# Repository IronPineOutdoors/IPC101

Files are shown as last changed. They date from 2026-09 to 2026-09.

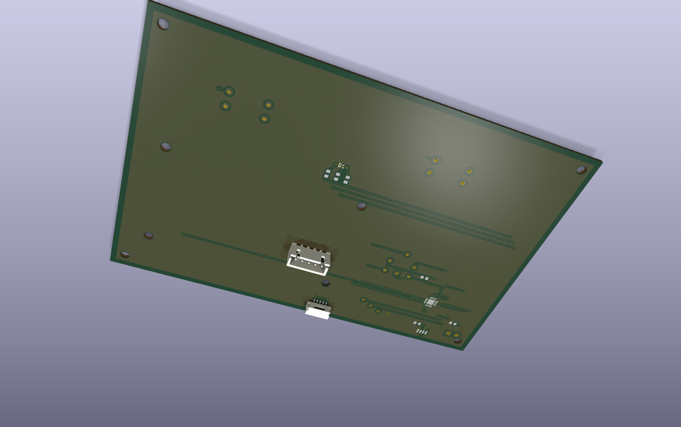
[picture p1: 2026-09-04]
hardware/kicad/IPC101_RevC_3D.png

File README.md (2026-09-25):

# Iron Pine Outdoors IPC-101

IPC-101 is a prototype operator-control-panel PCB for IPC-100. Revision P0 implements seven ordinary controls through a TCA8418 keypad scanner on IPC-100's protected 3.3 V J10 I2C expansion branch, physically carries the Hosyond 2.42-inch SSD1309 prototype display connected by a dedicated five-wire harness to IPC-100 J6, and carries the normally-closed STOP contact only on a separate J8A harness.

## Release state

**Rev C prototype fabrication package corrected for solder mask.** Use [IPC101_RevC_MaskFix_Gerbers.zip](hardware/fabrication/IPC101_RevC/IPC101_RevC_MaskFix_Gerbers.zip) and the existing Rev C BOM/CPL. The superseded package omitted through-hole solder-mask openings; the replacement contains verified top and bottom openings. Full KiCad DRC passes with 0 violations and 0 unconnected pads. See [order notes](hardware/fabrication/IPC101_RevC/ORDER_NOTES.md) and [verification results](hardware/fabrication/IPC101_RevC/MASK_FIX_VALIDATION.md).

The Rev C board is 150 x 100 mm. Physical control/display/faceplate fit remains a prototype acceptance check; the bare PCB has no ingress rating.

## Architecture

- START, PULL: Omron B3F-4055 12 mm through-hole tactile switches.
- Navigation: Adafruit 504 five-way through-hole switch (LEFT/RIGHT/UP/DOWN/SELECT).
- STOP: Omron A22NE-M-PD01-N, normally-closed contact, panel mounted; its two wires remain isolated from PCB logic and pass through dedicated connector J3.
- Key scanner: TI TCA8418RTWR at fixed I2C address `0x34`, polled by IPC-100; 7x1 matrix.
- Display: Hosyond 2.42-inch 128x64 I2C SSD1309 module (Amazon ASIN B0G2RFLG1L), mounted to the faceplate using the corrected Crosswind geometry and connected through IPC-101 J2/J4 to IPC-100 J6.
- IPC-100 ordinary-control link: J10, JST GH 4-pin, 3.3 V / 100 mA / 100 kHz I2C.

## Next-board planning

[IPC-101 Rev 2 planning notes](docs/requirements/IPC101_REV2_PLANNING.md) capture BME280 support, corrected 504 pin alignment, rear input-connector evaluation, direct PCB-mounted OLED, and complete silkscreen/board identification. This is a requirements backlog; current fabrication files are unchanged.

## Repository map

- `docs/` — controlled requirements, decisions, interfaces, mechanics, and test plan.
- `hardware/kicad/` — KiCad project, schematic, routed PCB, and project-local footprints.
- `hardware/bom/` — prototype BOM.
- `hardware/fabrication/` — release notes and generation instructions; verified Gerbers, drills, and assembly outputs are included.
- `mechanical/` — panel coordinate and cutout data.
- `manufacturing/` — assembly and inspection notes.

## Next action

Prepare for the incoming boards with the [Rev C arrival and first-power checklist](docs/testing/IPC101_REVC_ARRIVAL_CHECKLIST.md). It covers the actual order comparison, hand-installed parts, Rev D/Rev H mechanical fit, TPU coupons, harness verification, staged power-up, and result recording. Receipt and acceptance of the replacement manufacturing file must be confirmed against the order; the local package alone does not establish what was fabricated.

Upload the replacement Gerber ZIP to the held JLCPCB order and confirm both solder-mask layers in its viewer. Review assembly orientation before approving production, then fit-test and electrically validate the first prototype before connecting motion hardware.

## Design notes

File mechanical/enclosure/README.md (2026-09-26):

# IPC-101 enclosure - current Rev I.1 fit build

**Start with [PRINT THESE](PRINT_THESE.md).** The current build uses the rear-entry base and R4 roof. The guide records the export cleanup, retained CAD references and next LED tests.

[Current N1.4 faceplate: 8 mm P504 opening, compact tree + IPO and preview](faceplate/REV_N14_FACEPLATE.md).

- [Assembly order, hardware and fit measurements](structure/REV_I1_ASSEMBLY.md)
- [I1 structure/service preview with earlier faceplate](structure/RevI1_preview.png)
- [Measured R1 labeled caps (guide shows earlier N1.2 faceplate)](controls/buttons/R1_BUTTON_CAPS.md)
- [Tree traced from supplied wordmark and N1.2 reprint files](faceplate/history/REV_N12_FACEPLATE.md)
- [Current panel/cap preview](faceplate/N14_faceplate_preview.png)
- [N1 button alignment and tree correction basis](faceplate/history/REV_N1_FACEPLATE.md)
- [Historical M4 audit, superseded by physical misalignment report](faceplate/history/REV_M4_FIT_AUDIT.md)
- [Verification results](structure/RevI1_verification.json)
- [Received IDEC STOP switch and mounting measurements](controls/stop/side-pod/STOP_XA1E_BV302R.md)
- [Printable S1 STOP side pod, hardware and assembly](controls/stop/side-pod/STOP_S1_ASSEMBLY.md)
- [S1 STOP installation preview](controls/stop/side-pod/STOP_S1_preview.png)

Status: **TEST-FIT / PHYSICAL VALIDATION PENDING**. I.1 reuses the original R3 carrier and unchanged Rev H bracket/wiring plate. N1.4 uses measured ARM-left/PULL-right positions, compact traced tree + IPO, and an enlarged 8 mm P504 opening, with labels on R1 caps. Cradle dry fit and STOP coupon operation were reported successful; N1.4 directional travel, R1 cap operation, populated-board/harness, hardware and sealing checks remain.

## Current files versus history

Current I.1 parts, original R3, N1.4/R1 print files (earlier faceplates retained as history), and the authoritative Rev H mounting baseline are grouped by component in the subfolders below. **The Rev H and older I.1 box geometry are references.** Print the rear-entry base from the current guide when replacement is needed.

Superseded Rev G and Rev I exports, exploratory H/H1/H2 SCAD files, and their notes are under [archive](archive/README.md). They are retained for engineering history, not current printing. The earlier long README is preserved as [development history](archive/DEVELOPMENT_HISTORY.md).

Some older Python files remain in `tooling/` because the current build imports their geometry helpers, STL writer, or verification functions. Their presence does not make their old parts current:

- `generate_rev_h.py`: authoritative preserved mount geometry.
- `generate_crosswind_control_box.py`: shared STL writer; its historical Rev G command exports into the archive.
- `generate_rev_i.py`, `verify_rev_i.py`, `preview_rev_i.py`: retained baseline/helpers; historical Rev I exports and preview use the archive.

## Generate and verify the current assembly

```powershell
python -B mechanical/enclosure/tooling/generate_rev_i1.py
python -B mechanical/enclosure/tooling/verify_rev_i1.py
python -B mechanical/enclosure/tooling/preview_rev_i1.py
```

Dependencies: Python, manifold3d, numpy and trimesh. `INSTALLED` files share assembly coordinates; use the guide's `PRINT` files in the slicer. Archive cleanup changes file organization only, not current print geometry.

## Integrated top STOP development

[Current roof R4: rotated release access and simplified coupon](controls/stop/top-mounted/TOP_STOP_R4.md). Insertion fit is confirmed; R3 release was difficult. The user reports the R4 coupon fit is perfect and the roof is printed. The completed coupon exports have been retired; full clamp-up remains to be checked. Use the rear-entry base.

[Removable roof R1 fit prototype, preview and coupon-first instructions](controls/stop/top-mounted/TOP_STOP_R1.md). Requires its matching replacement base; physical fit and sealing remain pending.

## Rear harness entry development

[Rear tunnel R1: bore ring, bracket, plywood collar and matching base](mounting/rear-tunnel-r1/README.md). Preserves the sliding mount, with front-access manual disconnect. The bore ring passed and the bracket/collar/base are printed; actual harness motion and weather sealing remain unverified.

## Folder guide

- `structure/`: I.1 box, cradle and bezel; print and assembly-view exports.
- `faceplate/`: current N1.4 faceplate; earlier revisions in `faceplate/history/`.
- `carrier/`: original R3 carrier.
- `mounting/`: Rev H bracket, wiring plate and reference box.
- `controls/`: buttons, navigation fit coupon, LED tests, and STOP concepts.
- `branding/`: artwork and branding studies.
- `tooling/`: generation, preview and verification scripts; `artifact_paths.json` maps their outputs.
- `archive/`: superseded enclosure designs and development history.

## Preserved mounting and development guidance

The synced Rev H bracket and mating T-slot receivers remain the mounting baseline, not the exploratory H/H1/H2 test models. Preserve this interface unless physical testing identifies a problem; the rear-tunnel variant documents its local pin-bore correction. Keep the PCB/panel cassette removable without disturbing the fixed bracket, verify the provisional 16.5 mm faceplate-back to PCB-top spacing with actual components, and keep bosses clear of the populated stack. Historical Rev H construction instructions remain in [development history](archive/DEVELOPMENT_HISTORY.md); use the current component guides for print orientation and hardware.

Record confirmed measurements, physical feedback, superseded assumptions and design decisions alongside source and revision-marked exports. Distinguish concepts, fit prototypes, physical validation and released designs.

## Physical checkpoint - 2026-09-26

The user reports the R4 STOP coupon fit is perfect and the R4 roof, rear-tunnel bracket, collar and rear-entry base are printed. The base sidewall broke during support removal; the user reports that it remains usable for all fit tests but cannot serve as the completed sealed enclosure. Retain it for dry assembly and harness-motion checks before printing a replacement. Full screw clamp-up, wired removal motion and sealing are not yet confirmed.

Next small print: [clear LED bubble 2 and the panel-hole strip](controls/led/LED_R1_TEST_PRINTS.md). These establish fit and optical appearance, not final LED retention or sealing. The current PCB LED holes do not accept the received leads; see the [Rev 2 requirements and current-board workaround](../../docs/requirements/IPC101_REV2_PLANNING.md). Rev 2 is to carry the LED and other front-panel electronics directly on the PCB; clear-lens tests do not change that direction.

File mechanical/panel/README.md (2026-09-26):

# Rev D OLED fit correction

> Historical design: superseded print exports were removed on 2026-09-26. Use `mechanical/enclosure/PRINT_THESE.md` for the current assembly; recover historical exports from Git or regenerate them.

For the next enclosure fit trial, print **`CrossWind_ControlPanel_RevD_OLED_8mm_Right_IPC101.stl`**. This addresses the reported OLED collision with the enclosure's left sidewall by shifting the display window and all four OLED mounting holes 8 mm right as viewed from the front.

- Faceplate remains 150 x 100 x 2 mm; its four enclosure mounting holes are unchanged.
- OLED centre: (54.5, 63.5) mm. Window remains 57 x 28 mm.
- OLED hole centres: X=20.1/88.9 mm, Y=44.1/82.9 mm; hole diameter 3.2 mm.
- ARM/PULL, navigation, LED and existing engraved branding remain unchanged.
- This is only the OLED fit correction. The illustrated swoosh-logo/STOP concept has not been incorporated into this STL.
- Manufactured PCB geometry is unchanged. OLED mounting holes on that PCB remain at the old location; the shifted OLED mounts to the faceplate and uses its harness, not a forced alignment to the PCB's old OLED holes.

Run `python mechanical/panel/generate_ipc101_rev_d.py` from the project root. Rev D reuses the Rev C faceplate builder with an explicit OLED centre; the Rev C generator retains its original default and historical exports. `IPC101_RevD_FACEPLATE_COORDINATES.csv` is faceplate-only and does not supersede PCB fabrication coordinates.

Geometric checks passed: one valid connected solid; exact panel bounds; four display and four enclosure mounting holes open; window open; zero faceplate overlap with Rev H shell. The nominal 73 x 43 mm OLED PCB envelope ends at X=91 mm, leaving 5 mm to the 18 mm navigation-cap envelope. A 1.6 mm thick OLED board envelope clears the Rev H shell at tested rear offsets of 3, 5, 10 and 15 mm. These are envelope checks, not a verification of the actual OLED glass, connectors, screws, standoffs or full controller-PCB stack. Fit the actual assembly before tightening the faceplate.

---

# IPC-101 Rev C Control Panel

The Rev C mechanical set replaces the Crosswind Rev B encoder layout with the IPC-101 operator layout while retaining the verified 150 x 100 mm panel envelope, corner fasteners, ARM/PULL centres, and OLED hole spacing.

Generated files:

- `CrossWind_ControlPanel_RevC_IPC101.stl`
- `CrossWind_Tactile_Button_Cap_RevC_IPC101.stl`
- `CrossWind_Adafruit504_Nav_Cap_RevC_IPC101.stl`

Run `python generate_ipc101_rev_c.py` to regenerate the models. Dimensions are millimetres. Viewed from the recessed-logo/front surface, the OLED is on the operator's left, the Adafruit 504 navigation control is on the right, ARM and PULL are below, and the RGB indicator aperture is centred between the buttons and display row. The D-pad aperture is 8.0 mm for added cap clearance.

Use `CrossWind_ARM_Button_Cap_RevC_IPC101.stl` and `CrossWind_PULL_Button_Cap_RevC_IPC101.stl` for the installed controls. They retain the verified generic tactile-cap fit and add 0.45 mm raised lettering on the operator-facing surface. `CrossWind_Tactile_Button_Cap_RevC_IPC101.stl` remains available as an unlabeled spare.

The Adafruit 504 navigation cap uses the proven TrailBoss P504 receptacle: a 3.30 x 3.30 mm square socket, 3.50 mm deep, with a 1.80 mm face floor. Its 5.0 mm rear hub clears the faceplate's revised 8.0 mm opening.

The power-switch region is reserved but is intentionally not cut until its exact rated part and mounting geometry are selected. Print a faceplate and both caps for fit verification before production fabrication.

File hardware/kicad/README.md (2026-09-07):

# IPC-101 Rev C KiCad Source

This directory contains the fabrication-oriented Rev C operator-control board for the Crosswind control-panel replacement.

## Rev C layout

- Board outline: 150 x 100 mm, matching the Rev C faceplate.
- OLED: left-side 2.42-inch Hosyond/SSD1309 mechanical pattern. The display mounts to the faceplate and plugs into IPC-101 J2; J4 carries the same isolated five-wire branch to IPC-100 J6 (`OLED_VCC`, `GND`, `SDA`, `SCL`, `RESET`).
- Navigation: Adafruit 504 five-way switch at the right side of the display row.
- Lower controls: ARM at left and PULL at right.
- Indicator: PCB-mounted 5 mm common-anode RGB LED centered between the lower controls and display row.
- Power-switch region: mechanically reserved only; no cutout or footprint is committed until the rated switch is selected.

The IPC-101 board connects to IPC-100 through J1 for keypad `+3V3`, `GND`, `SDA`, and `SCL`, through J4 for the dedicated OLED branch, and through J3 for isolated STOP. J2 is the local OLED harness output. The J2/J4 copper pass-through does not join the J1 keypad branch.

## Electrical implementation

- U1: TCA8418 keypad/GPIO controller in TI RTW-24 QFN.
- SW1: ARM; SW2: PULL; SW3: LEFT/RIGHT/UP/DOWN/SELECT.
- D1: 5 mm common-anode RGB LED.
- R2/R3/R4: 1 kOhm current-limiting resistors.
- RGB GPIO assignment: COL6/pad 15 red, COL7/pad 16 green, COL8/pad 17 blue.
- Two copper layers with 0.20 mm signal tracks, 0.15 mm clearance, and 0.50/0.30 mm vias.
- F.Cu `+3V3` plane and B.Cu ground plane with explicit island stitching.

`generate_rev_c_pcb.py` reproducibly rebuilds the placed and routed geometry from the embedded footprints. Run it with KiCad's bundled Python, then refill zones and rerun DRC if any placement or routing is edited interactively.

## Validation

- `IPC101_DRC.rpt`: full KiCad DRC, 0 violations and 0 unconnected items.
- `IPC101_ERC.rpt`: KiCad error-level ERC, 0 violations.
- `IPC101_RevC_3D.png`: top-side KiCad render for placement review.
- `IPC101_RevC.net.xml`: exported schematic netlist for parity/review tooling.

Before ordering a production quantity, print the Rev C faceplate and both caps, assemble one PCB, verify the Adafruit 504 physical pin orientation, and continuity-check both OLED harnesses against the received module and the documented J2/J4 pinouts.

## Solder-mask correction (2026-09-07)

The 29 PTH component pads now explicitly include both F.Mask and B.Mask. Copper routing and drill geometry are unchanged. `generate_rev_c_pcb.py` restores these layers for cloned as well as newly created PTH pads. Use the replacement `IPC101_RevC_MaskFix_Gerbers.zip`; the earlier package had an empty bottom mask and omitted top openings for the PTH pads. The fabrication export script audits source pad layers and every solderable pad centre in the archived mask files.

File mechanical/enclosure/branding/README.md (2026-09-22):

# Tree traced from supplied Iron Pine artwork

`iron_pine_transparent_wordmark.png` is an unchanged copy of the user-supplied file from `Crosswind/branding/iron-pine/`. The other supplied mockup sheet and small reference image were visual references; the transparent wordmark supplies the geometry.

`trace_tree.py` selects the main tree and its separate center triangle from the alpha channel. It excludes adjoining letters and OUTDOORS. This preserves the original swept branches, open central channel, small center triangle, asymmetric raster outline and aspect ratio. It does not substitute a generic pine or a font glyph.

The trace removes isolated raster pinholes of at most 4 square pixels and simplifies the pixel staircase with 0.7 pixel tolerance. `tree_trace_verification.json` records the source SHA-256, crop, seed pixels, threshold, approximately 98.9% silhouette intersection-over-union and maximum boundary deviation under 0.085 mm at the final print size. These compare the vector with the thresholded source alpha, not with an unavailable original vector master.

Outputs:

- `iron_pine_tree_trace.svg`: editable vector silhouette in source-pixel coordinates.
- `iron_pine_tree_trace.scad`: normalized polygon paths, height 1 and bottom Y=0.
- `iron_pine_tree_unit.stl`: closed two-component extrusion of the same trace, thickness 0.55 mm. N1.2 imports this mesh to avoid OpenSCAD 2021's failed triangulation of the detailed raster contour. It is a source dependency; keep it beside the SCAD/SVG.

The faceplate scales the tree to 13.26 mm high and approximately 14.33 mm wide, retaining its source aspect ratio. The tree remains separated from the existing OUTDOORS text. Very fine tapered tips can be shortened by a 0.4 mm nozzle; inspect the sliced first layers rather than thickening the brand shape without evidence.

Regenerate with `python -B mechanical/enclosure/branding/trace_tree.py`. Requires numpy, scipy, shapely, pymupdf and the project's manifold3d/STL helper. No source image is modified.

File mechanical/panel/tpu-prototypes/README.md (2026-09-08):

# TPU button diaphragm test set

Purpose: compare printed 95A TPU flexibility for ARM/PULL and P504 before committing to final faceplate boots. These are standalone bench coupons, not drop-in sealed caps. No existing faceplate, enclosure, or PCB has been modified.

## First print

Start with `ARM_PULL_TPU_WEB_0.6mm.stl` in TPU and **two copies** of `ARM_PULL_CLAMP_FRAME_RIGID.stl` in rigid filament. Print the TPU flat as exported: smooth continuous skin on the bed, raised central actuator-contact pad upward. Suggested experimental layer height is 0.2 mm, giving 2/3/4 layers for the 0.4/0.6/0.8 mm webs. Inspect the slicer to ensure the skin is fully filled with no gaps; use a conservative profile appropriate to the actual TPU. Ordinary TPU feeds from the A1 external spool, not AMS Lite. Follow filament-maker drying guidance.

Clamp the 1.2 mm thick outer flange between the two matching rigid frames using four M3 bolts, washers and nuts. M3 x 12 mm is a starting candidate; confirm engagement with your washers/nuts. Tighten evenly without distorting the flange. Hole centres are (4,4), (40,4), (4,34), (40,34) mm; holes are 3.4 mm. Overall coupon is 44 x 38 mm. Frames are 3 mm thick, with flat flange contact. This fixture is independent of the actual panel mounting holes; do not drill your faceplate to this pattern.

ARM/PULL uses a 15.2 x 10 mm central reinforcement and 26 x 20 mm frame opening. P504 uses an 18 mm cross reinforcement and 26 mm circular opening. Both have a 1 mm added central thickness on the actuator side; no switch socket is provided. Use the matching frame style. The central pad faces the actuator in eventual use, opposite the user's finger. Flat webs are an initial compliance experiment; final boots may need a formed fold or dome for lower force.

## Compare

- Press centrally, then near each edge; compare 0.4, 0.6 and 0.8 mm samples.
- Check that the membrane returns completely, does not rub the frame, and does not crack or whiten around the reinforcement.
- For P504, compare all four directions and centre pressing; without a supported coupling this does not establish switch actuation.
- Record preferred feel, print defects and any permanent deformation after repeated pressing. Use consistent conditions to compare samples.
- After the PCB spacing is known, test with the real switches for required travel, operating force, return and absence of preload. TPU does not replace guided rigid plungers or the P504 shaft coupling.

Do not place a boot over the IDEC STOP actuator. These samples are not waterproof-qualified seals; layer integrity, flange compression, fatigue and actual assembled leakage remain unverified. The 44 x 38 mm fixture envelope is not the proposed final boot footprint and has not been checked against adjacent faceplate controls or OLED clearance.

Run `python mechanical/panel/tpu-prototypes/generate_tpu_prototypes.py` from the project root (requires manifold3d). All eight generated meshes passed solid-status, connected-body, positive-volume and open-bolt-hole checks. Test thicknesses represent candidates, not measured performance predictions.

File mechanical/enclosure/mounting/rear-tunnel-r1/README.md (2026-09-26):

# Rear harness tunnel R1 ? fit prototype

> Export cleanup, 2026-09-26: superseded print links below are historical. Use `mechanical/enclosure/PRINT_THESE.md` for current parts. Source and Git history retain regeneration/recovery information.

[Three-view preview](REAR_TUNNEL_R1_preview.png) ? [CAD verification](REAR_TUNNEL_R1_verification.json)

The bracket now carries a stationary tunnel through the CrossWind alpha base's nominal 1/2-inch (12.7 mm) plywood wall. A removable rear collar overlaps the sleeve and sandwiches the wall. The enclosure retains its upward sliding mount and lifts away from the tunnel. The matching enclosure base closes the original bottom wiring port and adds a 52 mm rear opening; it retains the top STOP roof R1 attachment geometry.

## Confirmed design inputs

- User's existing 12-way DT-style pair: 41 mm wide, 22.16 mm high, approximately 73 mm long **when connected**. The user reports plenty of clearance through the printed 50 mm bore ring; retain the 50 mm bore. The rectangular cross-section diagonal is 46.605 mm.
- Three board branches total 11 positions: keypad 4, OLED 5, isolated STOP 2. One position remains spare; no pin assignment or wiring release is made here.
- Access inside the base requires removing the thrower deck. Routine disconnect must therefore be reachable from the front after undocking the control box.
- Roof locator coupons slide together well, per user. M3 x 30 clamp-up is untested because the user does not yet have screws that long.

## Bore fit confirmed

50 mm bore test ring (retired export; recover from Git history): 56 mm outside diameter, 50 mm clear bore, 6 mm thick. Print flat. Pass both unplugged connector halves through it with the latch untouched; also try the connected pair. It should pass without forcing or scraping. This tests cross-section only, not harness bend radius or removal motion.

**Physical feedback:** the user reports "plenty of clearance" through the printed ring. The connector passage fit is accepted; this does not verify the wired service loop during removal.

**Do not cut the plywood yet.** The proposed hole is 58 mm for a 56 mm sleeve, subject to actual wall thickness and a physical harness-motion mock-up. Next, trial-fit the bracket and collar and check the actual harness through the full slide-and-pull motion.

## Prototype parts

| Part | Print file | Notes |
|---|---|---|
| Bracket with tunnel | [Bracket](CrossWind_IPC101_Rear_Tunnel_Bracket_R1_PRINT.stl) | Replaces Rev H bracket; existing rail placement retained. Rail faces down in export; slicer supports are required beneath the plate and must not damage sliding faces. |
| Rear retaining collar | [Collar](CrossWind_IPC101_Rear_Tunnel_Collar_R1_PRINT.stl) | Flange down, sleeve upward. 56.6 mm socket overlaps the 56 mm tunnel. |
| Rear-entry enclosure base | [Base](CrossWind_IPC101_Rear_Tunnel_Base_R1_PRINT.stl) | Replaces the top STOP R1 base; old floor port and plate holes closed. Reuse the [R1 roof](../../controls/stop/top-mounted/TOP_STOP_R1.md). |
| Plywood layout stencil | [Template](CrossWind_IPC101_Rear_Tunnel_Wall_Template_R1_PRINT.stl) | 58 mm center opening and 50 x 50 mm screw-center pattern. Prototype dimensions only. |

The tunnel center is X78/Z50 in installed assembly coordinates, i.e. centered across the 140 mm bracket and 45 mm above its lower edge. The sleeve runs from Y-39 to Y-10.5, stopping 10.5 mm behind the enclosure rear plane. It does not enter or interlock with the moving box.

Nominal wall faces are Y-15 and Y-27.7. The rear collar bears at Y-27.7 and its flange is 4 mm thick. Four provisional M3 x 25 socket screws enter from inside the base, through the collar and wall into M3 nuts held in bracket-front hex pockets. Their 50 x 50 mm pattern is centered on the tunnel. Drill the four screw holes to provide clearance (modeled as 4 mm in plywood), not as threaded plywood holes. Load the nuts before installing the bracket. Retain the existing bracket mounting holes for enclosure loads; the collar screws clamp the passage. Recheck lengths if adding washers or a gasket.

The collar can slide along the sleeve before clamping, but the modeled assembly is checked only at nominal 12.7 mm wall thickness. Measure the actual wall and trial assemble before installing. A face gasket and rear opening seal remain to be designed; do not infer an ingress rating from the overlap.

## Service-loop layout and required physical check

1. During initial assembly, route the base-side harness through the tunnel. Put its strain relief deeper inside the base, leaving a free service loop between the anchor and connector. Establish loop length from the actual lift-and-pull motion; no numerical loop length has been validated.
2. Keep the connector behind the plywood while docked. The space between box and bracket is for flexible wires, not the 73 mm connector body.
3. To remove the box, release the pin and lift it approximately 70 mm. The harness must slide and bend freely while the rear opening moves upward past the fixed tunnel.
4. Once the rails disengage, bring the box forward and draw the connector through the tunnel, then unplug it from the front. Keep the base-side end accessible for reassembly.

**The unresolved fit is the wired bundle in the rear gap during the upward slide.** Rigid CAD clearance is not proof that wires will bend without pinching. Mock up the 10.5 mm tunnel-mouth-to-box spacing with the actual wire bundle; if it binds or requires a tight bend, revise the rear entry before a full enclosure print. Check internal board clearance and routing as well; the PCB model does not contain populated components.

## Verification

The generated report records 204 interference checks: nominal plywood and fasteners; centered connector passage; 71 box slide positions; 66 cassette positions; 51 roof positions. All eight STL exports are connected, watertight, consistently wound and fit a 256 mm cube.

The original bracket's retaining-pin bore was exactly tangent to a rail edge, producing a non-manifold STL seam. R1 adds 0.1 mm radial relief there (3.6 mm cutter versus 3.4 mm). All other rail geometry is checked against Rev H. Check the retaining pin on the printed bracket; this is not a load or retention qualification.

Regenerate:

```powershell
python -B mechanical/enclosure/tooling/generate_rear_tunnel_r1.py
python -B mechanical/enclosure/tooling/preview_rear_tunnel_r1.py
```

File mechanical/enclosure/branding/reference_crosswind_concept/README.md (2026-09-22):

# Supplied CrossWind artwork on faceplate

Visual study requested 2026-09-22. Uses the supplied crosswind_transparent_logo.png alpha silhouette, retaining the actual slanted lettering and swept forms. The preferred upper-left stacked tree branding remains. CrossWind is 58 x 13.176 mm, placed 78 mm from the left and 3 mm from the top.

[Faceplate preview](faceplate.png) / [CrossWind detail](crosswind_detail.png). The source PNG is preserved unchanged with SHA-256 in trace_report.json. Trace uses alpha >180, discards components under 100 pixels and pinholes up to 4 square pixels, and simplifies by 0.7 pixel. Silhouette intersection-over-union is 0.991. Metallic shading is flattened into a monochrome inlay concept; fine tapered ends still need printability review before CAD release.

Regenerate with `python -B mechanical/enclosure/tooling/preview_reference_crosswind.py`. Uses the previous stacked_brand_wind_concept/faceplate.svg for the panel and approved tree layout. Production SCAD/STLs remain unchanged. The LED hole remains the N1.4 5.2 mm reference pending bubble tests; cap outlines are schematic, with shaft shortening pending physical measurements.

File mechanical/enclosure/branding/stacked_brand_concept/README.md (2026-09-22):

# Upper-left stacked brand concept

Visual study requested 2026-09-22: actual traced tree with Iron, Pine and Outdoors on separate lines to its right. Text steps outward with the branches. Tree height 18 mm, tip 3 mm from top, center X14 mm; text size 4 mm. Mounting-hole centers, 8 mm P504 aperture and ARM/PULL centers follow N1.4. Caps are schematic front outlines. Arial typography is a visual approximation of the production Liberation Sans font; this is not a manufacturing export or print-quality validation.

[Full faceplate](faceplate.png) / [Logo detail](logo_detail.png). Editable SVGs accompany both images. Regenerate with `python -B mechanical/enclosure/tooling/preview_stacked_brand.py` (PyMuPDF required).

N1.4 production SCAD/STLs and print recommendations remain unchanged pending visual feedback.

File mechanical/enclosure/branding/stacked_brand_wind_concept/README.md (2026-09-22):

# Stacked tree with open CrossWind gusts

Visual revision requested 2026-09-22. Preserves the preferred upper-left tree and stacked Iron/Pine/Outdoors. Replaces the enclosing polygon lines with two short curved gusts to the left of CrossWind, leaving the wordmark open above, below and to the right. Stroke width 0.9 mm in panel coordinates.

[Faceplate](faceplate.png) and [CrossWind close-up](crosswind_detail.png). Editable SVGs included. Regenerate using `python -B mechanical/enclosure/tooling/preview_stacked_brand_wind.py`.

This is a visual concept using N1.4 hole coordinates, schematic cap outlines and Arial approximating production Liberation Sans. Production SCAD/STLs remain unchanged. LED opening still shows 5.2 mm pending bubble fit tests; button shaft shortening remains pending measurements. Actual printed detail quality has not been validated.

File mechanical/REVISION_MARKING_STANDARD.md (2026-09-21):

# IPC-101 Mechanical Revision Marking Standard

Status: **ACTIVE DEVELOPMENT STANDARD**  
Established: 2026-09-20

Physical prototype parts should carry a human-readable part/revision mark whenever there is enough non-cosmetic surface area. This is intended to prevent similar prototype prints from being confused during fit testing.

## Format

Preferred full marking:

`IPC101-[PART]-[REV]`

Examples:

- `IPC101-P504-R4.9`
- `IPC101-CARRIER-R1`
- `IPC101-ENC-RH`
- `IPC101-FP-N1`

For small parts, use the shortest unambiguous marking, for example:

- `P504 R4.9`
- `N1`
- `LED R1`

Use `TEST` where practical for intentionally non-final fit-check parts, e.g. `P504 R4.9 TEST`.

## Placement

Revision marks belong on hidden/non-cosmetic surfaces:

- Faceplate: rear surface
- Enclosure: inside or bottom
- PCB carrier/chassis: unused rail or underside
- P504 pedestal: underside
- LED holder: rear/underside
- ARM/PULL caps: underside if sufficient printable area

Do not place engineering revision text on the visible operator face unless specifically required.

## Print geometry

For FDM prototype parts, start with approximately **0.3–0.5 mm recessed/embossed depth** and use lettering large enough to print reliably with the current 0.4 mm nozzle. Increase text size or simplify the mark rather than creating fragile fine lettering.

Revision marking must not weaken a load-bearing wall, sealing surface, snap feature, heat-set-insert boss, fastener land, or tight-tolerance mating surface.

## Revision handling

- Change the physical revision mark whenever geometry changes in a way that affects fit, function, assembly, or testing.
- Cosmetic-only slicer changes do not require a CAD revision unless they alter the physical part.
- Do not reprint already validated parts solely to add a revision mark.
- CAD/source, exported STL and documentation should use matching revision identifiers.
- Record physical validation results in the repository before calling a geometry **FROZEN**.
- Keep superseded files identifiable; do not silently overwrite a prior tested revision with different geometry.

## Prototype vs production numbering

The current R/N-style identifiers are development revisions, not final Iron Pine Outdoors production part numbers. A formal production part-number system will be established later when assemblies approach production-candidate status.

## Current application

Apply this standard beginning with the next generated revisions of:

- P504 pedestal/retainer
- IPC-101 carrier/chassis
- redesigned enclosure
- N.1 faceplate
- LED lens/holder
- ARM/PULL button caps

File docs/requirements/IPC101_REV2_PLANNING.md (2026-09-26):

# IPC-101 Rev 2 planning notes

Recorded 2026-09-25 from user direction. This is the next-board requirements backlog, not a released PCB revision or authorization to fabricate. Current KiCad/Rev C fabrication files are unchanged. "Rev 2" is the user's next-board designation; assign the formal fabrication revision consistently before release.

## System context

IPC-101 replaces the improvised Alpha panel now, connected to the existing ESP32; IPC-100 is still in development and is a later host. Build a new Alpha harness instead of assuming the old panel harness is directly compatible. The Crosswind repo contains the Alpha firmware and adapter plan: GPIO21 SDA, GPIO22 SCL, GPIO5 OLED reset, OLED and BME280 on the shared bus. IPC-101 keypad/RGB firmware migration and STOP integration remain separate unfinished work. Do not apply IPC-100-only interface assumptions to Alpha without reconciliation.

## Requested board changes

**Mounting direction confirmed 2026-09-26:** Rev 2 should carry the front-panel electronics on the PCB as one aligned assembly: ARM/PULL switches, navigation switch, RGB LED and OLED. Use component selection, accurate footprints and a coordinated PCB-to-faceplate height to avoid separate faceplate-mounted electronic components, flying leads, LED harness connectors, and individual printed retainers/brackets. The faceplate provides openings and access; establish component alignment and support from the PCB. Necessary OLED supports should attach the module to the PCB assembly. The LED pigtail/faceplate-retainer discussion applies only to salvaging the current board, not to the Rev 2 design.

Check the mounting stack with actual components before layout release: LED projection and support, OLED window position/height, navigation travel and ARM/PULL free play must work at the same PCB-to-faceplate spacing. Do not rely on long unsupported LED leads to establish height or carry panel loads. Preserve the existing roof-mounted STOP arrangement pending an explicit redesign; this front-panel integration requirement does not silently relocate the received STOP switch or change its circuit. Prefer PCB-mounted BME280 integration where ambient sensing can be preserved; document any need for remote placement before choosing it.

| Item | Rev 2 direction | Evidence or decisions needed before layout release |
|---|---|---|
| BME280 support | Add an explicit electrical connection and planned physical accommodation for the BME280. Avoid an undocumented external SDA/SCL splice. Label power, ground, SDA and SCL clearly. | Confirm actual breakout dimensions, pin order, mounting holes, voltage interface, address and pull-ups. Decide whether the sensor mounts on IPC-101 or uses a dedicated remote connector; preserve useful ambient airflow and avoid enclosure/board heat bias. Reconcile Alpha shared-bus operation with future IPC-100 connections. |
| Adafruit 504 / SW3 | Correct the reported pin alignment in the PCB footprint. | Measure the received switch's six pins, row spacing, offsets and orientation against the current board. Confirm center/common and all five directional/select mappings by continuity. Do not substitute a generic footprint or assume this is only a faceplate-hole issue. Check PCB footprint, actuator center and panel opening together. |
| RGB indicator / D1 lead fit | Mount the LED directly on the PCB with defined height and mechanical support; align it to the faceplate without a separate wired LED or faceplate retainer. Correct the undersized lead holes and review pad dimensions, pitch, mask clearance and routing together. Retain a common-anode RGB indicator unless the driver circuit is explicitly revised. | User reports empty holes do not admit the received LED leads, measured approximately 0.5 mm. Lead cross-section is unconfirmed. Rev C D1 has four 0.60 mm drill calls and 1.00 mm pads at 1.27 mm pitch; exported PTH file agrees. Select the exact LED, size finished holes from maximum lead cross-section/diagonal plus assembly and fabrication tolerance, and verify annular rings/spacing with the fabricator. Do not release a larger drill alone in the existing pads. |
| Input connector at rear | Evaluate moving/orienting the input connector(s) onto the rear face of the PCB to receive the harness arriving through the rear tunnel. This is a candidate layout change, not a frozen position. | Clarify rear face versus rear board edge in assembly coordinates. Check mating direction, connector height, latch access, cable bend/strain relief, R3 carrier and cradle clearance, populated-board access and full slide/removal travel. Keep the required STOP connection distinct; consolidation is not automatically approved by this mechanical note. |
| Direct-mounted OLED | Orient and position the OLED header so the received Hosyond SSD1309 module can mount directly to IPC-101, like the buttons, 504 and LED, rather than relying on the present faceplate-to-board display harness. | Measure actual module header pitch, pin order, direction, module outline and four mounting holes. Confirm module front/back orientation and required reset connection. Choose mating-header type and standoff height to align the screen with the faceplate. Support the module mechanically with standoffs/fasteners; do not make the electrical header carry panel loads. Check display removal, solder access and clearance against adjacent controls. |
| Complete silkscreen / stencil identification | Every component receives a readable reference designator. Add useful functional labels for controls and connectors; mark pin 1, polarity and orientation where applicable. Add pin/function legends where space allows, including BME, OLED/reset and isolated STOP. | Review top and bottom silkscreen against assembled hardware, solder-mask openings and fabrication minimums. Connector legends must match the released pinout and viewing direction. Include an assembly drawing when parts obscure their own references. |
| Board identity and branding | Add the approved Iron Pine/CrossWind logo and the IPC-101 part number on the PCB, plus the released revision identifier. | Choose approved vector artwork and exact part-number/revision format; verify legibility at actual size. Keep logos/text off pads, holes, component keepouts and mating surfaces. |

## Related physical feedback to carry forward

- LED fit, 2026-09-26: the user confirms the four holes are empty and the leads do not enter at all. Approximately 0.5 mm square leads would have a 0.707 mm diagonal, explaining interference with a 0.60 mm hole, but square leads are only a hypothesis. Actual finished-hole diameter and lead dimensions remain to be measured. Do not force leads or drill out plated holes. A prototype workaround is short individually insulated wire extensions that fit the existing holes, with independent mechanical LED support and verified R/anode/G/B mapping; this workaround has not been built or tested.
- ARM/PULL stems: user removed approximately 1.5 mm from PULL and reports good operation. User requests the same reduction for both caps; ARM is not yet physically verified. This is a cap/mechanical correction, not grounds to relocate switches without a complete stack check. Current nominal R1 dimensions imply 8.07 mm stem beyond the rear flange after that reduction.
- Roof R2 accepts the STOP block; R3 adds access to its push-up release. Keep STOP service access in the populated-board and harness assembly review.
- The rear tunnel's 50 mm bore ring passed the user's connector clearance check. Full harness bending and slide-and-pull service motion are not yet validated.
- Direct OLED mounting and rear connector changes can alter the PCB/faceplate/carrier stack. Preserve proven datums where possible and explicitly revise affected enclosure parts if necessary.

## Release checks for the next board

1. Record the actual BME module, 504 pin measurements, OLED connector/mount geometry, RGB LED maximum lead dimensions/pinout and rear harness mating envelope.
2. Establish a dimensioned component-side and rear-side assembly layout, including the populated R3/cradle/faceplate stack and accessible connector latches. Verify the directly PCB-mounted LED, OLED and switches together at the chosen panel spacing, including mounting support, tolerances and control travel; current-board pigtail/retainer workarounds are not the Rev 2 mounting solution.
3. Reconcile Alpha and future IPC-100 power, I2C topology, pull-ups, reset, connector pinouts and separate STOP handling. Document required firmware changes; do not assume hardware wiring alone enables IPC-101.
4. Print a 1:1 PCB layout or mechanical gauge and trial-fit the received 504, OLED and sensor hardware before ordering. Verify LED lead clearance with a suitable hole gauge or footprint coupon; a paper layout alone cannot establish plated-hole fit.
5. Complete schematic/PCB review, ERC/DRC, silkscreen/polarity inspection, and updated BOM, assembly drawings, harness documentation and fabrication revision marking.
6. Bench-check the assembled board, display, BME and each control before motion integration. Physical fit does not establish electrical or firmware acceptance.

## RGB LED candidate and purchasing limits

Candidate for the revised footprint: **Kingbright WP154A4SEJ3VBDZGW/CA**, a 5 mm diffused common-anode RGB indicator. This is not an approved drop-in replacement for Rev C's 0.60 mm holes. No researched alternative has been verified to fit those holes directly. For the existing board, retaining the received LED with insulated wire extensions avoids buying another mechanically incompatible part.

- [Manufacturer datasheet](https://www.kingbrightusa.com/images/catalog/SPEC/WP154A4SEJ3VBDZGW-CA.pdf), revision 7A, reviewed 2026-09-26. Use the full dimension tolerances, package flange and actual pinout when revising the footprint and panel support; do not assume the current R-A-G-B order matches a replacement.
- [DigiKey product listing](https://www.digikey.com/en/products/detail/kingbright/WP154A4SEJ3VBDZGW-CA/6569334).
- Electrical qualification is required: the datasheet gives typical green/blue forward voltage of 3.3 V at 20 mA, so the current 3.3 V circuit cannot be assumed to supply that test current. Check actual indicator brightness at the intended lower current, resistor values, driver sink limits and voltage headroom before selecting this part for release. Do not raise the common-anode supply without reviewing the driver circuit.
- Freeze a manufacturer part number in the BOM and update the footprint/generator, assembly pinout and fabrication outputs together after qualification. Current PCB and fabrication files are unchanged by this planning update.

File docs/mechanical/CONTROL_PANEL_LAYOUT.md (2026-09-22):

# IPC-101 P0 Control Panel Layout

All coordinates are millimeters from the lower-left PCB corner, component/front view. **The 100 x 140 mm outline is PROVISIONAL.**

| Item | X | Y | Panel requirement / note |
|---|---:|---:|---|
| PCB outline | 0–100 | 0–140 | 1.6 mm FR-4 |
| Mount H1 | 5 | 5 | 3.2 mm hole, 6 mm keepout |
| Mount H2 | 95 | 5 | same |
| Mount H3 | 5 | 135 | same |
| Mount H4 | 95 | 135 | same |
| OLED DS1 center | 50 | 27 | Hosyond B0G2RFLG1L; Crosswind fit-print geometry: 73 x 43 mm PCB, four 3.2 mm holes on 68.8 x 38.8 mm centers |
| Navigation SW3 | 50 | 83 | verify sample; allow 24 x 24 finger zone |
| START SW1 | 28 | 55 | B3F-4055 center; cap-dependent opening |
| STOP operator | 72 | 55 | Historical P0 position only; 22.3 mm cutout superseded by received IDEC XA1E-BV302R (16 mm family). Final cutout/placement pending; see [STOP hardware note](../../mechanical/enclosure/controls/stop/side-pod/STOP_XA1E_BV302R.md). |
| PULL SW2 | 50 | 25 | use large/high-contrast cap or overlay target |
| J1 ordinary UI | 50 | 5 | rear/bottom edge access; strain relief required |
| J3 STOP | 82 | 5 | rear; isolated two-wire routing |

Maintain 3 mm copper-to-edge clearance and 6 mm around mounting hardware. DS1 is on IPC-101; its four mounting holes use the corrected Crosswind control-panel fit-print geometry and replace the obsolete small OLED pattern. Confirm orientation and connector clearance with the physical module before fabrication. Target rear clearance is 15 mm plus connector/display cable bend radius. Maximum PCB-mounted height is provisionally 12.39 mm. The tactiles are not weather sealed.

Final panel work must verify cap travel/preload, OLED window and gasket, navigation footprint, anti-glare cover, fastener heads, connector access, and gloved reach. Front hierarchy is OLED, navigation, START/red STOP, then prominent PULL.

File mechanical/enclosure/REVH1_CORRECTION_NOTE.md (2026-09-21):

# Rev H1 correction note

Status: **TEST-FIT / NOT FROZEN**

Rev H was rejected after visual review because:
- the temporary corner stack bosses projected outside the enclosure as visible "nubs";
- the oversized service-opening subtraction removed too much of the lower shell, leaving the underside open.

Rev H1 corrects those issues:
- no external PCB/carrier bosses;
- closed continuous lower/underside shell;
- Rev G rear wood-mount hole pattern and mounting-pad concept retained;
- front opening is limited to the inclined faceplate service opening;
- current ~16.5 mm faceplate-back to PCB-top target remains provisional;
- PCB carrier/chassis will be a separate internal part so the enclosure exterior remains clean;
- a generic connector-cassette opening is reserved on the right rear side, not on the wood-contact mounting plane.

Rev H is superseded by Rev H1 for further mechanical review. Do not print Rev H.

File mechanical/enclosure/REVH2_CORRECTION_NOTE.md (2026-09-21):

# Rev H2 correction note

Status: **REJECTED / DO NOT PRINT**

Rev H1 fixed the open underside and external corner nubs from Rev H, but its generic IPC-101-to-Alpha connector cassette created an awkward external box on the side of the enclosure.

Rev H2 removed that connector cassette and cleaned up the shell, but a second mounting-interface problem was then identified during review: the existing CrossWind mount uses **channels that the enclosure slides/fits into**. Rev H2 preserved only the general Rev G size / internal wood-screw pattern, not the full channel-engagement geometry. Therefore Rev H2 cannot be considered compatible with the existing mount.

## Lessons carried forward

- Keep the enclosure exterior clean.
- Keep the lower/underside shell closed.
- The existing **slide-channel mounting interface is REQUIRED geometry** and must be copied from the proven enclosure/mount relationship, not approximated from screw-hole locations.
- Preserve the exact docking/channel-engagement region first; redesign only the enclosure volume forward of that retained interface.
- Keep the PCB carrier/chassis as a separate internal part.
- Retain the current ~16.5 mm faceplate-back to PCB-top spacing only as a provisional design target.
- Do **not** create a connector opening until the actual IPC-101-to-Alpha connector is selected.
- Once selected, use a flush panel-mount cutout sized to the real connector.

Rev H, H1, and H2 are superseded. The next revision must begin from the proven channel-fitting enclosure geometry or the actual mounting-bracket CAD/measurements.

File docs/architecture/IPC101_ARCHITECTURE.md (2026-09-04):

# IPC-101 Architecture

IPC-101 is a passive/keypad-peripheral panel. Seven ordinary keys form a 7-row by 1-column matrix read by U1, a TI TCA8418 at address 0x34. IPC-100 polls the event FIFO over its protected J10 I2C branch; INT is not exported because J10 has no interrupt conductor. The scanner provides hardware debounce and pull-ups, so no per-key RC networks are used.

| Matrix position | Function |
|---|---|
| R0/C0 | LEFT |
| R1/C0 | RIGHT |
| R2/C0 | UP |
| R3/C0 | DOWN |
| R4/C0 | SELECT |
| R5/C0 | START |
| R6/C0 | PULL |

Unused TCA8418 GPIOs are pulled to 3.3 V as required by the datasheet. RESET is pulled high. INT is available at a test pad and polling is mandatory.

The display is intentionally not placed on J10. It remains an IPC-100 J6 peripheral at address 0x3C or 0x3D, preserving J10's one-accessory/address contract. J6 enters IPC-101 at J4 and passes directly to J2; a short harness connects J2 to the faceplate-mounted Hosyond 2.42-inch 128x64 I2C SSD1309 module (Amazon ASIN B0G2RFLG1L). The obsolete small-display pattern is not used.

STOP is a panel-mounted normally-closed switch on its own two-conductor harness. J3 is only a mechanically convenient pass-through/termination point; neither conductor connects to GND, copper pours, U1, or J1.

## Power budget

| Load | Conservative allocation |
|---|---:|
| TCA8418 active/polling | 1 mA |
| Pull/reset leakage and test points | <1 mA |
| Margin | 8 mA |
| IPC-101 J10 design target | 10 mA maximum |

The OLED is powered from J6 and is not included in J10 current. The selected module must remain within IPC-100's released limit of 100 mA continuous and 150 mA for no more than 20 ms at startup.

## Firmware contract

IPC-100 shall enable J10/EXPANSION_VCC, configure the 100 kHz segment, probe 0x34, program R0-R6/C0 as a keypad, enable debounce/event FIFO, and poll at 10–20 ms. On loss of the panel or malformed events, ordinary commands default inactive. START and PULL are edge-qualified in product firmware. No IPC-101 event may bypass STOP, limit, watchdog, or actuator-permit logic.

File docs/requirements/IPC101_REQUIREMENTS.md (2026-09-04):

# IPC-101 P0 Requirements

Status terms: **LOCKED** is supported by IPC-100 source or a selected component; **PROVISIONAL** requires prototype validation; **BLOCKED** needs external data.

| ID | Requirement | Status / verification |
|---|---|---|
| FUN-001 | Provide dedicated START, PULL, and physically distinct STOP controls. | LOCKED; inspection/test |
| FUN-002 | Provide LEFT, RIGHT, UP, DOWN, and SELECT navigation (seven ordinary inputs total with START/PULL). | LOCKED; functional test |
| FUN-003 | Provide a phone-independent 128x64 Hosyond 2.42-inch I2C SSD1309 display (ASIN B0G2RFLG1L) connected through IPC-101 J4/J2 to IPC-100 J6. | PROVISIONAL; sample qualification and measured mounting pattern required |
| ARC-001 | IPC-100 remains system authority; IPC-101 contains no MCU or radio. | LOCKED; schematic inspection |
| ARC-002 | Ordinary controls use IPC-100 J10 at 3.3 V, 100 kHz, <=100 mA, <=0.30 m, no clock stretching or live mating. | LOCKED; IPC-100 contract |
| ARC-003 | The keypad peripheral uses allowed 7-bit address 0x34. | LOCKED; TCA8418 |
| SAF-001 | STOP uses the dedicated J8A supervised pair and is never combined with logic ground. | LOCKED; continuity/isolation test |
| SAF-002 | Opening STOP shall retain IPC-100's hardware inhibit behavior; firmware debounce shall not delay it. | LOCKED; system test |
| ELE-001 | Ordinary switches shall have a defined idle state and hardware debounce. | LOCKED; TCA8418 internal pull-ups/debounce |
| ELE-002 | IPC-101 shall not add I2C pull-ups because IPC-100 owns the segmented-bus pull-ups. | LOCKED; schematic inspection |
| ELE-003 | Local 3.3 V decoupling shall include 100 nF at U1 and 4.7 uF bulk near J1. | LOCKED; inspection |
| ELE-004 | IPC-101 J10 interface current shall remain below 100 mA. | LOCKED; calculated <5 mA typical |
| MECH-001 | PCB outline shall be 100 x 140 mm with four M3 mounting holes for P0. | PROVISIONAL; enclosure measurement |
| MECH-002 | Controls shall follow DISPLAY / NAV / START-STOP / PULL hierarchy. | LOCKED; drawing inspection |
| ENV-001 | Components shall be enclosed against weather; no bare-board IP claim is permitted. | LOCKED |
| MFG-001 | Through-hole operator controls and 0805 passives are preferred; U1 may require stencil/reflow. | LOCKED |
| VAL-001 | Native ERC, DRC, footprint inspection, and first-article continuity shall pass before fabrication release. | BLOCKED; KiCad CLI and received-part checks |

IPC-101 does not duplicate safety qualification, drive motors, source high current, implement wireless communication, or provide an independent system controller. Enclosure, overlay, sealing boots, and final panel thickness are outside P0 until measured.

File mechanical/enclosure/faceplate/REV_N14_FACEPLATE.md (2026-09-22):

# N1.4 faceplate - enlarged P504 opening

The user confirmed the hole edge blocks directional movement while select works. N1.4 enlarges the front P504 aperture from **6.2 to 8.0 mm**, adding **0.9 mm clearance per side**. It keeps N1.3's compact traced tree + IPO and CrossWind artwork, measured ARM-left/PULL-right alignment, 2 mm plate, and exact rear P504 cradle. Existing R1 labeled caps and I.1 structure remain unchanged.

- [White faceplate](CrossWind_IPC101_Faceplate_RevN14_WHITE_PETGHF.stl)
- [Black inlay](CrossWind_IPC101_Faceplate_RevN14_BLACK_AMS.stl)
- [Preview and opening comparison](N14_faceplate_preview.png)

Import both files as parts of one object, preserve their shared coordinates, and use the existing face-down two-material profile. Do not mirror the parts. The rear revision mark is IPC101-FP-N1.4.

The exports pass closed-mesh checks, aperture clearance, unchanged rear cradle/artwork checks, and 42 ARM/PULL clearance checks. A reference 5 mm hub clears at 1.4 mm radial offsets in eight directions; this is a reference envelope, not a measurement of the installed cap. Actual four-direction movement, select and return remain to be checked with the assembled hardware. The [8 mm coupon](../controls/navigation/P504_DIRECTIONAL_FIT.md) provides the same opening and cradle for a smaller test print.

```powershell
python -B mechanical/enclosure/tooling/render_faceplate_n1.py --revision N14 --openscad "C:\path\to\openscad.com"
python -B mechanical/enclosure/tooling/verify_faceplate_n14.py
python -B mechanical/enclosure/tooling/preview_faceplate_n14.py
```

Keep branding/iron_pine_tree_unit.stl with the SCAD source. Earlier N1-N1.3 exports still have the 6.2 mm opening and are superseded for this reprint.

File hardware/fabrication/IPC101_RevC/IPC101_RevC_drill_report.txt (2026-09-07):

Drill report for IPC101.kicad_pcb
Created on 2026-09-07T18:36:45

Copper Layer Stackup:
    =============================================================
    L1 :  F.Cu                      front
    L2 :  B.Cu                      back

Drill file 'IPC101-PTH.drl' contains
    plated through holes:
    =============================================================
    T1  0.300mm  0.0118"  (56 holes))
    T2  0.600mm  0.0236"  (4 holes))
    T3  0.800mm  0.0315"  (4 holes))
    T4  0.950mm  0.0374"  (5 holes))
    T5  1.000mm  0.0394"  (6 holes))
    T6  1.200mm  0.0472"  (8 holes))
    T7  1.300mm  0.0512"  (2 holes))

    Total plated holes count 85

Drill file 'IPC101-NPTH.drl' contains
    unplated through holes:
    =============================================================
    T1  3.200mm  0.1260"  (8 holes))

    Total unplated holes count 8

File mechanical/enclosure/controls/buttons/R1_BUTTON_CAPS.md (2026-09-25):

# ARM/PULL caps R1 and matching N1.2 faceplate

Status: **PRINTABLE FIT PROTOTYPE — CAD VERIFIED; PHYSICAL FIT PENDING**.

## Physical stem-trim feedback

The user reports removing approximately **1.5 mm from the button stem length**, after which operation works well. It is not yet confirmed whether this was ARM, PULL, or both. Preserve the working trimmed part. This is an approximate successful physical correction, not a calibrated new stack measurement or approval of both buttons.

Relative to the R1 source, a 1.5 mm trim would give an **8.07 mm stem beyond the rear flange** and **12.62 mm total cap depth** (previously 9.57 and 14.12 mm). These are nominal CAD arithmetic, not measurements of the trimmed print. Original R1 source and exports remain unchanged; carry the confirmed correction into a separately identified revision once the affected cap(s) are known. Do not infer a 1.70 mm actual resting gap from the old provisional stack estimate.

The user measured 12.82 mm from the front of the faceplate to the unpressed button face, with approximately 2.05 mm faceplate thickness. That gives 10.77 mm from the back of the plate to the button. This replaces the earlier estimate for cap reach; it does not alter the printed cradle or nominal PCB CAD spacing.

R1 is a sliding plunger with a retaining flange behind the faceplate. Its flat 5.5 mm diameter stem tip contacts the reported 6 mm actuator; it is not a socket or press fit. Both caps use the supplied shared measurement. Confirm both actual switches during assembly.

| Dimension | R1 value |
|---|---:|
| Face above measured faceplate front at rest | 1.50 mm |
| Guide through opening | 15.2 x 10.0 mm, radius 2 corners |
| Existing N1 opening | 16.0 x 10.8 mm, radius 2 corners |
| Rear retaining flange | 18.0 x 12.8 x 1.0 mm |
| Stem beyond rear flange | 9.57 mm |
| Tip reach from faceplate back | 10.57 mm |
| Provisional resting gap to actuator | 0.20 mm |
| Total cap depth, including face and stem | 14.12 mm |
| Flush black label depth | 0.60 mm |

## Print files

Print one cap first to check travel before making the second. The same stem geometry is used for ARM and PULL.

| Cap | White body | Black face label |
|---|---|---|
| ARM | [ARM white](CrossWind_IPC101_ARM_Cap_R1_WHITE_PETGHF.stl) | [ARM black](CrossWind_IPC101_ARM_Cap_R1_BLACK_AMS.stl) |
| PULL | [PULL white](CrossWind_IPC101_PULL_Cap_R1_WHITE_PETGHF.stl) | [PULL black](CrossWind_IPC101_PULL_Cap_R1_BLACK_AMS.stl) |

Import each cap's white/black pair as parts of **one object**. Import the other cap as a separate object; importing all four files into a single object would superimpose the two caps. Preserve each pair's shared coordinates and do not mirror them. The complete words are already oriented to read from the operator side.

Print face/lettering down on the bed with the stem upward. Use PETG, 0.20 mm layers, four walls and solid infill for these small parts. Inspect the first three layers for the 0.6 mm flush lettering. The rear flange has 1.4 mm ledges around the guide; inspect the slicer's overhangs and use local support under these ledges if needed. Clean the flange undersides and guide surfaces without rounding away the retaining ledge. Avoid an elephant foot around the sliding guide. `A-R1` / `P-R1` is recessed on the rear flange.

## Assembly and first fit

Insert each cap from the back of the faceplate, with its labeled face through the opening and the flange retained behind it. ARM goes in the left opening, PULL in the right when viewed from the front. Keep the loose caps supported while attaching the faceplate to the bezel; they are not captive when the plate is removed from the assembly.

Confirm each cap slides without binding, the switch is unpressed at rest, and light pressure actuates and releases it reliably. The return comes from the switch; a loose plunger may retain a small amount of free play. The 0.20 mm gap is provisional and does not guarantee return in every orientation. If either cap sticks or holds a switch pressed, stop and report which one and whether the flange/guide or stem is contacting. Do not force the cap. R1 adds no positive overtravel stop; the 1 mm CAD motion sweep is geometric clearance, not an instruction to compress the switch by 1 mm.

## Faceplate with labels on caps only

The [N1.2 tree correction](../../faceplate/history/REV_N12_FACEPLATE.md) supersedes the generic tree in N1.1. R1 cap geometry is unchanged.

The matching **N1.2** faceplate removes the duplicate ARM/PULL text above the openings. It retains N1's measured button locations and uses the tree traced from the supplied wordmark, with unchanged OLED/D-pad locations, mounting holes and rear cradle. Its hidden rear mark reads `IPC101-FP-N1.2`. Existing N1 remains mechanically compatible with these caps if already printed.

- [N1.2 white faceplate](../../faceplate/history/CrossWind_IPC101_Faceplate_RevN12_WHITE_PETGHF.stl)
- [N1.2 black inlay](../../faceplate/history/CrossWind_IPC101_Faceplate_RevN12_BLACK_AMS.stl)
- [Caps and panel preview](R1_button_caps_preview.png)

Use the N1.2 pair for the upcoming full faceplate reprint with labeled caps. Import them together as one object, just like the N1 pair. Do not combine N1 and N1.2 materials.

## Verification and source

`R1_button_caps_verification.json` records 332 checks: closed/wound cap bodies and inlays; release gap; flange retention; 21 positions over 1 mm of geometric inward travel for each cap against both faceplates, bezel, cradle, R3, bare PCB and shell; hardware clearance; and preserved N1.2 structural geometry. Actual switch movement, component envelopes, fit of both printed caps and environmental sealing remain physical checks.

Sources: `CrossWind_IPC101_Button_Caps_R1.scad`, `CrossWind_IPC101_Faceplate_RevN12.scad`.

```powershell
python -B mechanical/enclosure/tooling/render_button_caps_r1.py --openscad "C:\path\to\openscad.com"
python -B mechanical/enclosure/tooling/render_faceplate_n1.py --revision N12 --openscad "C:\path\to\openscad.com"
python -B mechanical/enclosure/tooling/verify_button_caps_r1.py
python -B mechanical/enclosure/tooling/preview_button_caps_r1.py
```

Old Rev C cap files remain historical references; their short stems do not match this measured stack.

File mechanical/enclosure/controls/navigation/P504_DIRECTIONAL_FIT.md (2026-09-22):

# P504 directional restriction — 2026-09-22

The user reports center/select works but directional movement is blocked in the printed faceplate. N1.3 still has the inherited 6.2 mm aperture; earlier Rev C used 8 mm with a 5 mm cap hub. That earlier clearance is a starting point, not proof that it fits the currently installed cap or pedestal.

**Update: the user confirmed the hole edge is the restriction.** The [N1.4 full faceplate](../../faceplate/REV_N14_FACEPLATE.md) now includes the 8 mm aperture. CAD checks pass; physical directional travel remains unverified. The coupon below remains available for a smaller test.

The [8 mm P504 clearance coupon](CrossWind_IPC101_P504_Clearance_R1_8mm_PRINT.stl) is a 30 x 30 x 4.8 mm piece with the same 2 mm plate and exact N1.3 rear cradle, marked P504-R1 on the rear. Print front down as exported, then fit the actual switch, pedestal/sleeve and cap as used on the panel. Check all four directions, center/select and return. Report whether movement is free with and without the cap. The coupon is not an adapter installed on top of the existing faceplate.

The 8 mm opening adds 0.9 mm radial clearance over the old hole. Only the front aperture and hidden coupon mark change; the rear cradle is preserved. This test is reversible and avoids committing another whole faceplate to an unverified diameter. A larger aperture alone will not fix a cap seated too deeply, a trapped sleeve, or an overconstrained switch body.

Source: `generate_p504_clearance_r1.py`. `P504_clearance_R1_verification.json` records mesh validity, open aperture and preserved cradle. These CAD checks do not establish actual directional movement. N1.4 releases the corresponding full faceplate; see its separate verification report.

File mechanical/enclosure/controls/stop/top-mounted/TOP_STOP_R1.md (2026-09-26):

# Integrated top STOP housing R1 ? fit prototype

> Export cleanup, 2026-09-26: superseded print links below are historical. Use `mechanical/enclosure/PRINT_THESE.md` for current parts. Source and Git history retain regeneration/recovery information.

[Assembly, section and roof-removal preview](TOP_STOP_R1_preview.png).

R1 develops the top STOP concept into a two-piece housing with four top-access screws, locating shoulders and an internal harness tie tab. The roof retains the rounded full-width profile and sloped front transition. The STOP mounting surface is Z141 mm, 32.616 mm above the I.1 shell maximum. The conservative switch envelope and 2.5 mm keyed mounting land are retained from the packaging study. This is an engineering fit prototype, not a weather-sealed final release.

## What changes

The base replaces the I.1 box and adds four attachment bosses plus the existing 24 x 24 mm cable passage. The R3 carrier, cradle, bezel and Rev H detachable mount are reused. The roof lifts vertically after removing four screws; remove it before withdrawing the front cassette. This roof is not a bolt-on accessory for an unmodified I.1 box.

Four M3 x 30 socket screws seat at Z138 and engage 9 mm of 2.7 mm printed pilot below the Z117 support plane. The pilots stop at Z107, leaving 8 mm of boss below the bore. Hardware dimensions are provisional; use the coupons to establish fit in the chosen material before committing to a large print. Do not force a tight screw or assume a printed pilot is suitable for repeated service without testing.

Each boss has a 7 mm diameter, 2 mm high locating shoulder. Its roof socket is 7.6 mm diameter and 2.4 mm deep: 0.3 mm radial and 0.4 mm end clearance. The inherited lower-skirt contact is relieved by 0.3 mm along each axis. Four shoulders locate the roof; the coupons test local clearance, while the full-width prototype must still demonstrate simultaneous engagement without binding. The roof has 6.4 mm head wells and modeled clearance for a 7 mm driver envelope.

A two-slot tie tab on the roof underside supports the harness independently of the switch terminals. A 20 x 20 x 10 mm wire reserve and a 36 mm diameter mounting-nut access envelope are checked. Real leads, bends and populated board components remain to be measured. Allow enough service slack or a suitable disconnect to lift the roof; the CAD withdrawal check does not simulate flexible wires.

## R2 access correction

The user found that the contact block cannot enter the R1 underside opening. Use the [R2 access coupon and revised roof](TOP_STOP_R2.md) for the correction. The roof-to-base fit and nut installation were reported workable.

## Physical feedback

The user reports that the locator coupons slide together well. Keep the current locator clearance. Screw engagement and full clamp-up remain untested; M3 x 30 screws were not available.

A [rear-entry base variant](../../../mounting/rear-tunnel-r1/README.md) now reuses this roof and closes the old bottom wiring port. It is a fit prototype pending actual harness-motion checks.

## Print and fit order

1. Print the [pilot coupon](CrossWind_IPC101_Top_STOP_Pilot_Coupon_R1_PRINT.stl) and roof coupon (retired export; recover from Git history). Check the locator slip fit, screw-head recess, M3 x 30 engagement and clamp-up. Stop if the boss cracks, the screw bottoms or the thread strips.
2. Print the roof (retired export; recover from Git history) to check the actual STOP body, mounting nut, terminal access and tie tab. The export places the top surface on the bed; inspect support requirements for the recessed locating sockets and tie tab in the slicer.
3. Print the replacement base (retired export; recover from Git history) after the small fits pass. It sits on its bottom; inspect supports under the sloped shell and added bosses.
4. Dry assemble all four shoulders and screws, then verify roof removal, complete cassette withdrawal, mount sliding, actual wire routing, STOP actuation and reset access.

`INSTALLED` exports retain shared assembly coordinates and are for assembly review. `PRINT` exports are moved to the bed and fit within a 256 mm cube. Existing I.1 and side-pod S1 print files remain available; the older PRINT THESE guide continues to identify the established fit build.

## Verification and remaining design work

[Machine-readable results](TOP_STOP_R1_verification.json) cover connected watertight exports, static stack clearance, roof/base separation, switch and nut envelopes, screw/driver clearance, unchanged rear mounting interface, 71 bracket positions, 66 complete-cassette positions and 51 roof-lift positions.

The roof seam, switch gasket and screw wells still need a sealing design. There is no water-ingress rating. Printed-pilot strength, long-term retention, populated-board clearance, harness flex and actual operator access require physical verification. The preview uses N1.4 faceplate geometry; approved artwork integration is a separate remaining step.

Regenerate from the repository root:

```powershell
python -B mechanical/enclosure/tooling/generate_top_stop_r1.py
python -B mechanical/enclosure/tooling/preview_top_stop_r1.py
```

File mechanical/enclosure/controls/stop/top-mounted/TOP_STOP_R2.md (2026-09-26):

# Top STOP roof R2 - underside insertion correction

> Export cleanup, 2026-09-26: superseded print links below are historical. Use `mechanical/enclosure/PRINT_THESE.md` for current parts. Source and Git history retain regeneration/recovery information.

[Preview](TOP_STOP_R2_preview.png) | [Verification](TOP_STOP_R2_verification.json)

User feedback: the printed R1 roof fits the enclosure, and the retaining nut can be installed by hand. The rear contact block cannot enter the underside opening. Its measured maximum cross-section is 27.3 x 27.3 mm, rotates about its center, and has no reported protrusions beyond that measurement. The earlier checks tested the stationary body in its final position and missed the restrictive underside access path.

R2 opens a continuous 41 mm diameter path from below the roof to the underside of its 2.5 mm top mounting land. A centrally rotating 27.3 mm square sweeps 38.608 mm diameter, leaving approximately 1.196 mm nominal radial clearance. A 47 mm outside-diameter reinforcement surrounds the upper pocket from Z109 to Z138.5; the lower entry is relieved to preserve the base fit. This slightly changes the outside shape near the switch pocket. The top keyed hole, top mounting land, four screw mounts and locating shoulders remain unchanged.

## Physical feedback and next revision

The user confirmed that the switch mounts successfully in R2. Release is difficult because the lower white tab must be reached and pushed upward before twisting off. The R2 coupon also produced loose strands at upper features. Use the [R3 paired-access roof and simplified release coupon](TOP_STOP_R3.md) for the next print.

## Historical R2 coupon instructions

Access coupon R2 PRINT (retired export; recover from Git history) reproduces the central roof section, including the full access pocket and keyed mounting hole. Use the exported orientation: top face against the bed, underside access upward. Inspect the support preview; avoid filling the vertical access pocket with unnecessary support. The user restored PETG support Top Z distance to 0.20 mm after prior prints used 0 mm and were difficult to separate. Do not restore zero gap for PETG-on-PETG supports.

Fit the operator and nut to this coupon, then insert the actual contact block from the underside and twist it into lock. Confirm removal as well, and verify terminals and wires do not catch. This is a test of the complete insertion-and-turn sequence, not just passage through a ring. Report any contact point before another full roof print.

Once that physical test passes, use Roof R2 PRINT (retired export; recover from Git history). Assemble the switch/contact block with the roof removed from the enclosure, then attach the roof. The base's smaller cable passage is not an installation opening for the contact block.

R2 reuses both the original top STOP R1 base and the rear-tunnel R1 enclosure base, plus the same four provisional M3 x 30 screws. No replacement base or locator coupon is needed for this correction. R1 roof files remain for history and should not be selected for this switch installation.

## Verification and limits

539 CAD interference checks pass. These include a continuous cylindrical insertion/rotation envelope, 72 angular positions at five insertion depths, both base variants during roof removal, current stack clearance and 71 rear-mount slide positions. A regression check reproduces 473.852 mm3 of R1 obstruction during insertion. Exact geometry comparisons confirm the top land/keyed hole and roof attachments are unchanged. All four exported meshes are connected, watertight and consistently wound.

The 30.5 mm block depth remains the previous conservative package assumption; only the 27.3 mm square and central rotation are measured/confirmed. Actual wires, fingers and tools are not modeled. Physical twist-lock fit, support cleanup and weather sealing remain unverified.

```powershell
python -B mechanical/enclosure/tooling/generate_top_stop_r2.py
python -B mechanical/enclosure/tooling/preview_top_stop_r2.py
```

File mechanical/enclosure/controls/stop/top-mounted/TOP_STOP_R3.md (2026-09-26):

# Top STOP roof R3 - paired release access

> Export cleanup, 2026-09-26: superseded print links below are historical. Use `mechanical/enclosure/PRINT_THESE.md` for current parts. Source and Git history retain regeneration/recovery information.

[Preview](TOP_STOP_R3_preview.png) | [CAD verification](TOP_STOP_R3_verification.json)

The user confirmed that the R2 pocket accepts and mounts the contact block. The remaining difficulty is reaching the lower white release, pushing it upward, then twisting the block off. The block can attach in two opposite orientations. R3 retains the confirmed 41 mm pocket and removes material on both X sides, perpendicular to the mounting-hole key axis, to provide upward release approaches.

Two opposed 14 mm wide slots run from the underside to Z136.5. They leave 4.5 mm of material to the exterior top face, including the unchanged 2.5 mm mounting land. The keyed hole, four roof attachments, locating shoulders and compatibility with both existing bases remain unchanged. Slots do not imply a weather seal; sealing remains unfinished.

## Superseded release-slot alignment

Physical R3 testing found release difficult even with a small screwdriver. The user identified a roughly 45-degree clockwise slot correction viewed from underneath. Use the [R4 coupon and roof](TOP_STOP_R4.md) for the next trial.

## Historical R3 coupon instructions

Release coupon R3 PRINT (retired export; recover from Git history)

This replaces the complicated cut-out roof section used for the previous coupon. It is a simple 47 mm diameter, 32 mm tall central pocket with the same 41 mm bore, keyed mounting hole, mounting thickness and release slots. It omits the surrounding roof skirts, ledges and wire tie tab. It is intended to test local switch/release access, not the full housing assembly.

- Use the exported orientation: flat keyed-hole face on the bed, large pocket opening upward.
- Use 0.20 mm layers and **supports OFF for this coupon**. A layer-section check at that spacing confirms each higher cross-section stays within the preceding section; there are no upper ledges that require bridging. This geometric check does not guarantee extrusion or adhesion quality.
- Install the operator and retaining nut. Insert and lock the contact block, then reach the lower white release through a slot, push it up and twist the block off. Repeat with the contact block installed in the opposite orientation.
- Test with the coupon held securely and power disconnected. The actual latch stroke and finger/tool dimensions have not been measured, so this physical check determines whether the proposed access is adequate.

If release is comfortable in both orientations, print Roof R3 PRINT (retired export; recover from Git history). Do not use the old R1/R2 roof for the next full print. Keep the existing base and roof hardware. Inspect the full roof's support preview separately; the no-support instruction applies only to the simplified coupon.

Next after roof printing: assemble the actual STOP operator/contact block with the roof off, verify locking/release and terminal/harness access, then fit the populated roof to the base. Roof fastener clamp-up still needs the actual M3 x 30 screws. Harness layout and electrical interface limits remain unresolved and are not changed here.

## Verification

All 539 existing R2 insertion, rotation, mounting and service checks pass on the R3 roof. Additional checks confirm the release corridors contain no roof material, the revision only removes material from R2, the coupon is self-supporting by 0.20 mm section comparison, and all four exports are connected, watertight and consistently wound. Actual release accessibility remains pending the coupon test.

```powershell
python -B mechanical/enclosure/tooling/generate_top_stop_r3.py
python -B mechanical/enclosure/tooling/preview_top_stop_r3.py
```

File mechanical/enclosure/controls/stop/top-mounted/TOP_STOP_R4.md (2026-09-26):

# Top STOP R4 - release slots rotated clockwise

> Export cleanup, 2026-09-26: superseded print links below are historical. Use `mechanical/enclosure/PRINT_THESE.md` for current parts. Source and Git history retain regeneration/recovery information.

[Preview](TOP_STOP_R4_preview.png) | [Verification](TOP_STOP_R4_verification.json)

R3 accepted the switch, but the user found pushing the white release with a small screwdriver very difficult. User identified approximately 45 degrees of angular misalignment and specified **clockwise when looking into the open underside**. R4 rotates the two opposed release approaches by that amount; the mounting key stays unchanged. In installed coordinates this is +45 degrees about Z.

The 41 mm pocket, 14 mm nominal slot width, slot height, mounting land and roof attachments are retained. The relief is bounded at installed Y=-9 and Y=27 to preserve the front/rear outer skin rather than cutting through it; the approach remains open from below. Both base variants remain compatible.

## Physical checkpoint - 2026-09-26

The user reports the coupon fit is perfect and the R4 roof is printed. Coupon exports were retired after this report. Full assembly, screw clamp-up and sealing remain unverified.

## Historical coupon procedure

Release coupon R4 PRINT (retired export; recover from Git history)

Use the supplied orientation, flat keyed-hole face down and large pocket opening up. Use 0.20 mm layers and **supports OFF for this coupon**. The cross-section support check passes in this orientation. This is a local access fixture, not a full-roof printability test.

Mount the switch and check that the slot now aligns with the lower white release: push it up and twist the contact block off. Repeat in the opposite block orientation. The 45-degree correction comes from user observation rather than a dimensioned latch drawing, so physical accessibility still needs confirmation. Do not force the tab.

If both orientations release comfortably, the next full print is [Roof R4 PRINT](CrossWind_IPC101_Top_STOP_Roof_R4_PRINT.stl). Inspect its supports independently; the no-support instruction applies only to the coupon. Keep the existing base and hardware.

All 539 inherited insertion/rotation/service checks pass, plus the coupon layer-support and release-corridor checks. Four exports are watertight, consistently wound, single connected meshes. User feedback now reports perfect coupon fit; both-orientation release was not separately described. R3 is retained as history.

```powershell
python -B mechanical/enclosure/tooling/generate_top_stop_r4.py
python -B mechanical/enclosure/tooling/preview_top_stop_r4.py
```

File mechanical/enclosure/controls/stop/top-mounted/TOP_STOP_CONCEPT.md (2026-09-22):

# Integrated top STOP - packaging concept

The next iteration is the [R1 removable-roof fit prototype](TOP_STOP_R1.md), with attachment bosses, locating shoulders and a harness tie tab. This document preserves the initial packaging study.

User direction (2026-09-22): move the received IDEC XA1E-BV302R onto the top behind the sloped faceplate. Enclosure and/or faceplate may grow. The plywood/cardboard mock-up shape is not a styling constraint. Design should look intentional, with the red stop prominent. Preserve the working carrier and proven detachable mount where practical.

[Three-view concept](TOP_STOP_concept_preview.png). This is a packaging study, not a printable enclosure release or final industrial design. The preview uses older faceplate artwork solely as a geometric reference; the approved stacked tree and traced CrossWind artwork remain selected.

A flush installation at the existing top interferes with the original R3 carrier and cradle using the conservative 32 mm square, 33 mm rear-depth package established for the S1 pod. The tested top center is installed X78/Y10. These envelopes are deliberately larger than the nominal 27.9 mm manufacturer rear depth; the actual contact body, terminals and soldered leads still need physical checking.

The candidate has a rounded upper housing spanning the 174 mm enclosure width, with a gently sloped front transition. Its mounting surface is Z141 mm versus the existing shell maximum Z108.384 mm: an increase of 32.616 mm. Red operator and yellow collar are schematic for visual placement, not exact manufacturer CAD. A 2.5 mm top mounting land uses the previously accepted 16.3 mm keyed cutout dimensions.

The upper housing removes vertically before the front cassette is withdrawn. This avoids the removal obstruction found in the first fixed-roof trial. The base receives an internal 24 x 24 mm cable passage above the carrier. A 20 x 20 x 10 mm wire reserve clears the modeled base and stack. No change to the STOP circuit is proposed.

Checks in TOP_STOP_study.json: static shell/PCB/R3/cradle/bezel/faceplate clearance; conservative switch and wire envelopes; unchanged existing rear interface; 71 bracket slide positions; 66 cassette withdrawal positions with roof removed; 51 vertical roof/switch removal positions. These are rigid CAD envelopes and do not certify real harness motion or populated-board clearance.

Still required before print release: coherent exterior refinement beyond this first packaging form; upper-housing fasteners and locating features; gasket/seal strategy; real contact-block installation access, solder-joint routing and strain relief; physical switch clearance and operator/reset access. Roof is not yet fastened in this concept. Current I.1 and S1 print files remain unchanged.

Regenerate:

```powershell
python -B mechanical/enclosure/tooling/study_top_stop.py
python -B mechanical/enclosure/tooling/preview_top_stop.py
```

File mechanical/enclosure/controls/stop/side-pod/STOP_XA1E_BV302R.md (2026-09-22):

# Received STOP switch - IDEC XA1E-BV302R

Status: **HARDWARE RECEIVED; S1 SIDE POD CREATED; PHYSICAL FIT PENDING**.

The [S1 accessory guide](STOP_S1_ASSEMBLY.md) now contains the verified manufacturer drawing dimensions, printable cutout coupon, pod, cover and hardware list. The pod uses two existing cassette attachment points and preserves I1/M4/R3 parts. [Preview](STOP_S1_preview.png).

The user identified the received part as `XA1E BV302R`. IDEC lists `XA1E-BV302R` and the regional formatting `XA1E-BV302-R`.

Manufacturer-confirmed characteristics:

- 16 mm nominal panel-mount family; do not interpret this as a finalized printed cutout/tolerance.
- 29 mm red mushroom operator, non-illuminated.
- Two normally closed contacts (2NC), solder terminals.
- Push-lock operation with pull or turn reset; removable contact-block type.

Sources: [IDEC exact-part page](https://www.idec.com/en-eu/switches-indicator-lights/switches-pushbuttons/emergency-stop-switches/xa-16mm-estop/xa1e-bv302r), [IDEC US part page](https://www.idec.com/en-us/switches-indicator-lights/switches-pushbuttons/emergency-stop-switches/xa-16mm-estop/xa1e-bv302-r). Checked 2026-09-21. Do not substitute the dimensions of the different `BV3U02` unibody model.

## Mechanical integration

The old P0 layout's 22.3 mm STOP cutout is superseded for this received part. Its old panel coordinates are also not a placement decision for Rev I.1. M.4 currently has no dedicated STOP mounting opening.

The manufacturer drawing has now been inspected and used for S1. During physical fit, check the received part:

- Panel-seating surface to rear terminal tips, including any fitted terminal cover.
- Maximum rear body and locking-nut width/diameter.
- Allowed panel thickness, locking/keying features, and hand/tool access for installation.
- Additional wire/solder-joint clearance and actuator access/reset motion at the proposed location.

The 16.5 mm PCB stack cannot accommodate the nominal 27.9 mm rear switch depth. S1 places the switch outside the PCB envelope with a removable rear cover. CAD clearance and bracket withdrawal checks pass; actual cable routing, tool access and mount stiffness still require physical validation. The current bezel/cradle print sequence continues unchanged.

## Electrical interface context

The repository's [IPC-100/IPC-101 interface](../../../../../docs/interface/IPC100_IPC101_INTERFACE.md) specifies an isolated NC STOP pair on J3: pin 1 `STOP_IN_RAW`, pin 2 `STOP_RETURN`, carried to IPC-100 J8A. Neither signal is ground. Received-switch terminal markings, continuity and final contact allocation remain to be checked before wiring. This arrival note does not change the safety circuit or assign the second NC contact.

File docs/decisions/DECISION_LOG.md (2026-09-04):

# IPC-101 P0 Decision Log

| ID | Decision | Reason | Status |
|---|---|---|---|
| D-001 | IPC-100 remains controller; no ESP32/radio on IPC-101. | Product boundary and minimum complexity. | Accepted |
| D-002 | Use 12 mm B3F-4055 for START/PULL. | Glove target, cap support, THT stability, sourcing. | Accepted |
| D-003 | Use Adafruit 504 five-way navigation. | Direct manual-direction mapping beats encoder semantics. | Accepted with footprint hold |
| D-004 | Use J10 instead of J8B for ordinary controls. | J8B has only five input signals; seven are required. | Accepted; IPC-100 ECO required |
| D-005 | Use TCA8418 at 0x34 in a 7x1 matrix. | Fits J10 released address window and switch common topology. | Accepted |
| D-006 | Poll event FIFO; do not add an interrupt wire. | J10 is four conductors; preserves frozen connector. | Accepted |
| D-007 | Keep OLED on dedicated IPC-100 J6 electrically, terminating it through IPC-101 J4/J2; use Hosyond 2.42-inch SSD1309 B0G2RFLG1L as the prototype candidate. | Makes IPC-101 the removable control-panel hub while preserving the display power/reset contract and J10 rule. | Accepted with qualification hold |
| D-008 | STOP is panel-mounted NC on J8A only. | Preserves supervised hardware inhibit and open-wire safety response. | Accepted; exact operator review required |
| D-009 | Provisional 100 x 140 mm panel PCB. | Supports useful prototype spacing without claiming enclosure fit. | Provisional |
| D-010 | Withhold fabrication plots. | Native ERC/DRC and two footprint gates are not closed. | Hold |

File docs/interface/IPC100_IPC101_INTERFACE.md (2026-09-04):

# IPC-100 / IPC-101 Interface Reconciliation

Source reviewed: sibling `IPC100` Rev A documentation and preliminary Sheet 09 capture, including Package 10R and the Rev A EBOM (reviewed 2026-09-01).

| IPC-101 need | IPC-100 interface | Disposition |
|---|---|---|
| 7 ordinary keys | J8B exposes only encoder A/B/SW and ARM/FIRE | J8B inadequate; do not overload semantics |
| 3.3 V peripheral + I2C | J10: EXPANSION_VCC, GND, SDA, SCL | Use J10; exact fit after population/firmware enable |
| OLED | J6: OLED_VCC, GND, SDA, SCL, RESET | Route J6 to IPC-101 J4, pass through to J2, then use a short five-wire harness to the faceplate-mounted display |
| Hardware STOP | J8A: STOP_IN_RAW, STOP_RETURN | Use isolated NC switch pair |

## J1 — ordinary controls (IPC-100 J10)

Board connector: JST `SM04B-GHS-TB(LF)(SN)`; mating housing `GHR-04V-S`, contacts `SSHL-002T-P0.2`, 26–28 AWG. Pin order follows IPC-100 J10 Sheet 09 symbol order and must be confirmed by harness drawing before crimping.

| Pin | Signal | Rule |
|---:|---|---|
| 1 | EXPANSION_VCC | protected switched 3.3 V, <=100 mA |
| 2 | GND | logic return |
| 3 | J10_I2C_SDA | IPC-100 owns pull-up/protection |
| 4 | J10_I2C_SCL | 100 kHz; no clock stretching |

Maximum harness length 0.30 m. Power-off mating only. No external power/backfeed. One accessory. U1 fixed address 0x34 lies in released 0x30–0x37 range.

## OLED harness and IPC-101 pass-through

IPC-100 J6 connects to IPC-101 J4 using JST GH wiring: pin 1 OLED_VCC, 2 OLED_GND, 3 OLED_SDA, 4 OLED_SCL, 5 active-low OLED_RESET. IPC-101 passes those five nets directly to J2, a keyed JST XH output with the identical pin order. A short J2-to-module harness adapts to the received OLED's 2.54 mm header. Do not assume the module pin order: inspect its markings and continuity-check both harnesses before power is applied. Limit the complete branch to 0.20 m/50 pF and use address 0x3C or 0x3D. The selected module must operate from 3.0–3.45 V, draw no more than 100 mA continuously/150 mA for 20 ms, have no fixed I2C pull-up below 47 kΩ, meet the released unpowered leakage/backfeed limits, and expose active-low RESET. The listing's statement that `RES` is not soldered by default must be resolved on the received sample; a functional reset conductor is required by the J6 contract.

## J3 — STOP pass-through

| Pin | Signal |
|---:|---|
| 1 | STOP_IN_RAW |
| 2 | STOP_RETURN |

Use an NC contact so an open wire asserts/faults STOP. Neither pin is ground. Use unique two-position Phoenix hardware matching IPC-100 J8A and label both harness ends `SAFETY STOP — J8A`; keep it physically incompatible with ordinary UI connectors.

## Smallest IPC-100 ECO

1. Populate/release J10 and its already designed protected 3.3 V branch.
2. Add the TCA8418 address 0x34 driver and the matrix mapping.
3. Enable 10–20 ms polling without an interrupt conductor.
4. Add IPC-101 presence/fault telemetry; absence keeps commands inactive.

No ESP32 GPIO reassignment, J8B pinout change, or safety-path change is required.

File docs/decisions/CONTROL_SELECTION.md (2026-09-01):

# Control Selection Decision

## 12 mm tactile family selected

Omron B3F-4055 is selected for START and PULL: 12 x 12 mm through-hole body, projected plunger for caps, 260 gf, 1,000,000-cycle mechanical life, active lifecycle, and broad US distribution. The larger body and cap support are materially easier to locate with gloves than common 6 x 6 mm tactiles. The cost and 20–25 mm center spacing are acceptable on the provisional 100 mm panel.

Six-millimeter tactiles win on density and price but have smaller targets, shorter typical life in this family, and less stable panel feel. They are rejected for the two primary actions. STOP is intentionally not standardized: safety prominence and a maintained NC contact outweigh BOM uniformity.

## Five-way navigation selected

Adafruit Product 504 is selected over a rotary encoder. It maps manual LEFT/RIGHT directly, offers UP/DOWN adjustment and CENTER select in one through-hole control, costs about $1.95, and avoids ambiguous encoder rotation during manual motion. A rotary encoder is better for fast numeric adjustment but needs a shaft/knob, panel-bearing decision, three inputs, and different firmware semantics.

Product 504 is prototype-only because Adafruit supplies a similar-part (SKQUCAA010) datasheet rather than an exact manufacturer MPN. The project footprint is therefore a fabrication hold until compared to a received sample. If it differs, update only `SW3` footprint and panel datum; architecture is unchanged.

## STOP selected separately

Omron A22NE-M-PD01-N is the recommended 22 mm red push-lock/turn-reset emergency-stop operator with an NC contact. Final operator, contact-block suffix, panel thickness, boot/shroud, and safety classification must be verified at purchase and system risk review. P0 treats it as a panel-mounted wired device, not a PCB component.

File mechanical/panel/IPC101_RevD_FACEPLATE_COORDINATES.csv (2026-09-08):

feature | x_mm | y_mm | cutout_or_hole_mm | status
H1 | 5 | 5 | 3.2 | REV_B_TESTFIT_DATUM
H2 | 145 | 5 | 3.2 | REV_B_TESTFIT_DATUM
H3 | 5 | 95 | 3.2 | REV_B_TESTFIT_DATUM
H4 | 145 | 95 | 3.2 | REV_B_TESTFIT_DATUM
OLED_CENTER | 54.5 | 63.5 | 57x28_WINDOW | REV_D_FACEPLATE_ONLY_SHIFT_RIGHT_8MM
OLED_MH_LL | 20.1 | 44.1 | 3.2 | REV_D_FACEPLATE_ONLY_SHIFT_RIGHT_8MM
OLED_MH_LR | 88.9 | 44.1 | 3.2 | REV_D_FACEPLATE_ONLY_SHIFT_RIGHT_8MM
OLED_MH_UL | 20.1 | 82.9 | 3.2 | REV_D_FACEPLATE_ONLY_SHIFT_RIGHT_8MM
OLED_MH_UR | 88.9 | 82.9 | 3.2 | REV_D_FACEPLATE_ONLY_SHIFT_RIGHT_8MM
NAV_SW3 | 105 | 63.5 | 8.0_STEM_OPENING | REV_C_CLEARANCE
NAV_CAP_SOCKET | 105 | 63.5 | 3.30x3.30x3.50_DEEP | TRAILBOSS_P504_REFERENCE
ARM_SW1 | 33.5 | 20.75 | 16x10.8_CAP_OPENING | REV_C
STATUS_LED | 68.5 | 31 | 5.2 | REV_C
PULL_SW2 | 103.5 | 20.75 | 16x10.8_CAP_OPENING | REV_C
POWER_SWITCH_RESERVE | 132 | 63.5 | TBD | NO_CUTOUT_UNTIL_PART_SELECTED
PRODUCT_LOGO | 75 | 7 | CROSSWIND_RECESSED_FRONT | REV_C

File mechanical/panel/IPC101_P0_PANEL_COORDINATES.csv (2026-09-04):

feature | x_mm | y_mm | cutout_or_hole_mm | status
PCB_OUTLINE | 0..150 | 0..100 | 150x100 | REV_C
H1 | 5 | 5 | 3.2 | REV_B_TESTFIT_DATUM
H2 | 145 | 5 | 3.2 | REV_B_TESTFIT_DATUM
H3 | 5 | 95 | 3.2 | REV_B_TESTFIT_DATUM
H4 | 145 | 95 | 3.2 | REV_B_TESTFIT_DATUM
OLED_CENTER | 46.5 | 63.5 | 57x28_WINDOW | REV_C
OLED_MH_LL | 12.1 | 44.1 | 3.2 | CROSSWIND_CONTROL_PANEL_FIT_PRINT
OLED_MH_LR | 80.9 | 44.1 | 3.2 | CROSSWIND_CONTROL_PANEL_FIT_PRINT
OLED_MH_UL | 12.1 | 82.9 | 3.2 | CROSSWIND_CONTROL_PANEL_FIT_PRINT
OLED_MH_UR | 80.9 | 82.9 | 3.2 | CROSSWIND_CONTROL_PANEL_FIT_PRINT
NAV_SW3 | 105 | 63.5 | 8.0_STEM_OPENING | REV_C_CLEARANCE
NAV_CAP_SOCKET | 105 | 63.5 | 3.30x3.30x3.50_DEEP | TRAILBOSS_P504_REFERENCE
ARM_SW1 | 33.5 | 20.75 | 16x10.8_CAP_OPENING | REV_C
STATUS_LED | 68.5 | 31 | 5.2 | REV_C
PULL_SW2 | 103.5 | 20.75 | 16x10.8_CAP_OPENING | REV_C
POWER_SWITCH_RESERVE | 132 | 63.5 | TBD | NO_CUTOUT_UNTIL_PART_SELECTED
PRODUCT_LOGO | 75 | 7 | CROSSWIND_RECESSED_FRONT | REV_C

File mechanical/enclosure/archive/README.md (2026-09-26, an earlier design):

# Archive - superseded IPC-101 enclosure development

> Historical design: superseded print exports were removed on 2026-09-26. Use `mechanical/enclosure/PRINT_THESE.md` for the current assembly; recover historical exports from Git or regenerate them.

**NOT FOR CURRENT PRINTING.** Use [PRINT THESE](../PRINT_THESE.md).

| Folder / file | Contents | Status |
|---|---|---|
| [superseded-rev-g](superseded-rev-g/) | Rev G box STLs and dimensions | Superseded enclosure/mounting approach |
| [exploratory-h-h1-h2](exploratory-h-h1-h2/) | Exploratory H/H1/H2 SCAD models and correction notes | Superseded experiments; never the authoritative Rev H T-rail baseline |
| [superseded-rev-i](superseded-rev-i/) | Initial Rev I box/carrier STLs and preview | Superseded by R3-compatible I.1; the archived box includes the front-opening correction |
| [DEVELOPMENT_HISTORY.md](DEVELOPMENT_HISTORY.md) | Earlier combined enclosure README | Historical decisions, measurements, limitations and revision notes |

Artifacts were moved without changing their geometry. Rejected intermediate versions that were already replaced before this cleanup remain recoverable from Git history. This archive is not evidence of physical validation.

The original R3, M.4 faceplate, authoritative Rev H mounting baseline and current I.1 parts remain in the parent folder. Older Python helpers also remain there because the current build imports them. Historical Rev G and Rev I regeneration now writes into the corresponding archive folders, keeping superseded print outputs out of the current folder. Rev H remains unchanged.

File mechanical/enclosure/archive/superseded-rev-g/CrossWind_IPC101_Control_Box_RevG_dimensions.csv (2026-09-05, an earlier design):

feature | value_mm | notes
installed_envelope | 156x82.319x101.6 | Width x maximum projection x height
faceplate | 150x100x2 | Centered with 3 mm side margins
face_angle | 47 | Degrees upward from vertical
nominal_wall | 3 | Shell wall
service_opening | 136x86 | Continuous opening; no transverse crosspiece
face_boss | 11x10.2 | Diameter x total depth
face_boss_extension | 1.2 | Outward to faceplate seating datum
face_insert_pilot | 4.2x6.0 | Diameter x depth; front loaded M3 heat-set insert
face_screw_relief | 3.2 | Blind relief beyond insert
wood_mount_x | 16 and 140 | From left installed edge
wood_mount_z | 28 and 70 | From bottom installed edge
wood_screw_clearance | 4.5 | Four holes
wood_screw_head_recess | 9.5 | Maximum head diameter
wood_driver_access | 11 | Straight access tunnel from open face to each screw
cable_exit | 42x20 | Centered at lower rear
registration_rails | 1.2 | Same faceplate seating datum as boss faces

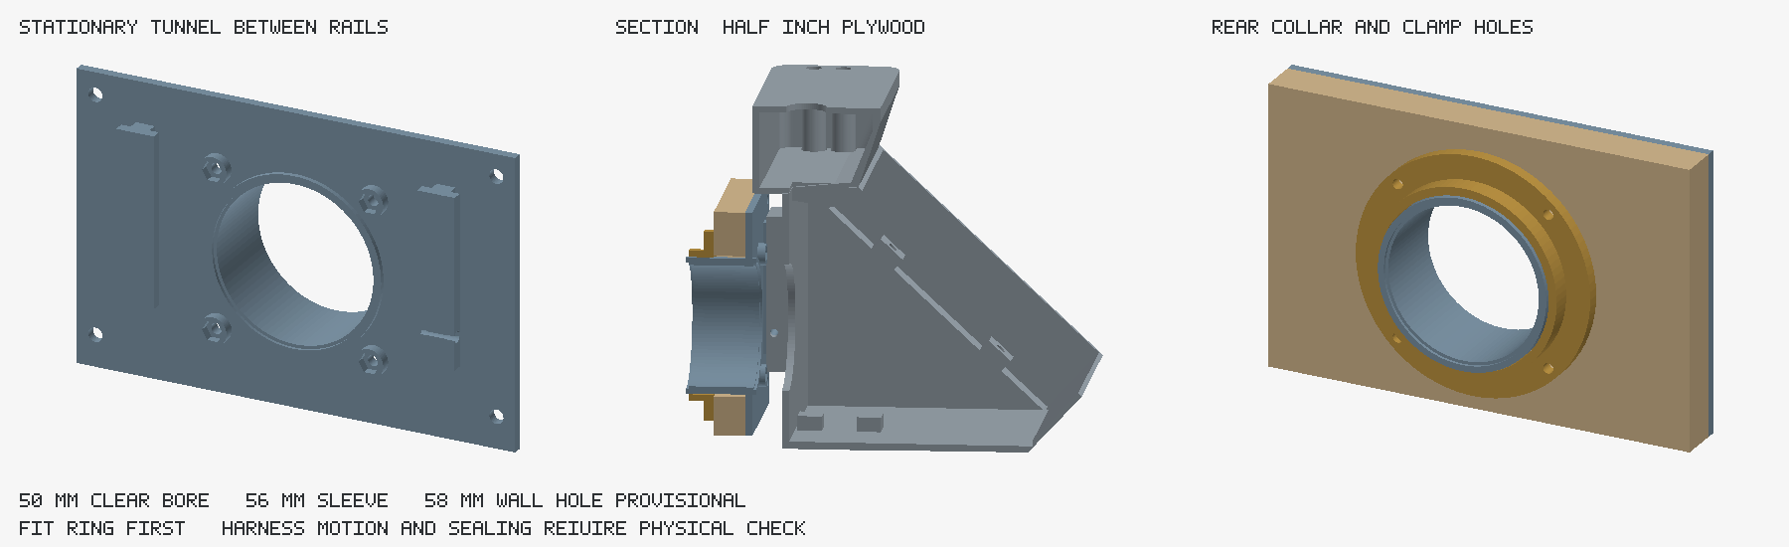
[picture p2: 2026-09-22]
mechanical/enclosure/mounting/rear-tunnel-r1/REAR_TUNNEL_R1_preview.png

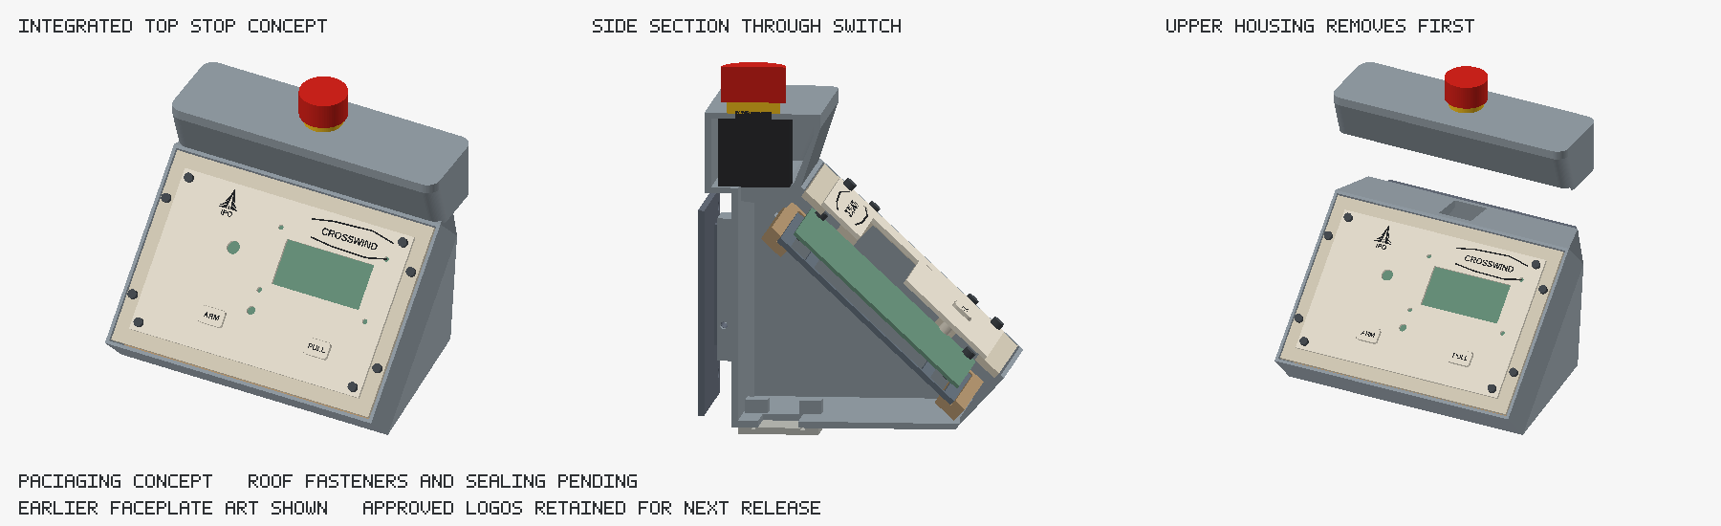
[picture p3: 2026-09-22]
mechanical/enclosure/controls/stop/top-mounted/TOP_STOP_concept_preview.png

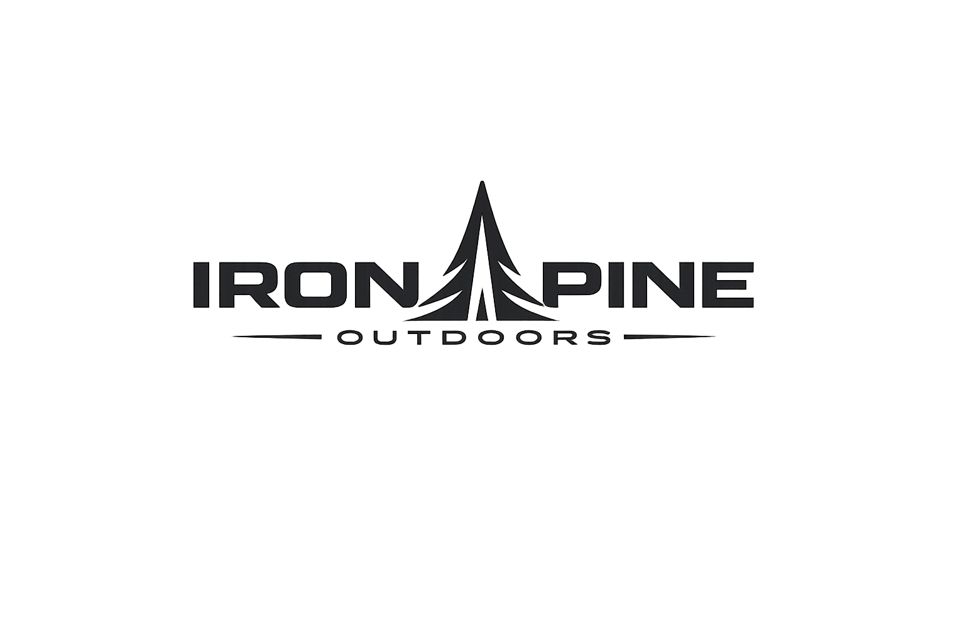
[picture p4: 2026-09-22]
mechanical/enclosure/branding/iron_pine_transparent_wordmark.png

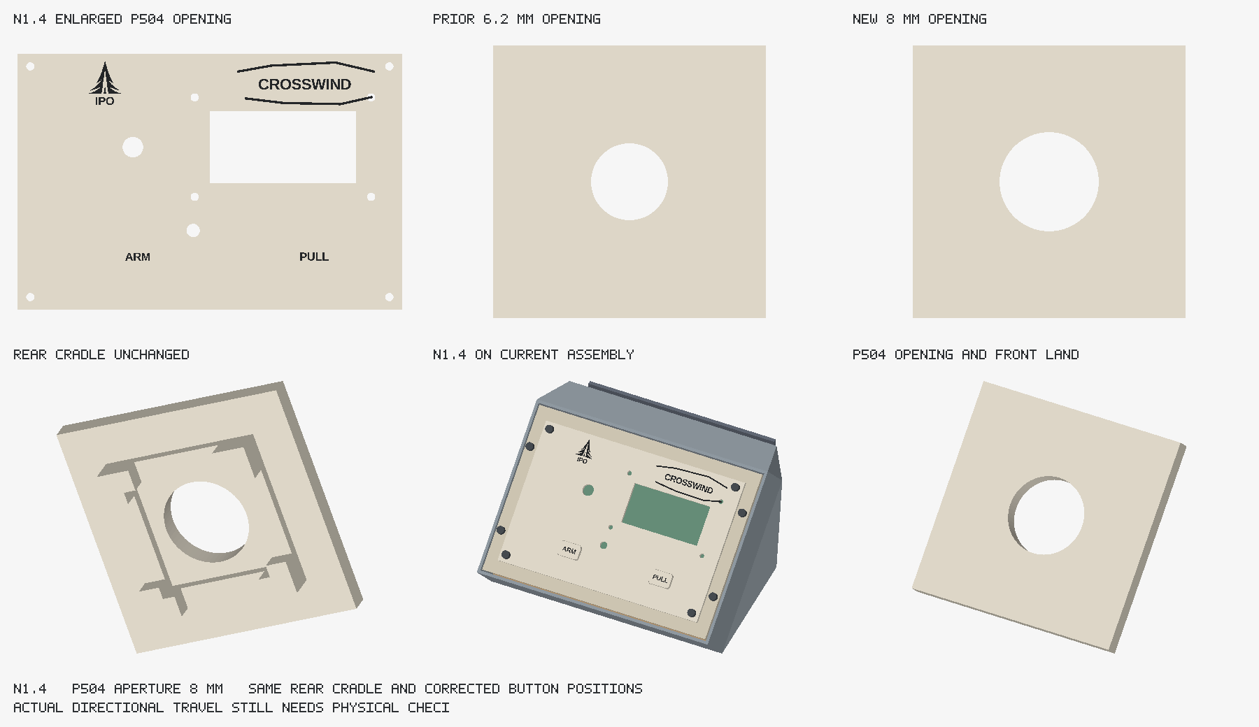
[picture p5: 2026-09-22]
mechanical/enclosure/faceplate/N14_faceplate_preview.png

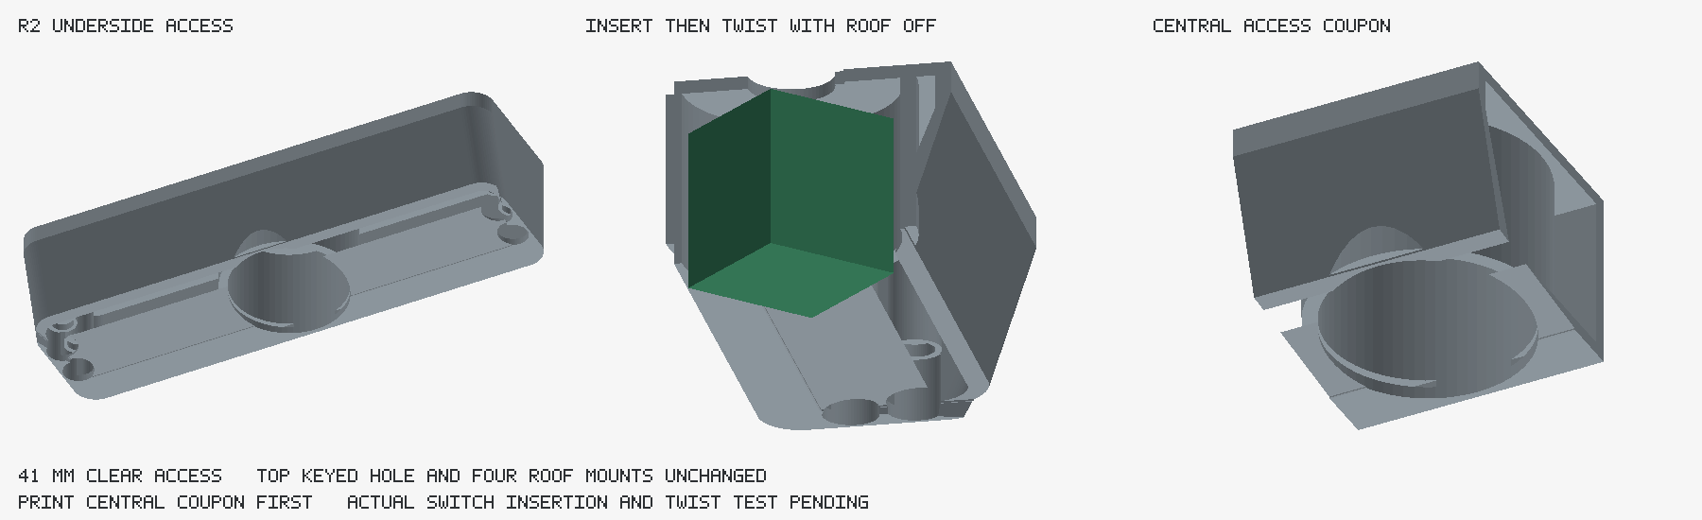
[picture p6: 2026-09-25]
mechanical/enclosure/controls/stop/top-mounted/TOP_STOP_R2_preview.png

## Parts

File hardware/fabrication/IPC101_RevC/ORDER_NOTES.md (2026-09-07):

# IPC-101 Rev C prototype order

Recommended first order: two assembled prototype boards. Do not order production quantity until the received Adafruit 504, OLED, caps, and faceplate have passed physical fit testing.

## Solder-mask correction ? 2026-09-07

Upload **`IPC101_RevC_MaskFix_Gerbers.zip`** as the replacement manufacturing file. The earlier `IPC101_RevC_Gerbers.zip` is obsolete and must not be uploaded.

The original local package contained 48 top SMT mask openings but no bottom mask openings. All 29 solderable through-hole pads were missing both mask layers in the source PCB. This revision adds both layers to those pads: the corrected exports have 77 top openings and 29 bottom openings. JLCPCB reported both mask layers missing from the submitted order; the exact earlier portal upload has not been recovered, so that discrepancy cannot be resolved from the local archive alone.

Solder mask is required on **both sides with openings at the solderable pads**. Neither all-over tin nor all-over mask ink is intended. In the replacement-file viewer, confirm the top and bottom mask layers are recognized and the through-hole component pads are exposed on both faces. The board dimensions, copper, drills, placement, BOM, and CPL are unchanged by this correction. The D1 reference label moved to the fabrication layer to clear the newly exposed LED pads. Continue to use the existing Rev C BOM and CPL.

The package generator now checks every solderable pad for its required mask layer, verifies mask flashes at pad centres in both generated Gerbers and the ZIP, and stops on any KiCad or validation failure.

## PCB fabrication settings

- Dimensions: 150 x 100 mm
- Layers: 2
- Material: FR-4
- Finished thickness: 1.6 mm
- Copper: 1 oz
- Solder mask: both sides, openings at solderable pads; color is customer preference
- Surface finish: lead-free HASL or ENIG; ENIG is preferred for the fine-pitch U1 prototype
- Minimum track/space: 0.20/0.15 mm
- Minimum finished drill: 0.30 mm
- Impedance control: no
- Castellated holes: no
- Edge plating: no
- Gold fingers: no
- Panelization: no; single design

Upload `IPC101_RevC_MaskFix_Gerbers.zip` for PCB fabrication.

## JLCPCB assembly settings

- Assembly side: top only
- Quantity: 2 prototypes
- Upload `IPC101_RevC_JLCPCB_BOM.csv` as the BOM.
- Upload `IPC101_RevC_JLCPCB_CPL.csv` as the component placement file.
- Confirm every footprint overlay in JLCPCB's viewer, especially U1 pin 1 and J1 mating direction. J2 and J4 are hand-installed.
- Approve any unavoidable rotation correction only after comparing the viewer with `IPC101_RevC_assembly_reference.pdf`.
- Do not substitute U1 with a different package or suffix.

SW1, SW2, SW3, D1, J2, J3, J4, the test loops, and the faceplate-mounted OLED are intentionally excluded from SMT assembly; see `IPC101_RevC_HAND_INSTALL.csv`. The OLED branch enters IPC-101 at J4 and leaves at J2; continuity-check all five pins before attaching the display.

## Release checks already completed

- KiCad full DRC: 0 violations, 0 unconnected pads
- KiCad error-level ERC: 0 violations
- Gerber layers and separate PTH/NPTH Excellon drill files generated
- Board statistics confirm a 150 x 100 mm, two-layer, 1.6 mm design

Inventory and assembly-library availability can change between quote and order. The LCSC identifiers in the BOM were checked on 2026-09-04, but the ordering portal remains authoritative at checkout.

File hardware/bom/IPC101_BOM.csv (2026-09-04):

Reference | Qty | Function | Manufacturer | MPN | Supplier | Supplier_SKU | Package_or_Form | Unit_USD_2026-09-01 | Lifecycle | Footprint | Datasheet | Notes
U1 | 1 | Keypad scanner | Texas Instruments | TCA8418RTWR | LCSC | C138713 | WQFN-24 4x4 exposed pad | 1.18 | Active | Package_DFN_QFN:WQFN-24-1EP_4x4mm_P0.5mm_EP2.7x2.7mm | https://www.ti.com/lit/ds/symlink/tca8418.pdf | Fixed 7-bit address 0x34; stencil/reflow
SW1 SW2 | 2 | ARM and PULL tactile | Omron/Aratas | B3F-4055 | DigiKey | SW414-ND | 12x12 mm THT projected plunger | 0.52 | Active | Button_Switch_THT:SW_PUSH_12mm_H7.3mm | https://components.omron.com/us-en/datasheet_pdf/A070-E1.pdf | 260 gf; cap ordered separately
SW3 | 1 | Five-way navigation | Adafruit | 504 | Adafruit | 504 | Through-hole six-pin | 1.95 | Active supplier item | IPC101:Adafruit_504_VERIFY | https://www.adafruit.com/product/504 | FAB HOLD: verify footprint against received sample
J1 | 1 | IPC-100 J10 input | JST | SM04B-GHS-TB(LF)(SN) | LCSC | C189895 | JST GH horizontal SMT 4-pin 1.25mm | 1.10 | Active | Connector_JST:JST_GH_SM04B-GHS-TB_1x04-1MP_P1.25mm_Horizontal | https://www.jst-mfg.com/product/pdf/eng/eGH.pdf | Mate GHR-04V-S and SSHL-002T-P0.2
J2 | 1 | OLED harness output | JST | B5B-XH-A(LF)(SN) | Hand install | VERIFY_AT_PO | JST XH vertical THT 5-pin 2.50mm | TBD | Active | Connector_JST:JST_XH_B5B-XH-A_1x05_P2.50mm_Vertical | https://www.jst-mfg.com/product/pdf/eng/eXH.pdf | Pins 1-5 OLED_VCC OLED_GND OLED_SDA OLED_SCL OLED_RESET
J3 | 1 | STOP isolated pass-through | Phoenix Contact | MC 1/ 2-G-3.81 | Phoenix Contact | VERIFY_AT_PO | 2-pin 3.81mm header | 2.50 | Active | TerminalBlock_Phoenix:PhoenixContact_MC_1.5_2-G-3.81_1x02_P3.81mm_Horizontal | https://www.phoenixcontact.com/ | Final order code/mate must match harness release
J4 | 1 | IPC-100 J6 OLED input | JST | SM05B-GHS-TB(LF)(SN) | Hand install | VERIFY_AT_PO | JST GH horizontal SMT 5-pin 1.25mm | TBD | Active | Connector_JST:JST_GH_SM05B-GHS-TB_1x05-1MP_P1.25mm_Horizontal | https://www.jst-mfg.com/product/pdf/eng/eGH.pdf | Mate GHR-05V-S; pins pass straight through to J2
C1 | 1 | Local bypass | TDK | C2012X7R1H104K125AA | DigiKey | 445-1345-1-ND | 0805 X7R 100nF 50V | 0.10 | Active | Capacitor_SMD:C_0805_2012Metric | https://product.tdk.com/ | At U1 VCC
C2 | 1 | Bulk bypass | TDK | C2012X5R1A475K125AB | DigiKey | 445-1412-1-ND | 0805 X5R 4.7uF 10V | 0.18 | Active | Capacitor_SMD:C_0805_2012Metric | https://product.tdk.com/ | Near J1
R1 | 1 | RESET pull-up | Panasonic | ERJ-6ENF1002V | DigiKey | P10.0KCCT-ND | 0805 10k 1% | 0.10 | Active | Resistor_SMD:R_0805_2012Metric | https://industrial.panasonic.com/ | No I2C pull-ups fitted
TP1 TP2 TP3 TP4 | 4 | Test points | Keystone | 5015 | DigiKey | 36-5015-ND | 1mm THT loop | 0.45 | Active | TestPoint:TestPoint_Loop_D1.0mm_Drill0.5mm | https://www.keyelco.com/ | 3V3 GND SDA SCL
R2 R3 R4 | 3 | RGB current limit | UNI-ROYAL | 0805W8F1001T5E | LCSC | C17513 | 0805 1k 1% | 0.01 | Active | Resistor_SMD:R_0805_2012Metric | https://www.lcsc.com/product-detail/C17513.html | One per RGB cathode
D1 | 1 | Status indicator | Generic | 5mm common-anode RGB LED | Hand install | VERIFY_LEAD_ORDER | 5mm THT four-lead | TBD | Verify received part | IPC101:LED_RGB_5MM_CA | NA | Confirm R-A-G-B lead order before soldering
DS1 | 1 | OLED prototype module | Hosyond | B0G2RFLG1L | Amazon | B0G2RFLG1L | 2.42in 128x64 I2C SSD1309; 5-pin 2.54mm header | TBD | Prototype candidate | FACEPLATE_MOUNT | https://www.amazon.com/dp/B0G2RFLG1L | Mounted to faceplate; short keyed harness to IPC-101 J2
SSTOP | 1 | Panel STOP operator | Omron | A22NE-M-PD01-N | Mouser | VERIFY_AT_PO | 22mm push-lock turn-reset NC | 35.00 | Verify order code | PANEL_MOUNT | https://components.omron.com/ | System safety review and exact contact block required
H1 H2 H3 H4 | 4 | PCB mounting | Generic | M3 hardware | McMaster-Carr | APPLICATION_SPECIFIC | M3 standoff/fastener | TBD | Active | MountingHole:MountingHole_3.2mm_M3 | NA | Metalwork outside copper keepout

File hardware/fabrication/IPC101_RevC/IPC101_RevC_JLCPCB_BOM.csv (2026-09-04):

Comment | Designator | Footprint | LCSC Part # | Manufacturer Part # | Quantity
TCA8418 keypad GPIO controller | U1 | WQFN-24-EP 4x4mm P0.5mm | C138713 | TCA8418RTWR | 1
10k 1% 0805 | R1 | 0805 | C17414 | 0805W8F1002T5E | 1
1k 1% 0805 | R2,R3,R4 | 0805 | C17513 | 0805W8F1001T5E | 3
100nF 50V X7R 0805 | C1 | 0805 | C49678 | CC0805KRX7R9BB104 | 1
4.7uF 25V X5R 0805 | C2 | 0805 | C1779 | CL21A475KAQNNNE | 1
JST GH 4-pin horizontal SMT | J1 | JST-GH-4 1.25mm | C189895 | SM04B-GHS-TB(LF)(SN) | 1

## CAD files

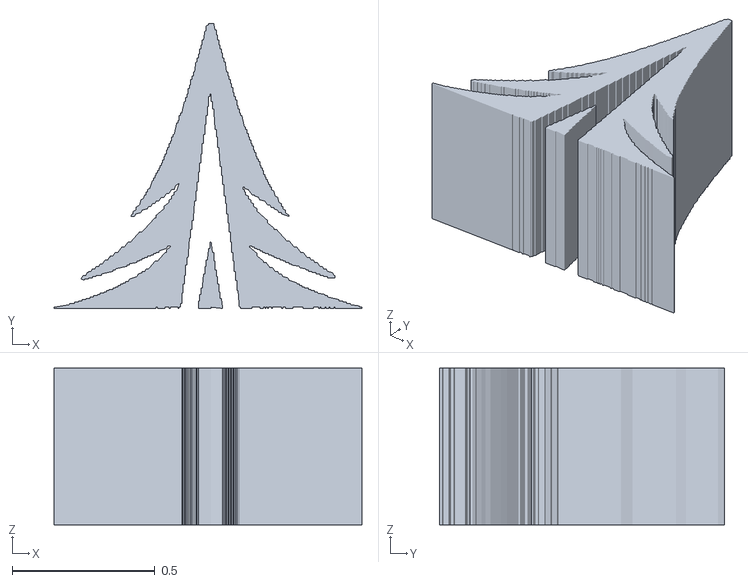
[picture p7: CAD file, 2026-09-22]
mechanical/enclosure/branding/iron_pine_tree_unit.stl
1.08 x 1.00 x 0.55

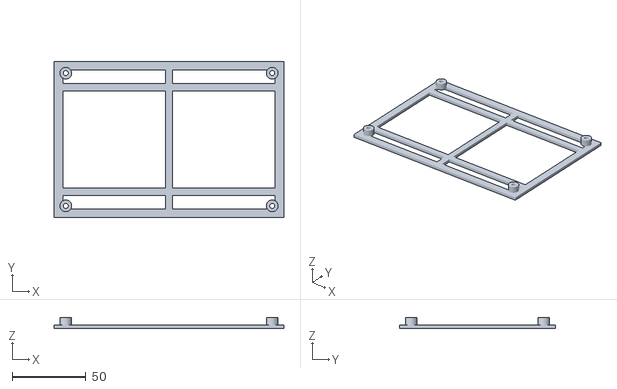
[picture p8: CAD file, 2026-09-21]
mechanical/enclosure/carrier/IPC101_RevA_RearCarrier_R3.stl
156.0 x 106.0 x 7.40

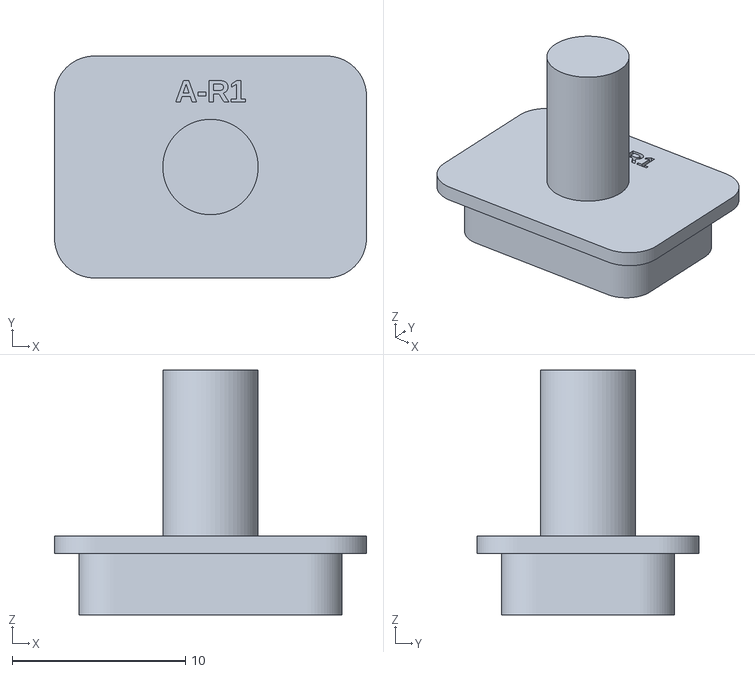
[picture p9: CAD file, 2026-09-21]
mechanical/enclosure/controls/buttons/CrossWind_IPC101_ARM_Cap_R1_WHITE_PETGHF.stl
18.0 x 12.8 x 14.1

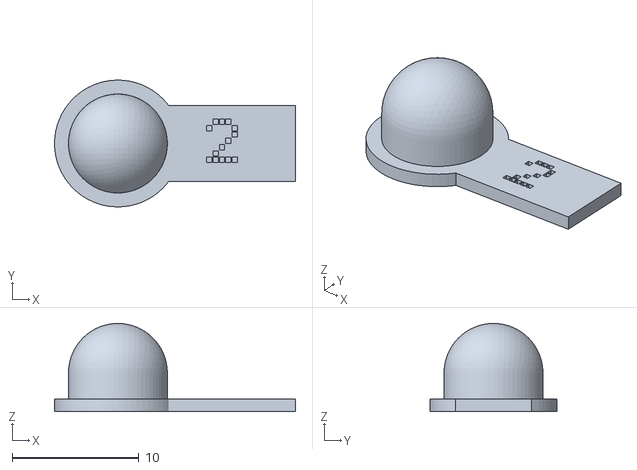
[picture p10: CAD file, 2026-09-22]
mechanical/enclosure/controls/led/CrossWind_IPC101_LED_R1_Bubble_2_Bore5.5_PRINT.stl
19.0 x 10.0 x 6.95

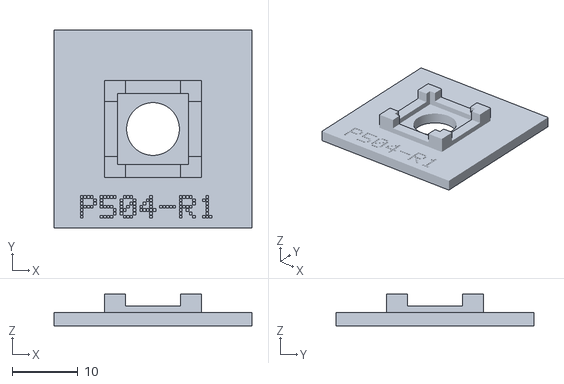
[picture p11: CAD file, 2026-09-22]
mechanical/enclosure/controls/navigation/CrossWind_IPC101_P504_Clearance_R1_8mm_PRINT.stl
30.0 x 30.0 x 4.80

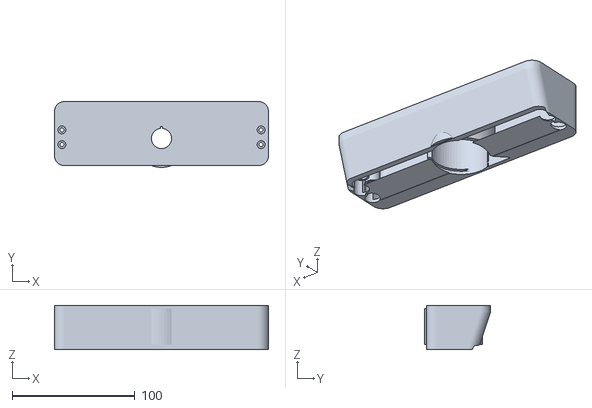
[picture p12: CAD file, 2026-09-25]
mechanical/enclosure/controls/stop/top-mounted/CrossWind_IPC101_Top_STOP_Roof_R4_INSTALLED.stl
174.0 x 53.5 x 36.0

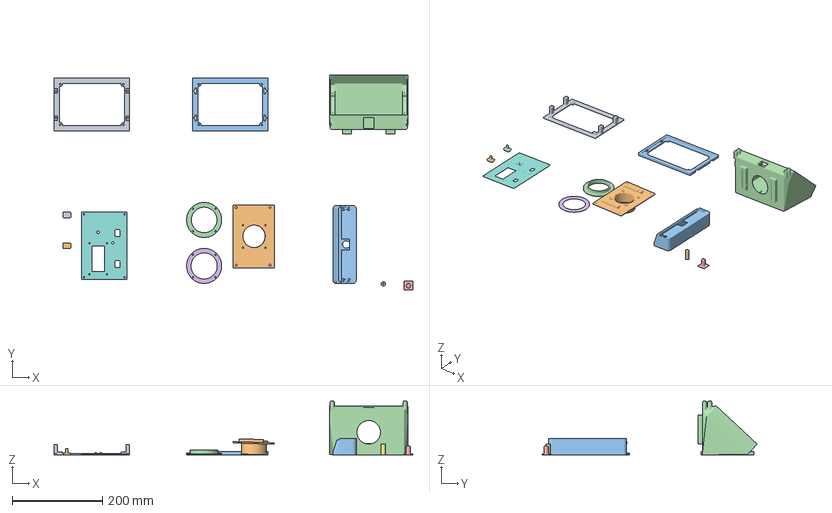
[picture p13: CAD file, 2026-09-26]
mechanical/enclosure/CrossWind_IPC101_Box.3mf
796.7 x 478.1 x 119.0 mm
CrossWind_IPC101_Bezel_RevI1_PRINT.stl
CrossWind_IPC101_Rear_Tunnel_Bracket_R1_PRINT.stl
CrossWind_IPC101_Top_STOP_Roof_R1_PRINT.stl
CrossWind_IPC101_Rear_Tunnel_Collar_R1_PRINT.stl
CrossWind_IPC101_Top_STOP_Pilot_Coupon_R1_PRINT.stl
CrossWind_IPC101_Rear_Tunnel_Wall_Template_R1_PRINT.stl
CrossWind_IPC101_Top_STOP_Roof_Coupon_R1_PRINT.stl
CrossWind_IPC101_Faceplate_RevN13_BLACK_AMS
CrossWind_IPC101_ARM_Cap_R1_BLACK_AMS
CrossWind_IPC101_PULL_Cap_R1_BLACK_AMS
CrossWind_IPC101_Cradle_RevI1_PRINT.stl
CrossWind_IPC101_Rear_Tunnel_Base_R1_PRINT.stl

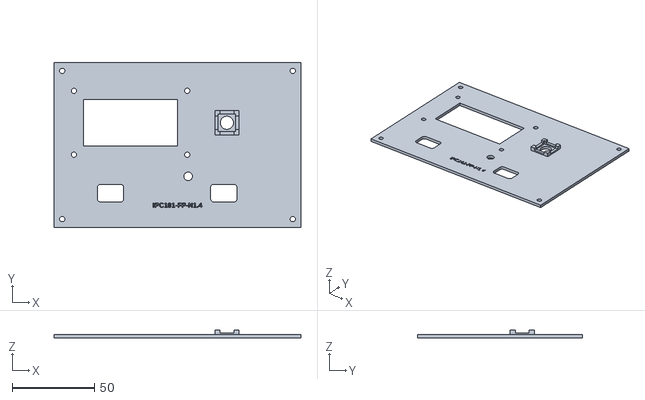
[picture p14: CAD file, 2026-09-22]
mechanical/enclosure/faceplate/CrossWind_IPC101_Faceplate_RevN14_WHITE_PETGHF.stl
150.0 x 100.0 x 4.80

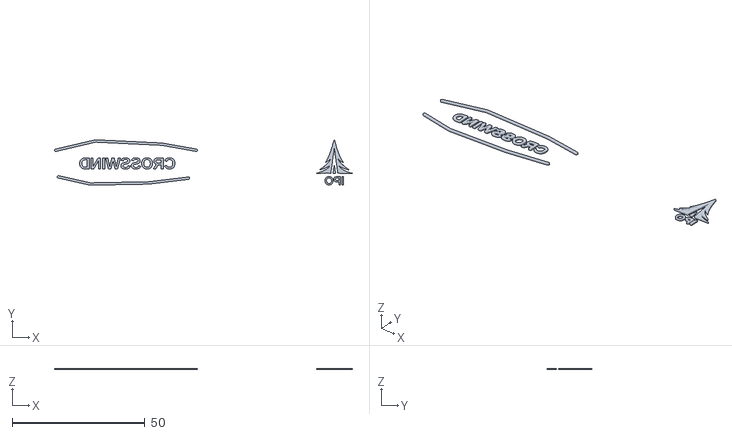
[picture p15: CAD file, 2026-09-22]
mechanical/enclosure/faceplate/history/CrossWind_IPC101_Faceplate_RevN13_BLACK_AMS.stl
112.2 x 17.1 x 0.55

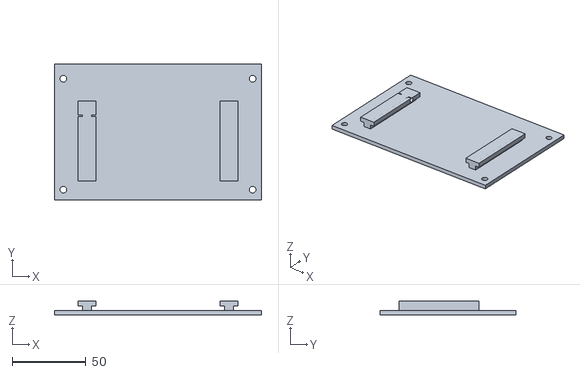
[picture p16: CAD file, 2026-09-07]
mechanical/enclosure/mounting/CrossWind_IPC101_Bracket_RevH_PRINT.stl
140.0 x 92.0 x 9.70

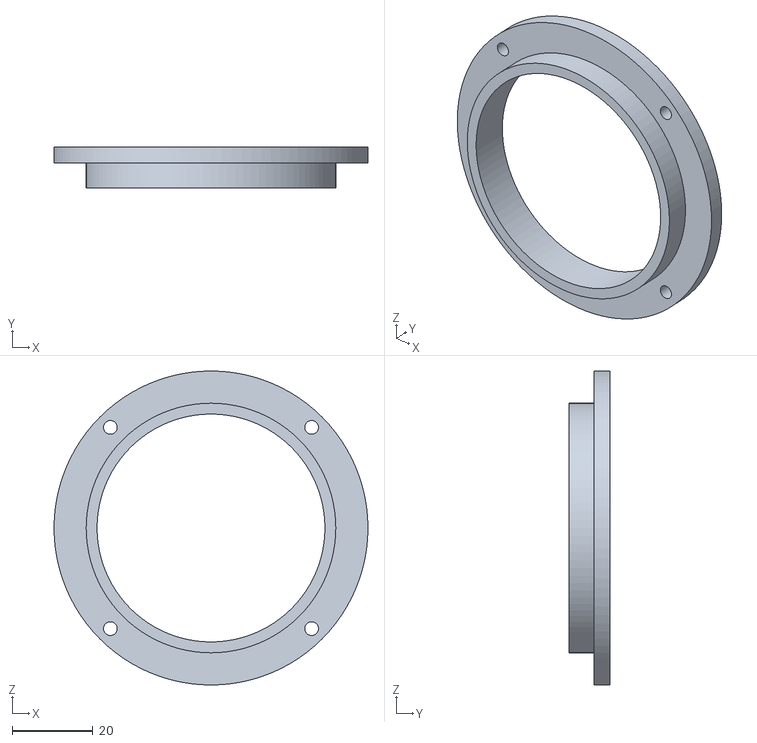
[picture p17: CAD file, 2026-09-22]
mechanical/enclosure/mounting/rear-tunnel-r1/CrossWind_IPC101_Rear_Tunnel_Collar_R1_INSTALLED.stl
78.0 x 10.3 x 78.0

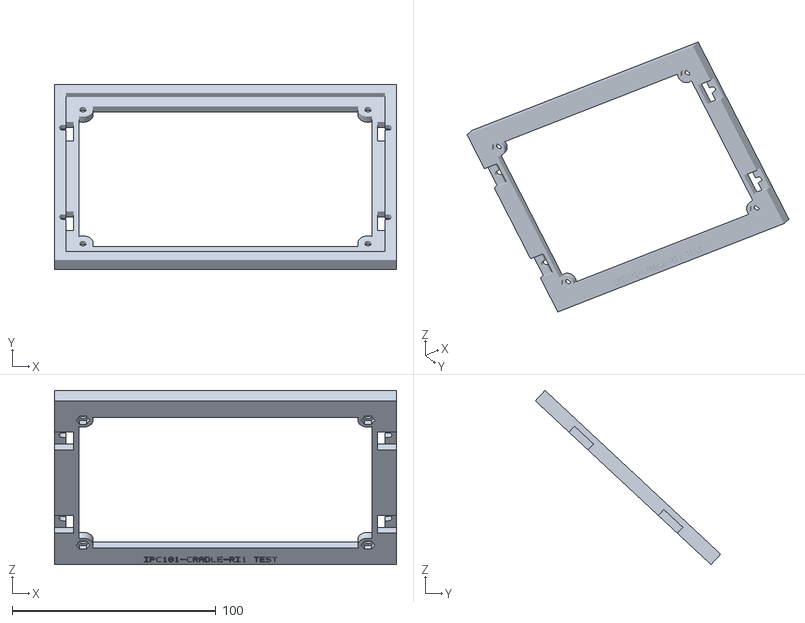
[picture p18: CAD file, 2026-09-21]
mechanical/enclosure/structure/CrossWind_IPC101_Cradle_RevI1_INSTALLED.stl
168.0 x 91.1 x 85.6

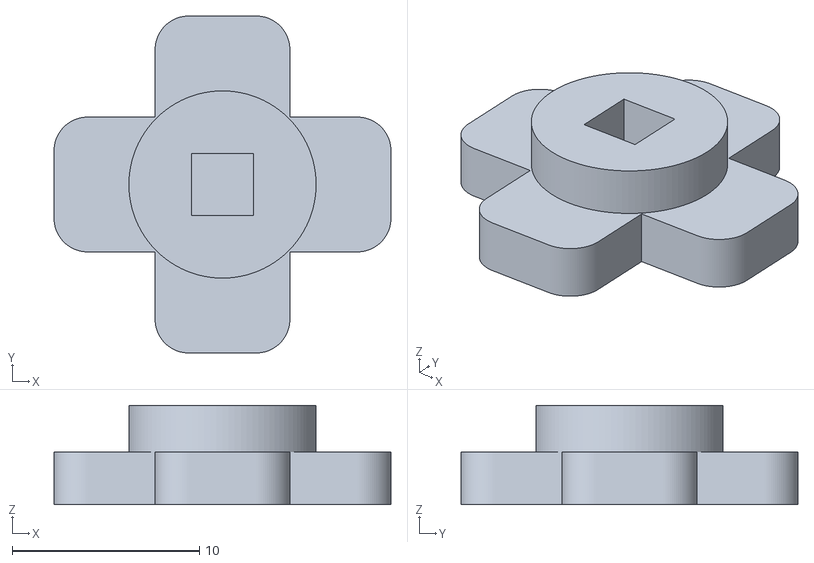
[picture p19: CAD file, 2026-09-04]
mechanical/panel/CrossWind_Adafruit504_Nav_Cap_RevC_IPC101.stl
18.0 x 18.0 x 5.30

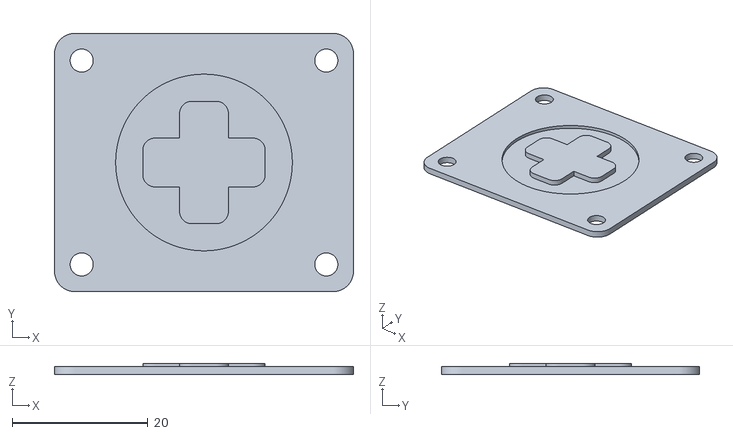
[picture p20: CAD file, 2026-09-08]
mechanical/panel/tpu-prototypes/P504_TPU_WEB_0.6mm.stl
44.0 x 38.0 x 1.60

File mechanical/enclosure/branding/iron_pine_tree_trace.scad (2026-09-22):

// Generated from the alpha silhouette of the user-provided wordmark.
// Unit height, centered X, bottom Y=0. Two original black components.
module iron_pine_tree_2d(){ union(){
polygon(points=[[-0.2219731, 0.3991031], [-0.2264574, 0.3856502], [-0.235426, 0.3811659], [-0.2399103, 0.3632287], [-0.2533632, 0.3542601], [-0.2533632, 0.3452915], [-0.2623318, 0.3408072], [-0.2623318, 0.3318386], [-0.2668161, 0.3318386], [-0.2713004, 0.32287], [-0.2578475, 0.32287], [-0.2533632, 0.3318386], [-0.235426, 0.3363229], [-0.2309417, 0.3452915], [-0.2130045, 0.3497758], [-0.2085202, 0.3587444], [-0.1995516, 0.3587444], [-0.1950673, 0.367713], [-0.1860987, 0.367713], [-0.1816143, 0.3766816], [-0.1726457, 0.3766816], [-0.1636771, 0.3901345], [-0.1547085, 0.3901345], [-0.1457399, 0.4035874], [-0.1367713, 0.4035874], [-0.1278027, 0.4170404], [-0.1188341, 0.4170404], [-0.1143498, 0.4304933], [-0.1008969, 0.4394619], [-0.1098655, 0.4125561], [-0.1188341, 0.4080717], [-0.1188341, 0.3991031], [-0.1278027, 0.3946188], [-0.1278027, 0.3856502], [-0.1367713, 0.3811659], [-0.1367713, 0.3721973], [-0.1547085, 0.3587444], [-0.1547085, 0.3497758], [-0.1816143, 0.3273543], [-0.1816143, 0.3183857], [-0.1860987, 0.3183857], [-0.2309417, 0.2690583], [-0.2399103, 0.2690583], [-0.2713004, 0.2331839], [-0.2802691, 0.2331839], [-0.293722, 0.2152466], [-0.3026906, 0.2152466], [-0.3161435, 0.1973094], [-0.3251121, 0.1973094], [-0.3340807, 0.1838565], [-0.3430493, 0.1838565], [-0.3430493, 0.1793722], [-0.3475336, 0.1793722], [-0.3520179, 0.1704036], [-0.3609865, 0.1704036], [-0.3699552, 0.1569507], [-0.3789238, 0.1569507], [-0.3834081, 0.1479821], [-0.3923767, 0.1479821], [-0.396861, 0.1390135], [-0.4058296, 0.1390135], [-0.4103139, 0.1300448], [-0.4192825, 0.1300448], [-0.4192825, 0.1255605], [-0.4237668, 0.1255605], [-0.4282511, 0.1165919], [-0.4372197, 0.1165919], [-0.4461883, 0.103139], [-0.4327354, 0.0986547], [-0.4327354, 0.103139], [-0.4192825, 0.103139], [-0.4192825, 0.1076233], [-0.4058296, 0.1076233], [-0.4058296, 0.1121076], [-0.3923767, 0.1121076], [-0.3923767, 0.1165919], [-0.3744395, 0.1165919], [-0.3744395, 0.1210762], [-0.3340807, 0.1300448], [-0.3340807, 0.1345291], [-0.3251121, 0.1345291], [-0.3251121, 0.1390135], [-0.2847534, 0.1479821], [-0.2847534, 0.1524664], [-0.2757848, 0.1524664], [-0.2757848, 0.1569507], [-0.2488789, 0.161435], [-0.2488789, 0.1659193], [-0.2399103, 0.1659193], [-0.2399103, 0.1704036], [-0.2309417, 0.1704036], [-0.2309417, 0.1748879], [-0.2219731, 0.1748879], [-0.2219731, 0.1793722], [-0.2130045, 0.1793722], [-0.2130045, 0.1838565], [-0.1995516, 0.1838565], [-0.1995516, 0.1883408], [-0.190583, 0.1883408], [-0.190583, 0.1928251], [-0.1816143, 0.1928251], [-0.1816143, 0.1973094], [-0.1726457, 0.1973094], [-0.1726457, 0.2017937], [-0.1457399, 0.2107623], [-0.1412556, 0.2197309], [-0.132287, 0.2197309], [-0.132287, 0.2152466], [-0.1457399, 0.206278], [-0.1457399, 0.1973094], [-0.1502242, 0.1973094], [-0.17713, 0.1659193], [-0.1860987, 0.1659193], [-0.2085202, 0.1390135], [-0.2174888, 0.1390135], [-0.2219731, 0.1300448], [-0.2309417, 0.1300448], [-0.2309417, 0.1255605], [-0.2443946, 0.1210762], [-0.2488789, 0.1121076], [-0.2757848, 0.103139], [-0.2802691, 0.0941704], [-0.2892377, 0.0941704], [-0.2892377, 0.0896861], [-0.2982063, 0.0896861], [-0.2982063, 0.0852018], [-0.3071749, 0.0852018], [-0.3071749, 0.0807175], [-0.3161435, 0.0807175], [-0.3161435, 0.0762332], [-0.3251121, 0.0762332], [-0.3251121, 0.0717489], [-0.3340807, 0.0717489], [-0.3340807, 0.0672646], [-0.3475336, 0.0672646], [-0.3475336, 0.0627803], [-0.3565022, 0.0627803], [-0.3565022, 0.058296], [-0.3654709, 0.058296], [-0.3654709, 0.0538117], [-0.3789238, 0.0538117], [-0.3789238, 0.0493274], [-0.3878924, 0.0493274], [-0.3878924, 0.044843], [-0.4013453, 0.044843], [-0.4013453, 0.0403587], [-0.4147982, 0.0403587], [-0.4147982, 0.0358744], [-0.4282511, 0.0358744], [-0.4282511, 0.0313901], [-0.441704, 0.0313901], [-0.441704, 0.0269058], [-0.455157, 0.0269058], [-0.455157, 0.0224215], [-0.4686099, 0.0224215], [-0.4686099, 0.0179372], [-0.4865471, 0.0179372], [-0.4865471, 0.0134529], [-0.5403587, 0.0044843], [-0.5403587, 0.0], [-0.1816143, 0.0], [-0.1816143, 0.0044843], [-0.17713, 0.0044843], [-0.17713, 0.0], [-0.1502242, 0.0], [-0.1502242, 0.0044843], [-0.1367713, 0.0044843], [-0.1367713, 0.0], [-0.132287, 0.0], [-0.132287, 0.0044843], [-0.1053812, 0.0044843], [-0.1053812, 0.0], [-0.1008969, 0.0], [-0.1008969, 0.0044843], [-0.0964126, 0.0044843], [-0.0964126, 0.0179372], [-0.0919283, 0.0179372], [-0.0919283, 0.0538117], [-0.0874439, 0.0538117], [-0.0874439, 0.0852018], [-0.0829596, 0.0852018], [-0.0829596, 0.1165919], [-0.0784753, 0.1165919], [-0.0784753, 0.1524664], [-0.073991, 0.1524664], [-0.073991, 0.1793722], [-0.0695067, 0.1793722], [-0.0650224, 0.2466368], [-0.0605381, 0.2466368], [-0.0605381, 0.2780269], [-0.0560538, 0.2780269], [-0.0560538, 0.309417], [-0.0515695, 0.309417], [-0.0470852, 0.3766816], [-0.0426009, 0.3766816], [-0.0426009, 0.4125561], [-0.0381166, 0.4125561], [-0.0381166, 0.4439462], [-0.0336323, 0.4439462], [-0.0336323, 0.4798206], [-0.029148, 0.4798206], [-0.029148, 0.5112108], [-0.0246637, 0.5112108], [-0.0246637, 0.5426009], [-0.0201794, 0.5426009], [-0.0201794, 0.5784753], [-0.0156951, 0.5784753], [-0.0156951, 0.6098655], [-0.0112108, 0.6098655], [-0.0112108, 0.6457399], [-0.0067265, 0.6457399], [-0.0067265, 0.67713], [-0.0022422, 0.67713], [-0.0022422, 0.7085202], [0.0022422, 0.7085202], [0.0022422, 0.7443946], [0.0067265, 0.7443946], [0.0067265, 0.7533632], [0.0112108, 0.7533632], [0.0112108, 0.7264574], [0.0156951, 0.7264574], [0.0156951, 0.6995516], [0.0201794, 0.6995516], [0.0246637, 0.6278027], [0.029148, 0.6278027], [0.029148, 0.6008969], [0.0336323, 0.6008969], [0.0336323, 0.5650224], [0.0381166, 0.5650224], [0.0426009, 0.4977578], [0.0470852, 0.4977578], [0.0470852, 0.4663677], [0.0515695, 0.4663677], [0.0515695, 0.4349776], [0.0560538, 0.4349776], [0.0560538, 0.3946188], [0.0605381, 0.3946188], [0.0605381, 0.367713], [0.0650224, 0.367713], [0.0650224, 0.3318386], [0.0695067, 0.3318386], [0.0695067, 0.3004484], [0.073991, 0.3004484], [0.073991, 0.2690583], [0.0784753, 0.2690583], [0.0784753, 0.2331839], [0.0829596, 0.2331839], [0.0829596, 0.1973094], [0.0874439, 0.1973094], [0.0874439, 0.1659193], [0.0919283, 0.1659193], [0.0919283, 0.1300448], [0.0964126, 0.1300448], [0.0964126, 0.0986547], [0.1008969, 0.0986547], [0.1008969, 0.0627803], [0.1053812, 0.0627803], [0.1098655, 0.0044843], [0.1143498, 0.0044843], [0.1143498, 0.0], [0.1547085, 0.0], [0.1547085, 0.0044843], [0.1816143, 0.0044843], [0.1816143, 0.0], [0.1950673, 0.0], [0.1950673, 0.0044843], [0.1995516, 0.0044843], [0.1995516, 0.0], [0.2040359, 0.0], [0.2040359, 0.0044843], [0.2085202, 0.0044843], [0.2085202, 0.0], [0.2130045, 0.0], [0.2130045, 0.0044843], [0.2219731, 0.0044843], [0.2219731, 0.0], [0.2264574, 0.0], [0.2264574, 0.0044843], [0.2578475, 0.0044843], [0.2578475, 0.0], [0.2623318, 0.0], [0.2623318, 0.0044843], [0.2713004, 0.0044843], [0.2713004, 0.0], [0.2982063, 0.0], [0.2982063, 0.0044843], [0.3340807, 0.0044843], [0.3340807, 0.0], [0.3699552, 0.0], [0.3699552, 0.0044843], [0.3878924, 0.0044843], [0.3878924, 0.0], [0.3923767, 0.0], [0.3923767, 0.0044843], [0.396861, 0.0044843], [0.396861, 0.0], [0.4103139, 0.0], [0.4103139, 0.0044843], [0.4147982, 0.0044843], [0.4147982, 0.0], [0.4237668, 0.0], [0.4237668, 0.0044843], [0.4282511, 0.0044843], [0.4282511, 0.0], [0.441704, 0.0], [0.441704, 0.0044843], [0.4461883, 0.0044843], [0.4461883, 0.0], [0.5403587, 0.0], [0.5403587, 0.0044843], [0.5313901, 0.0044843], [0.5313901, 0.0089686], [0.5, 0.0134529], [0.5, 0.0179372], [0.4865471, 0.0179372], [0.4865471, 0.0224215], [0.4730942, 0.0224215], [0.4730942, 0.0269058], [0.4596413, 0.0269058], [0.4596413, 0.0313901], [0.4192825, 0.0403587], [0.4192825, 0.044843], [0.4103139, 0.044843], [0.4103139, 0.0493274], [0.3834081, 0.0538117], [0.3834081, 0.058296], [0.3744395, 0.058296], [0.3744395, 0.0627803], [0.3609865, 0.0627803], [0.3609865, 0.0672646], [0.3520179, 0.0672646], [0.3520179, 0.0717489], [0.338565, 0.0717489], [0.338565, 0.0762332], [0.3295964, 0.0762332], [0.3295964, 0.0807175], [0.3206278, 0.0807175], [0.3206278, 0.0852018], [0.3116592, 0.0852018], [0.3116592, 0.0896861], [0.2847534, 0.0986547], [0.2802691, 0.1076233], [0.2623318, 0.1121076], [0.2578475, 0.1210762], [0.2488789, 0.1210762], [0.2443946, 0.1300448], [0.235426, 0.1300448], [0.2264574, 0.1434978], [0.2174888, 0.1434978], [0.2040359, 0.161435], [0.1950673, 0.161435], [0.1950673, 0.1659193], [0.1726457, 0.1838565], [0.1726457, 0.1928251], [0.1457399, 0.2152466], [0.1457399, 0.2197309], [0.1547085, 0.2197309], [0.1547085, 0.2152466], [0.1636771, 0.2152466], [0.1636771, 0.2107623], [0.1726457, 0.2107623], [0.1726457, 0.206278], [0.1816143, 0.206278], [0.1816143, 0.2017937], [0.190583, 0.2017937], [0.190583, 0.1973094], [0.1995516, 0.1973094], [0.1995516, 0.1928251], [0.2130045, 0.1928251], [0.2130045,
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

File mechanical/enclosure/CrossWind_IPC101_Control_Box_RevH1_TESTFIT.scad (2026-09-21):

// CrossWind IPC-101 Control Box Rev H1 TESTFIT
// STATUS: TEST-FIT / NOT FABRICATION-FROZEN
// Corrects Rev H: removes external corner nubs and closes the lower shell.
// Rev G rear wood-mount interface is preserved.

$fn=48;

PANEL_W=150;
PANEL_H=100;
BODY_W=156;
WOOD_H=101.6;
TILT=47;
WALL=3;
FACE_RIM=7;
SIDE_MARGIN=3;

FACE_TO_PCB_TOP=16.5;
PCB_T=1.56;

TOP_PROJECTION=24;
LOWER_Z=12;

WOOD_HOLE_X=[16,140];
WOOD_HOLE_Z=[28,70];
WOOD_PAD_W=24;
WOOD_PAD_H=20;
WOOD_PAD_DEPTH=4;
WOOD_CLEARANCE=4.5;
WOOD_HEAD_D=9.5;
DRIVER_ACCESS_D=11;

CONN_W=34;
CONN_H=26;
CONN_Y=18;
CONN_Z=38;

MARK="IPC101-ENC-RH1 TEST";

run=PANEL_H*sin(TILT);
rise=PANEL_H*cos(TILT);
bot_y=TOP_PROJECTION+run;
bot_z=LOWER_Z;
top_y=TOP_PROJECTION;
top_z=LOWER_Z+rise;

module on_face(){
    multmatrix([
        [1,0,0,SIDE_MARGIN],
        [0,-sin(TILT),-cos(TILT),bot_y],
        [0, cos(TILT),-sin(TILT),bot_z],
        [0,0,0,1]
    ]) children();
}

module beam(width,y,z){ translate([0,y,z]) cube([width,0.2,0.2]); }

module wedge(width,xoff,profile){
    translate([xoff,0,0])
    hull(){ for(p=profile) beam(width,p[0],p[1]); }
}

module shell(){
    outer_profile=[[0,0],[bot_y,bot_z],[top_y,top_z],[0,WOOD_H-0.2]];
    inset_run=FACE_RIM*sin(TILT);
    inset_rise=FACE_RIM*cos(TILT);
    cavity_profile=[
        [WALL,WALL],
        [bot_y-5-inset_run,bot_z+inset_rise+WALL],
        [top_y-5+inset_run,top_z-inset_rise-WALL],
        [WALL,WOOD_H-WALL]
    ];

    difference(){
        wedge(BODY_W,0,outer_profile);
        wedge(BODY_W-2*WALL,WALL,cavity_profile);
        on_face()
            translate([FACE_RIM,FACE_RIM,-2])
                cube([PANEL_W-2*FACE_RIM,PANEL_H-2*FACE_RIM,WALL+5]);
    }
}

module y_cyl(len,d,x,y,z){
    translate([x,y,z]) rotate([-90,0,0]) cylinder(h=len,d=d);
}

module rear_mount_reinforcement(){
    for(x=WOOD_HOLE_X) for(z=WOOD_HOLE_Z)
        translate([x-WOOD_PAD_W/2,0,z-WOOD_PAD_H/2])
            cube([WOOD_PAD_W,WOOD_PAD_DEPTH,WOOD_PAD_H]);
}

module rear_mount_cuts(){
    for(x=WOOD_HOLE_X) for(z=WOOD_HOLE_Z){
        y_cyl(WOOD_PAD_DEPTH+2,WOOD_CLEARANCE,x,-1,z);
        y_cyl(WOOD_PAD_DEPTH,WOOD_HEAD_D,x,1.4,z);
        y_cyl(120,DRIVER_ACCESS_D,x,1.4,z);
    }
}

module side_connector_frame(){
    translate([BODY_W-WALL-2,CONN_Y-3,CONN_Z-3])
        difference(){
            cube([WALL+4,CONN_W+6,CONN_H+6]);
            translate([-1,3,3]) cube([WALL+6,CONN_W,CONN_H]);
        }
}

module side_connector_cut(){
    translate([BODY_W-WALL-3,CONN_Y,CONN_Z])
        cube([WALL+7,CONN_W,CONN_H]);
}

module revision_mark(){
    translate([BODY_W/2,0.7,88]) rotate([90,0,0])
        linear_extrude(height=0.45)
            text(MARK,size=4,halign="center",valign="center",font="Liberation Sans:style=Bold");
}

module rev_h1(){
    difference(){
        union(){
            shell();
            rear_mount_reinforcement();
            side_connector_frame();
        }
        rear_mount_cuts();
        side_connector_cut();
        revision_mark();
    }
}

rev_h1();

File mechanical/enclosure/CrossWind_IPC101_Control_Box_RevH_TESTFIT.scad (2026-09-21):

// CrossWind IPC-101 Control Box Rev H TESTFIT
// 2026-09-20
// STATUS: TEST-FIT / NOT FABRICATION-FROZEN
//
// Rev H preserves the Rev G wood mounting interface but redesigns the
// control-panel volume around IPC-101. The current 16.5 mm faceplate-back to
// PCB-top spacing is provisional and must be physically validated.

$fn=20;

PANEL_W=150;
PANEL_H=100;
BODY_W=156;
WOOD_H=101.6;
TILT=47;
WALL=3;

FACE_TO_PCB_TOP=16.5;
PCB_T=1.56;

// Rev G preserved wood mounting interface
WOOD_HOLE_X=[16,140];
WOOD_HOLE_Z=[28,70];
WOOD_CLEARANCE=4.5;
WOOD_HEAD_D=9.5;
DRIVER_D=11;
WOOD_PAD_W=24;
WOOD_PAD_H=20;
WOOD_PAD_DEPTH=4;

FACE_MARGIN=3;
FRONT_EXTENSION=24; // TEST-FIT value, not frozen

// Generic rear connector cassette bay. Connector-specific insert remains TBD.
CONN_BAY_W=34;
CONN_BAY_H=26;
CONN_BAY_Z=43;

MARK="IPC101-ENC-RH TEST";

run=PANEL_H*sin(TILT);
rise=PANEL_H*cos(TILT);
top_y=8+FRONT_EXTENSION;
bot_y=top_y+run;
bot_z=7.5;
top_z=bot_z+rise;

module outer_shell(){
    difference(){
        linear_extrude(height=BODY_W)
            polygon(points=[[0,0],[bot_y,bot_z],[top_y,top_z],[0,WOOD_H]]);
        translate([WALL,0,WALL])
            linear_extrude(height=BODY_W-2*WALL)
                polygon(points=[[0,0],[bot_y-WALL*1.5,bot_z+WALL],[top_y-WALL*1.5,top_z-WALL],[0,WOOD_H-2*WALL]]);
    }
}

module installed_shell(){
    multmatrix([[0,0,1,0],[1,0,0,0],[0,1,0,0],[0,0,0,1]]) outer_shell();
}

function face_pt(px,py,n=0)=[FACE_MARGIN+px,
    bot_y-py*sin(TILT)-n*cos(TILT),
    bot_z+py*cos(TILT)-n*sin(TILT)];

module rod_between(a,b,d){
    hull(){ translate(a) sphere(d=d); translate(b) sphere(d=d); }
}

module wood_mount_pads(){
    for(x=WOOD_HOLE_X) for(z=WOOD_HOLE_Z)
        translate([x-WOOD_PAD_W/2,0,z-WOOD_PAD_H/2])
            cube([WOOD_PAD_W,WOOD_PAD_DEPTH,WOOD_PAD_H]);
}

module wood_mount_cuts(){
    for(x=WOOD_HOLE_X) for(z=WOOD_HOLE_Z){
        translate([x,-1,z]) rotate([-90,0,0]) cylinder(h=WOOD_PAD_DEPTH+3,d=WOOD_CLEARANCE);
        translate([x,1.4,z]) rotate([-90,0,0]) cylinder(h=WOOD_PAD_DEPTH+2,d=WOOD_HEAD_D);
        translate([x,1.4,z]) rotate([-90,0,0]) cylinder(h=120,d=DRIVER_D);
    }
}

PANEL_HOLES=[[5,5],[145,5],[5,95],[145,95]];

module stack_bosses(){
    for(h=PANEL_HOLES){
        p0=face_pt(h[0],h[1],2.0);
        p1=face_pt(h[0],h[1],FACE_TO_PCB_TOP);
        p2=face_pt(h[0],h[1],FACE_TO_PCB_TOP+PCB_T+7.0);
        rod_between(p0,p1,8);
        rod_between(p1,p2,11);
    }
}

module stack_holes(){
    for(h=PANEL_HOLES){
        p0=face_pt(h[0],h[1],-2);
        p2=face_pt(h[0],h[1],FACE_TO_PCB_TOP+PCB_T+9);
        rod_between(p0,p2,3.3);
    }
}

module connector_bay_cut(){
    translate([(BODY_W-CONN_BAY_W)/2,-1,CONN_BAY_Z-CONN_BAY_H/2])
        cube([CONN_BAY_W,10,CONN_BAY_H]);
}

module connector_bay_lip(){
    translate([(BODY_W-CONN_BAY_W)/2-3,0.5,CONN_BAY_Z-CONN_BAY_H/2-3])
        difference(){
            cube([CONN_BAY_W+6,3,CONN_BAY_H+6]);
            translate([3,-1,3]) cube([CONN_BAY_W,5,CONN_BAY_H]);
        }
}

module rev_mark(){
    translate([BODY_W/2,0.6,82]) rotate([90,0,0])
        linear_extrude(height=0.45)
            text(MARK,size=4,halign="center",valign="center",font="Liberation Sans:style=Bold");
}

module rev_h(){
    difference(){
        union(){
            installed_shell();
            wood_mount_pads();
            stack_bosses();
            connector_bay_lip();
        }
        wood_mount_cuts();
        stack_holes();
        connector_bay_cut();
        rev_mark();

        // Generous first-pass control-panel service opening.
        hull(){
            for(px=[5,145],py=[5,95]){
                p=face_pt(px,py,-1);
                q=face_pt(px,py,35);
                translate(p) cube([1,1,1],center=true);
                translate(q) cube([1,1,1],center=true);
            }
        }
    }
}

rev_h();

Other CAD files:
mechanical/enclosure/controls/buttons/CrossWind_IPC101_PULL_Cap_R1_BLACK_AMS.stl
mechanical/enclosure/controls/led/CrossWind_IPC101_LED_R1_Bubble_3_Bore5.7_PRINT.stl
mechanical/enclosure/controls/stop/top-mounted/CrossWind_IPC101_Top_STOP_Roof_R4_PRINT.stl
mechanical/enclosure/CrossWind_IPC101_Box_RevI_PRINT.stl
mechanical/enclosure/CrossWind_IPC101_Control_Box_RevH2_TESTFIT.scad
mechanical/enclosure/CrossWind_IPC101_Box_RevI_INSTALLED.stl
mechanical/enclosure/CrossWind_IPC101_Carrier_RevI_INSTALLED.stl
mechanical/enclosure/CrossWind_IPC101_Carrier_RevI_PRINT.stl
mechanical/enclosure/CrossWind_IPC101_Control_Box_RevG_INSTALLED.stl
mechanical/enclosure/CrossWind_IPC101_Control_Box_RevG_PRINT.stl
mechanical/enclosure/archive/exploratory-h-h1-h2/CrossWind_IPC101_Control_Box_RevH2_TESTFIT.scad
mechanical/enclosure/carrier/IPC101_RevA_RearCarrier_R3.scad
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

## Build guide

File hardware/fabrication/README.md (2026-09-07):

# Fabrication outputs

The validated IPC-101 Rev C order package is in `IPC101_RevC/`.

Use these three files for a JLCPCB PCB-plus-assembly quote:

- `IPC101_RevC_MaskFix_Gerbers.zip`
- `IPC101_RevC_JLCPCB_BOM.csv`
- `IPC101_RevC_JLCPCB_CPL.csv`

The Gerber ZIP contains both copper layers, paste, mask, silkscreen, board outline, and separate PTH/NPTH drill files. The BOM/CPL cover the selected top-side SMT assembly only. Controls, LED, OLED pass-through connectors J2/J4, STOP connector, test loops, OLED, caps, and mechanical hardware are listed separately for hand installation.

Read `IPC101_RevC/ORDER_NOTES.md` before uploading. Inspect every layer in the manufacturer's viewer and confirm U1 pin 1 and J1 mating direction before approving production.

Source validation reports remain under `hardware/kicad/`:

- DRC: 0 violations and 0 unconnected pads
- ERC: 0 errors

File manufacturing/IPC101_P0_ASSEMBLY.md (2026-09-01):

# IPC-101 P0 Assembly and Inspection

1. Order one SW3 and U1 before PCB release. Overlay both on 1:1 footprint plots.
2. Stencil and reflow U1 first; inspect exposed-pad wetting by process coupon/X-ray if available.
3. Fit 0805 passives and J1, then verify 3V3-to-GND resistance and U1 pin-1 orientation.
4. Fit SW1/SW2/SW3 without mechanical preload. Keep flux/residue out of switch bodies.
5. Fit J3 but maintain its isolated-net clearance; do not connect either STOP net to fixture ground.
6. Install test loops and mechanically mount the OLED only after electrical inspection.
7. Clean only with processes approved for the selected switches/connectors. Do not wash unsealed tactiles by default.
8. Apply board serial/revision label and inspect all front/rear legends.

P0 is prototype workmanship, IPC-A-610 Class 2 target. Conformal coating, sealing, cap adhesive, and final torque remain blocked on enclosure/material selection.

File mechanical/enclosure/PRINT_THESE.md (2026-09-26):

# Current IPC-101 print list

Updated 2026-09-26. Current build: rear-entry base and tunnel bracket/collar, R4 STOP roof, I.1 cradle/bezel, R3 carrier and N1.4 faceplate.

## Next: clear LED tests

- [Bubble 2, 5.5 mm pocket](controls/led/CrossWind_IPC101_LED_R1_Bubble_2_Bore5.5_PRINT.stl): clear/translucent material, flange down, dome up, 0.16 mm layers, no internal supports; inspect the slice.
- [Panel-hole strip](controls/led/CrossWind_IPC101_LED_R1_Hole_Strip_PRINT.stl): flat, using the faceplate material/profile.
- Keep bubbles 1 and 3 for alternate fits. See [LED test instructions](controls/led/LED_R1_TEST_PRINTS.md).

These are fit/optical samples, not a completed retainer or weather seal. Rev 2 mounts the LED directly on the PCB.

## Current assembly and replacements

| Part | Print file | Status |
|---|---|---|
| Rear-entry base | [Base](mounting/rear-tunnel-r1/CrossWind_IPC101_Rear_Tunnel_Base_R1_PRINT.stl) | Printed; sidewall damaged during support removal. Use for fits, replace after checks. |
| STOP roof | [R4 roof](controls/stop/top-mounted/CrossWind_IPC101_Top_STOP_Roof_R4_PRINT.stl) | Printed; coupon fit reported perfect. Full clamp-up pending. |
| Tunnel bracket | [Bracket](mounting/rear-tunnel-r1/CrossWind_IPC101_Rear_Tunnel_Bracket_R1_PRINT.stl) | Printed. |
| Tunnel collar | [Collar](mounting/rear-tunnel-r1/CrossWind_IPC101_Rear_Tunnel_Collar_R1_PRINT.stl) | Printed. |
| Cradle | [I.1 cradle](structure/CrossWind_IPC101_Cradle_RevI1_PRINT.stl) | Reuse printed part. |
| Bezel | [I.1 bezel](structure/CrossWind_IPC101_Bezel_RevI1_PRINT.stl) | Reuse existing part. |
| PCB carrier | [R3 carrier](carrier/IPC101_RevA_RearCarrier_R3.stl) | Reuse existing part. |
| Faceplate | [N1.4 white](faceplate/CrossWind_IPC101_Faceplate_RevN14_WHITE_PETGHF.stl) + [black inlay](faceplate/CrossWind_IPC101_Faceplate_RevN14_BLACK_AMS.stl) | Current plate; LED lens opening/retention not finalized. |
| Navigation cap | [P504 cap](../panel/CrossWind_Adafruit504_Nav_Cap_RevC_IPC101.stl) | Retained current navigation cap. |

Keep the [P504 clearance coupon](controls/navigation/P504_DIRECTIONAL_FIT.md), STOP pilot coupon and wall template: their remaining checks have not all been confirmed. Do not cut the plywood before actual harness-motion checks.

R1 ARM/PULL cap files remain in `controls/buttons/` with their labels, but the user trimmed about 1.5 mm from PULL; original exports do not contain that correction. See [cap feedback](controls/buttons/R1_BUTTON_CAPS.md).

## Cleanup and reference geometry

Superseded G/I enclosure exports, old C/D panels and caps, side-pod S1, STOP roofs R1-R3, earlier top-entry base and completed access/bore coupons were removed from the working tree. Recover them from Git history or regenerate from retained sources if needed. No Git history was rewritten.

Older faceplate meshes in `faceplate/history/`, the Rev H mounting meshes and I.1 installed box remain because CAD reference/comparison tools use them. They are not the current print choices. Historical generators may recreate retired exports and their historical verification tools may require regeneration first. `artifact_paths.json` retains historical output destinations for that purpose.

The saved `CrossWind_IPC101_Box.3mf` is retained as a user slicer project; its revision/settings have not been established as the current print authority. TPU experiments remain pending, not confirmed superseded.

Before another large print, finish stack/control fit, roof clamp-up and actual harness slide/removal checks. Sealing remains unfinished.

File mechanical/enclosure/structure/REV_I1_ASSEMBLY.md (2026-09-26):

# Rev I.1 assembly and next print

> Export cleanup, 2026-09-26: superseded print links below are historical. Use `mechanical/enclosure/PRINT_THESE.md` for current parts. Source and Git history retain regeneration/recovery information.

**TEST-FIT - PHYSICAL VALIDATION PENDING.** This is the current R3-compatible fit assembly. Rev I remains historical. Continue the original R3 print already underway; it is reused unchanged.

**M.4 update:** enclosure/faceplate clearance passes, and ARM/PULL/LED positions match with the PCB component side facing the faceplate. The I.1 cradle print is unaffected. See [fit audit](../faceplate/history/REV_M4_FIT_AUDIT.md).

## Print order

1. Finish `IPC101_RevA_RearCarrier_R3.stl`. Check PCB hole alignment, seating and underside component clearance.
2. Print [Cradle Rev I.1](CrossWind_IPC101_Cradle_RevI1_PRINT.stl), **168 x 118 x 7 mm**. It accepts the unmodified R3 part and holds four PCB mounting nuts. Dry-fit R3 before adding hardware.
3. Print [Bezel Rev I.1](CrossWind_IPC101_Bezel_RevI1_PRINT.stl), **168 x 118 x 22.46 mm**. It provides faceplate mounting pads and four structural spacing posts. With the cradle, R3 and PCB, this establishes the provisional **16.5 mm faceplate-back to PCB-top** spacing.
4. After the stack fits, print Box Rev I.1 (retired export; recover from Git history), **174 x 131.912 x 108.384 mm**. Reuse the Rev H bracket and wiring plate.

Use the PRINT orientations with the established PETG/PETG-HF profile. Cradle prints rear-down: inspect the small nut-pocket bridges and supports below the relieved attachment lands. Bezel prints face-down with its posts upward; its corner pads start on the bed. Shell prints floor-down; inspect supports for receivers, roof and internal seats. All new parts fit the 256 mm build envelope. Mesh validation is not slicer validation. Check the actual slice before starting; keep support scars off datum faces and clear screw passages.

The shell's accepted external shape, 47-degree face, face position, and frozen Rev H receiver/rail/pin geometry are unchanged. Internal clearance and the four attachment seats changed; **use the I.1 shell with the I.1 cradle/bezel**. The I.1 shell retains the front-opening correction. No new bracket or faceplate is required.

## How it fastens together

The cradle is a separate frame around and behind R3. R3's posts, 3.4 mm through-holes, rails and cross-ribs are taken directly from the supplied STL. Four screws pass through the PCB, R3 and cradle to ordinary hex nuts captured at the cradle rear. The bezel is removable so it does not block those screws.

Four long screws outside the PCB outline pass through the bezel posts and cradle mounting slots into the shell's insert seats. Tightening these clamps plastic structure to plastic structure; the PCB carries no enclosure or faceplate mounting loads. The faceplate attaches independently to four insert pockets on the bezel. The bezel's rear posts contact the cradle at 46.688 mm2 per post in the ideal model.

The cradle's inward-open U-slots are intentional, not broken holes. The bezel locates the long screws, and R3 locates in the cradle with nominal 0.30 mm side clearance. The slots avoid a tangent bore at the nest edge and allow the original R3 outline to remain unchanged.

## Provisional hardware for the fit build

Hardware below is modeled for clearance, not a confirmed inventory or purchasing instruction. Match actual screws and inserts before assembly; do not heat inserts into R3's through-holes.

| Connection | Quantity | Provisional hardware | Modeled fit |
|---|---:|---|---|
| PCB + R3 + cradle | 4 | M3 x 14 socket screws | 5.5 mm head diameter, 3 mm head height; no washer in stack |
| Captured PCB nuts | 4 | M3 hex nuts | 5.5 mm across flats, 2.4 mm thick; pockets 5.8 mm AF x 2.6 mm deep |
| Bezel + cradle to shell | 4 | M3 x 30 socket screws | 5.5 mm head diameter, 3 mm head height; head bears at front datum |
| Shell seats | 4 | M3 heat-set inserts | 4.2 mm x 6 mm blind pilot; actual supplier fit/length must agree |
| Faceplate to bezel | 4 | M3 x 6 socket screws | Assumes 2 mm faceplate; 4 mm nominal insert engagement |
| Bezel faceplate pads | 4 | M3 heat-set inserts | 4.2 mm x 6 mm through pilot; inserts must remain flush/recessed |

A modeled PCB screw reaches face-local Z=30.5 mm and clears the shell. Cassette screws reach Z=30 mm, giving 4.54 mm nominal engagement from the shell seat at Z=25.46. A washer, thicker faceplate, different head, or different insert changes this calculation. Avoid screw bottoming and PCB bending. Check copper/component clearance around the actual board mounting holes.

## Current faceplate and caps: N1.2 / R1

Use the [N1.2/R1 print and assembly guide](../controls/buttons/R1_BUTTON_CAPS.md). Measured faceplate-back to unpressed button face is 10.77 mm (12.82 mm from front minus 2.05 mm plate); R1 stems use this measured reach with 0.20 mm provisional free play. N1 corrects M4 button placement using the physical PCB measurements, with ARM left/PULL right, and separates the tree from OUTDOORS. Historical M4 orientation/alignment claims below are superseded by the physical feedback; do not use them to flip the actual PCB. The cradle, bezel and shell geometry and hardware stack are unchanged.

## Bench assembly

1. Check the R3 print against the PCB. All four posts should meet the board without rocking or forcing holes into alignment.
2. Fit four nuts into the cradle rear pockets. Hold them in place during bench assembly; they are slip pockets, not guaranteed press fits.
3. Place R3 in the cradle, posts toward the PCB. Place the PCB on R3 with its component side toward the faceplate and ARM/PULL beneath their labeled openings (see the M.4 audit), and install the four M3 x 14 screws from the component side. Tighten only enough to seat the stack.
4. Rest the bezel posts on the cradle's four front lands. Fit the existing faceplate to the bezel. Before heat-setting anything, confirm the faceplate model/thickness and insert sizes. This bench stack can be measured before printing the shell; hold it gently together for the measurement.
5. Measure the back-of-faceplate to PCB-top gap at all four corners: target **16.5 mm**. Check OLED connector/harness routing, P504 body and six wires, ARM/PULL travel, LED reserve, and PCB underside clearance over R3 ribs. Check with the actual populated board; the reference board in CAD is bare.
6. Once these pass, install the shell inserts, place the cradle/R3/PCB in the shell, add the bezel, and insert four M3 x 30 screws through the exposed outboard holes. The modeled faceplate does not cover these heads, so faceplate and bezel may be handled as one unit. Attach/connect actual controls without pinching wires.
7. Reuse the Rev H wiring plate and bracket. Test docking, retaining-pin access and at least 70 mm upward removal travel.

## Service sequence

Disconnect power and external wiring. Remove the four outboard long screws; support the cradle while doing this because those screws also retain it. Lift the faceplate/bezel forward and unplug its harnesses. The PCB screw heads are now directly exposed. Either lift out the cradle/R3/PCB assembly or remove the PCB screws to lift the board out normal to its plane. No sideways threading behind permanent faceplate bosses is needed. Nut retention during service is manual until confirmed on the print.

## What is established and what remains

**Physical progress, 2026-09-21:** the user confirmed the cradle finished printing and reported that the dry fit looks good after the R3/cradle/bezel fit instructions. This records a successful general dry fit; individual hole, nut-pocket, measured gap, populated-board and harness checks were not separately reported. No geometry change is indicated by this feedback.

**Established in CAD:** unchanged R3 geometry; 150 x 100 x 1.56 PCB reference; four board mounting centres; provisional 16.5 spacing; pairwise part clearance; modeled PCB, cassette and faceplate screw/nut clearance; axial driver access; independent bezel/PCB/R3 removal; unchanged outer shell bounds and exact rear mount geometry; connected closed exports; front aperture free of membrane faces.

**Physical gates before calling the control box complete:**

- R3 and cradle fit, hardware dimensions/retention, actual populated-board and harness clearance, measured stack and control travel.
- The supplied M.4 source confirms 2 mm faceplate thickness and its actual rear cradle clears I.1. Verification and preview now use both supplied material STLs. PCB registration is explicitly X=150-Xpcb, Y=Ypcb, with the component side facing the faceplate; see [M.4 fit audit](../faceplate/history/REV_M4_FIT_AUDIT.md). P504/LED/cap refinements wait for the measured stack.
- Connector selection and environmental sealing. This fit assembly has unsealed bezel/shell and faceplate/bezel joints; the bezel now has a nominal 3 mm overlap beneath the faceplate edge (verified uninterrupted over 2.5 mm), but gasket section/compression and the shell-to-bezel seal are not designed. A sealing revision and leak test are required before outdoor use. The removable wiring plate avoids reprinting the shell when a connector is selected.

**Do not claim physical fit, weather resistance or load qualification from these checks.** The remaining work is measured fit and sealing closeout.

## Files and reproduction

Sources: `generate_rev_i1.py`, `verify_rev_i1.py`, `preview_rev_i1.py`. Geometry markings use `RI1 TEST`. Original R3 and Rev H artifacts remain available. Superseded Rev I exports are preserved unchanged in `archive/superseded-rev-i/`. The six new STLs have `INSTALLED` assembly coordinates and `PRINT` bed coordinates. Results are saved in [RevI1_verification.json](RevI1_verification.json); views in [RevI1_preview.png](RevI1_preview.png).

```powershell
python -B mechanical/enclosure/tooling/generate_rev_i1.py
python -B mechanical/enclosure/tooling/verify_rev_i1.py
python -B mechanical/enclosure/tooling/preview_rev_i1.py
```

Requires Python, manifold3d, numpy and trimesh. `FACEPLATE_TO_PCB_TOP` in the new generator controls R3 placement, cradle depth, bezel post length and shell seat position together. The shell's exterior depth is finite: regenerate and rerun verification after a parameter change, and revise the physical marking before a changed fit print.

The new verifier checks 71 bracket positions and 66 positions for each service motion, actual exported mesh topology and front-aperture triangles, the existing wiring plate/port, floor/rear witnesses, R3 support annuli, nut/screw/driver envelopes, stack spacing, and print bounds. Component and harness shapes are not inferred from photographs. The known unchanged Rev H bracket STL pin-tangency limitation remains documented in the main README.

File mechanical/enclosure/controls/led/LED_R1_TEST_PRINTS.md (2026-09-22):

# LED bubble R1 - fit and optical test prints

The recorded RGB LED body is approximately diameter 5.10 x 8.88 mm. N1.4 has a 5.2 mm opening, which cannot accommodate a printed shell around that LED. These new samples establish a candidate lens and panel opening before revising the full faceplate. No existing lens model was found in the repository.

[Preview](LED_R1_preview.png)

| Bubble tab number | Internal pocket diameter | Print file |
|---|---|---|
| 1 | 5.3 mm | [Bubble 1](CrossWind_IPC101_LED_R1_Bubble_1_Bore5.3_PRINT.stl) |
| 2 | 5.5 mm | [Bubble 2 - start here](CrossWind_IPC101_LED_R1_Bubble_2_Bore5.5_PRINT.stl) |
| 3 | 5.7 mm | [Bubble 3](CrossWind_IPC101_LED_R1_Bubble_3_Bore5.7_PRINT.stl) |

[Panel-hole strip](CrossWind_IPC101_LED_R1_Hole_Strip_PRINT.stl): holes 1 / 2 / 3 are 8.0 / 8.2 / 8.4 mm. Thickness 2.05 mm matches the reported faceplate measurement; footprint 72 x 25 mm.

All bubbles have a 7.8 mm outside diameter, a 10 mm rear flange and a temporary numbered handling tab. The neck spans 2.05 mm of panel above the 1 mm flange. The hemispherical dome projects 3.9 mm beyond the panel. Wall thickness varies from 1.25 to 1.05 mm with the pocket sizes. The LED pocket is open from the rear and has a domed roof. These are trial dimensions, not an established final lens specification.

Print bubble 2 first in the clear/translucent material intended for the lens, flange/tab flat on the bed and dome upward as exported. Start with 0.16 mm layers and no internal supports; inspect the domed pocket roof for sagging that could affect fit. Print the strip flat in the same material/profile used for the faceplate. White/opaque samples can test fit but will not establish the clear-material light appearance. Keep separate samples as separate slicer objects and arrange them apart.

1. Try the LED gently in bubble 2 from the rear; do not force it or push on its leads. Try bubble 1 for a closer fit or bubble 3 if tight. The actual LED flange/body shape may limit insertion and needs checking.
2. Insert the bubble from the strip's rear so the dome projects through a hole and the flange stays behind. Choose the smallest hole that seats freely without force. Do not enlarge the full faceplate yet.
3. Hold the LED in place for a light check using its existing correctly wired circuit. Compare visibility of each color from the front and side. Record any hotspots, weak brightness or excessive diffusion.
4. Report both numbers separately: bubble number and strip-hole number, plus the material used and any seating issue.

These samples have no final snap, LED retainer, wire strain relief or weather seal. Support the LED during testing. The temporary tab is for identification/handling, not the final mounting feature. Do not modify the PCB holes. Final retention and assembled clearance must be designed after testing; this coupon does not validate the complete populated-board stack.

Source: generate_led_bubble_r1.py. LED_R1_verification.json records four closed single-solid meshes and nine nominal bubble-to-panel clearance checks. Actual printed fit and optical performance are pending.

Other outstanding faceplate work: stacked upper-left Iron/Pine/Outdoors branding is a visual concept; wind-stroke redesign is pending. R1 ARM/PULL shafts were reported to preload actuators during assembly; final shortening awaits the user's trimmed measurements. Do not treat the earlier cap-clearance checks as proof of the physical actuator stack.

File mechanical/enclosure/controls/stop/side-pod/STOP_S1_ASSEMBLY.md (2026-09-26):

# STOP side pod S1 — physical fit prototype

> Historical design: superseded print exports were removed on 2026-09-26. Use `mechanical/enclosure/PRINT_THESE.md` for the current assembly; recover historical exports from Git or regenerate them.

Adds the received IDEC XA1E-BV302R to the existing I1 control panel. No reprint or drilling of the M4 faceplate, R3 carrier, I1 bezel/cradle, shell or Rev H mounting interface is required. The pod occupies the side at face-local X=-42 mm, Y=50 mm. See `STOP_S1_preview.png` for location. Overall control-box width increases by 57 mm; check space at the actual machine.

Current assembly reference: the [N1 replacement faceplate](../../../faceplate/history/REV_N1_FACEPLATE.md) has also passed S1 clearance checks. The pod/cover STLs already printing are unchanged.

## Print

**COUPON ACCEPTED, 2026-09-21:** the user subsequently confirmed that the switch works fine, attributing the initial apparent restriction to incorrect seating. The coupon-related pod print hold is lifted; no geometry change is indicated. Full pod assembly, wiring clearance and mounting stiffness still require physical checks.

1. Print `CrossWind_IPC101_STOP_Coupon_S1_PRINT.stl` first. This 40 × 40 × 2.5 mm coupon checks the keyed hole, gasket and locking ring against your actual switch. The nut must clamp the panel and the anti-rotation tab must engage without force. Check the printed hole with calipers; tune printer compensation or lightly finish it within the specified cutout tolerance if necessary.
2. Print `CrossWind_IPC101_STOP_Pod_S1_PRINT.stl`, front down as exported: 68 × 80 × 48 mm.
3. Print `CrossWind_IPC101_STOP_Cover_S1_PRINT.stl`, flat as exported: 54 × 60 × 3 mm.

PETG, 0.20 mm layers, six walls, six top/bottom layers, 40% infill are starting settings. These orientations need no supports. Keep the mounting land clean of brim/elephant foot. The cover pilot holes are provisional 2.7 mm: check/tap for M3 without splitting the bosses. Engraved STOP-S1 identifies the revision. Python `generate_stop_s1.py` is the editable source; run it to regenerate STL and verification results.

## Hardware and assembly

- Two M3 × 35 socket-head screws replace the two M3 × 30 cassette screws on the pod side. Reuse the existing shell inserts. Do not add washers under these two heads: the 5 mm pod flange and extra 5 mm screw length preserve the original engagement and screw-tip position.
- Four M3 × 10 screws retain the 3 mm rear cover, with 7 mm engagement in the pod's blind pilot holes. Start gently; do not overtighten printed threads.
- Use the switch's original gasket, locking ring and complete contact block. No receiver socket is needed.
- Provide insulated wire, terminal insulation and a small cable tie for the two strain-relief holes. Cable entry protection at the existing bottom wiring plate must match the cable/grommet actually used.

With the control box unpowered, remove the pod-side cassette screws, seat the pod's flat mounting flange against the front of the bezel, and install the M3 × 35 screws. Both attachment points must be tight with the flange fully seated. The mounting load goes through the cassette attachment points into the shell, not through the PCB.

Unlock the switch operator before separating its contact block. Follow IDEC's bayonet-ring instructions. Insert the operator from the pod front, with its anti-rotation tab toward the key notch. The circular rear recess leaves a 2.5 mm panel land. Refit the original locking ring, then align and fully latch the contact block. IDEC specifies 0.88 N·m maximum for its locking ring; this is not a validated tightening torque for this printed mount. Check for cracking, panel distortion and looseness.

Leave slack behind the contacts. Route the insulated cable through the 7 × 6 mm split exit at the pod's lower rear edge and secure it using the adjacent tie holes. Route externally to the existing bottom wiring plate; remove/drill that replaceable plate for your selected protected cable entry. Do not pass a bare cable across a sharp drilled edge or into the bracket rails. This version does not supply a selected cable gland, weather seal or pre-sized wiring-plate hole. Fit the rear cover without pinching the cable.

For front service, remove the pod's two attachment screws and support it alongside the enclosure with cable slack before removing the cassette. Do not hang it from its solder joints. The cover can be removed independently for contact-block access.

## Drawing basis and verification limits

Manufacturer-authored [IDEC XA catalog, printed pages 326–329](https://spectechind.com/Documents/idecxacatalog.pdf), checked 2026-09-21: exact solder-terminal 2NC model; nominal Ø16 family; Ø29 operator; cutout Ø16.2–16.4 mm, key width 1.7–1.9 mm, keyed overall height 17.9–18.1 mm; allowed panel thickness 0.5–3.7 mm; nominal rear depth 27.9 mm. S1 uses the tolerance midpoints (16.3, 1.8, 18.0 mm). These are CAD dimensions, not a guarantee of FDM output size. Do not substitute the unibody switch drawing.

Clearance modeling deliberately reserves a Ø32 mm locking-ring envelope followed by a 32 × 32 mm body envelope reaching 33 mm behind the mounting land, plus 12.5 mm space to the rear cover. It represents installation clearance, not exact switch geometry. The model includes a simplified red front operator only for preview.

`STOP_S1_verification.json`: six watertight, consistently wound, single-component exports; no solid overlap with I1 shell, bezel, cradle, R3 or actual M4 plate/PCB; replacement fastener clearance; full contact-block rotational envelope; 71 bracket slide positions; 66 forward pod-removal positions; 41 rear-cover withdrawal positions. Check actual cable routing and tool access physically. CAD checks do not establish impact strength, fatigue, environmental sealing, emergency-stop system compliance or the complete assembled fit. Before use, verify the mount does not flex/rotate/loosen during push and reset, the contact block is fully locked, and the STOP circuit works in the assembled machine.

The existing isolated NC STOP interface remains unchanged. Confirm terminals and continuity before wiring; this mechanical accessory does not assign the second NC contact.

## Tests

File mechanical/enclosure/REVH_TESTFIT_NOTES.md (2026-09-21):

# IPC-101 Enclosure Rev H — Test-Fit Notes

Status: **TEST-FIT / NOT FABRICATION-FROZEN**  
Date: 2026-09-20

Rev H begins the enclosure redesign after the physical IPC-101 mock-up showed that the Rev G upper wall angle / face-boss arrangement conflicts with the PCB and control-panel stack.

## Preserved from Rev G

The rear wood mounting interface remains the datum for Rev H:

- body width: 156 mm
- wood mount X: 16 and 140 mm
- wood mount Z: 28 and 70 mm
- wood screw clearance: 4.5 mm
- head recess: 9.5 mm
- straight driver access: 11 mm
- mounting pads: 24 x 20 x 4 mm
- nominal wall: 3 mm
- 47 degree operator viewing angle retained for this test revision

## Rev H control stack

Current physical mock-up target:

- faceplate back surface to IPC-101 PCB top: **~16.5 mm**
- IPC-101 PCB thickness: **1.56 mm**
- four confirmed IPC-101 corner holes: (5,5), (145,5), (5,95), (145,95)

Rev H experiments with a common corner stack so the faceplate/PCB relationship is controlled mechanically. This is intentionally a test architecture and may change after the first fit check.

The 16.5 mm spacing is provisional. It was chosen to allow OLED wiring/harness connector clearance and must be physically verified before freezing button-cap height or production enclosure dimensions.

## Rear Alpha connector

Rev H reserves a **34 x 26 mm generic connector-cassette bay** on the rear. This is not the final connector cutout.

The intent is to use a removable connector-specific insert so the enclosure does not need to be reprinted if the IPC-101-to-Alpha connector family changes during Alpha development.

Connector family, pin count, keying, sealing and final insert dimensions remain TBD pending electrical interface confirmation.

## Physical marking

Rev H carries the hidden mark:

`IPC101-ENC-RH TEST`

This follows `mechanical/REVISION_MARKING_STANDARD.md`.

## Test objectives

Before Rev H can advance:

1. Verify preserved rear mounting interface still fits the CrossWind Alpha mounting location.
2. Verify PCB/faceplate stack can physically occupy the redesigned upper volume.
3. Verify ~16.5 mm faceplate-to-PCB-top spacing clears the OLED harness/connectors.
4. Check P504 pedestal/retainer clearance.
5. Check ARM/PULL actuator relationship; this measurement will drive final button-cap stems.
6. Verify all four corner fasteners can be installed/removed without PCB/component interference.
7. Verify rear connector bay is accessible and leaves adequate cable bend/service space.
8. Identify any unnecessary enclosure volume before the next revision.

Do not treat Rev H as production geometry. It is deliberately generous so interference can be found before the enclosure is tightened around the assembly.

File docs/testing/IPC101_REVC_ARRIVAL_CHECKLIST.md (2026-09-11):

# IPC-101 Rev C arrival and first-power checklist

Prepared 2026-09-11. This is a working acceptance record, not evidence of a passed
test. Mark each item PASS / FAIL / PENDING with measurements and notes.

## Identify the delivered build

- [ ] Record order number, board quantity, delivery date, board ID/serial and photos of both faces.
- [ ] Compare the actual order confirmation/approved assembly list with the local package. The saved recommendation is two top-side assembled prototypes; actual vendor approval and substitutions have not been checked here.
- [ ] Confirm PCB Rev C, 150 x 100 mm, nominal 1.6 mm FR-4, two layers.
- [ ] Confirm the vendor accepted `IPC101_RevC_MaskFix_Gerbers.zip`. The earlier Gerber ZIP is obsolete. Inspect exposed through-hole solder pads on BOTH faces; mask covering those pads is a discrepancy to resolve before soldering.
- [ ] Use the existing Rev C assembly reference, BOM and CPL; the mask correction did not change copper, drills or placement.

Reference set: [order notes](../../hardware/fabrication/IPC101_RevC/ORDER_NOTES.md),
[assembly drawing](../../hardware/fabrication/IPC101_RevC/IPC101_RevC_assembly_reference.pdf),
[assembly BOM](../../hardware/fabrication/IPC101_RevC/IPC101_RevC_JLCPCB_BOM.csv),
[hand-install list](../../hardware/fabrication/IPC101_RevC/IPC101_RevC_HAND_INSTALL.csv).
Paths in this paragraph are relative to this checklist's directory.

## Prepare before delivery

- [ ] Gather multimeter, magnification, fine soldering tools, flux, solder wick, ESD-safe work surface and a current-limited 3.3 V bench supply.
- [ ] Prepare keyed breakout leads so first power does not require loose probes on adjacent connector pins.
- [ ] Have a 3.3 V-compatible I2C host/fixture available. Confirm its pull-ups and voltage before connecting it. A USB connection or I/O line must not back-power the board.
- [ ] Verify availability of IPC-100 J10 power/firmware support or a standalone scanner test fixture. Existing Crosswind direct-GPIO firmware is not proof of a working TCA8418 integration.
- [ ] Inventory the following items; quantities are PER BOARD. Count spares separately.

| Ref / item | Qty | Expected part or action | On hand / missing |
| --- | ---: | --- | --- |
| SW1, SW2 | 2 | B3F-4055 tactile switches; dry-fit cap reach before soldering | |
| SW3 | 1 | Adafruit 504; verify actual six-pin orientation and fit | |
| D1 | 1 | 5 mm COMMON-ANODE RGB LED; verify R-A-G-B order against board | |
| J2 | 1 | JST B5B-XH-A five-pin vertical through-hole header | |
| J3 | 1 | Two-pin 3.81 mm STOP header and matching plug; final part/mate must match IPC-100 J8A | |
| J4 | 1 | JST SM05B-GHS-TB five-pin horizontal SMT header; hand installation | |
| TP1-TP4 | 4 optional | 1 mm through-hole test loops | |
| OLED | 1 | Hosyond 2.42-inch SSD1309, B0G2RFLG1L; inspect actual header and RESET | |
| J1 harness | 1 | GH four-pin mate GHR-04V-S, correct contacts; 26-28 AWG per interface | |
| J4 input harness | 1 | GH five-pin mate GHR-05V-S and correct contacts | |
| J2 output harness | 1 | Matching five-pin XH housing/contacts to actual OLED header | |
| STOP operator/harness | 1 | Actual NC contact assembly, isolated pair; verify received part and connector compatibility | |
| PCB/panel hardware | set | M3 screws/standoffs/inserts; lengths selected from actual stack | |
| TPU fixture hardware | set | Four M3 bolts, washers and nuts per coupon; M3 x 12 mm is a starting candidate | |

The records disagree on STOP operator branding (BOM specifies Omron; TPU notes
mention IDEC). Identify the actual received operator/contact block; do not order
an assumed replacement from that wording. START in the logical matrix and ARM
on the faceplate/BOM also need explicit firmware-semantic reconciliation.

### Rigid prints and TPU preparation

- [ ] Dry-fit the Rev H enclosure, detachable bracket, retaining pin and wiring plate.
- [ ] Use the Rev D faceplate for the next trial: its OLED is shifted 8 mm right. PCB fabrication remains Rev C. Do not force the display onto the PCB's old OLED mounting pattern.
- [ ] Check actual PCB, display, connectors and standoffs together; envelope checks alone did not verify the complete stack.
- [x] Rigid TPU clamp frames printed previously (user confirmed 2026-09-11). Check that each coupon fixture has two matching frames when assembling; quantity and fit have not been independently verified.
- [ ] When TPU arrives, start with `ARM_PULL_TPU_WEB_0.6mm.stl`, flat as exported. Follow the actual filament profile/drying guidance; ordinary TPU uses the A1 external spool, not AMS Lite.
- [ ] Compare 0.4/0.6/0.8 mm webs and navigation coupons for return, force, defects and permanent deformation. Record material, settings and cycle count.
- [ ] Do not drill the faceplate to the coupon's 44 x 38 mm fixture pattern. These are standalone experiments, not drop-in boots or qualified waterproof seals. Keep STOP uncovered.
- [ ] Select the actual enclosure cable-entry connector/gland before modifying the blank Rev H wiring plate; its current model has no wire passage.

See [panel revisions](../../mechanical/panel/README.md),
[TPU procedure](../../mechanical/panel/tpu-prototypes/README.md), and
[Rev H enclosure](../../mechanical/enclosure/README.md).

## Incoming assembly inspection — no power

- [ ] Expected factory population: U1 TCA8418RTWR (one), R1 10 kOhm (one), R2-R4 1 kOhm (three), C1 100 nF (one), C2 4.7 uF (one), J1 GH four-pin (one). Compare with vendor-approved substitutions, not just the older general BOM.
- [ ] Inspect U1 orientation/pin 1 and visible perimeter joints, bridges, shifted parts, damaged tracks and loose debris. Visual inspection cannot establish hidden exposed-pad wetting.
- [ ] Inspect all J1 pins and anchors. Verify connector pin numbering from the PCB/netlist and housing, not an assumed wire-side view.
- [ ] Confirm hand-install omissions match the list above; J4 is intentionally NOT factory populated in the saved assembly package.
- [ ] Dry-fit SW1/SW2/SW3, caps, LED and the faceplate before committing solder height. No switch should be held pressed by the assembled panel.
- [ ] Hand-solder missing parts with power disconnected; inspect J4's fine-pitch joints and anchors especially carefully.
- [ ] Confirm the common-anode LED and its actual lead order; do not substitute the common-cathode module used in the existing Alpha wiring.
- [ ] Clean only with methods compatible with the switches; do not wash unsealed switches by default.

## Harness and unpowered electrical checks

All pin numbers below are BOARD connector numbers. Verify the mating housing's
numbering/orientation before crimping. Disconnect host, supply and USB power.

| Connector | Pins in order | Source / destination |
| --- | --- | --- |
| J1 | 1: 3.3 V, 2: GND, 3: SDA, 4: SCL | IPC-100 J10; max 0.30 m harness |
| J4 | 1: OLED_VCC, 2: OLED_GND, 3: SDA, 4: SCL, 5: active-low RESET | IPC-100 J6 input |
| J2 | Same five positions as J4 | Output to actual display header; adapt its pin order as marked |
| J3 | 1: STOP_IN_RAW, 2: STOP_RETURN | Separate NC STOP circuit to IPC-100 J8A; neither is logic ground |

- [ ] Measure J1 power-to-ground resistance; record initial and settled values. Investigate a persistent near-short; capacitor charging is not itself a short. No arbitrary resistance threshold is established here.
- [ ] Verify J4-to-J2 continuity 1-to-1 through all five positions, no adjacent shorts, and isolation from J1 nets.
- [ ] Verify J3's two nets are isolated from logic supply/ground and other circuitry. Check the NC switch separately: released = closed, operated = open.
- [ ] Verify every harness end-to-end and inspect crimp retention. Label J1 controls, J4 OLED input, J2 OLED output and SAFETY STOP/J8A distinctly.
- [ ] Inspect the OLED's actual header labels and RESET population. Resolve any unsoldered RES connection before connecting it; do not assume the five module pins match J2 physically.

## First power — keypad board only

Motor and thrower/actuator power remain disconnected. Leave OLED and IPC-100
disconnected for standalone supply testing; never parallel the bench supply
with the IPC-100 output. Do not power J3.

- [ ] Set supply to 3.3 V and 20 mA current limit; output OFF while connecting J1 pin 1 positive and pin 2 return.
- [ ] Turn on; record voltage and idle current. Existing bench target is below 5 mA with status LED channels off. If the supply current-limits, voltage collapses or a component heats, switch off and inspect before increasing the limit.
- [ ] Verify U1 VCC and RESET high using the schematic to identify pads; avoid bridging fine-pitch pins with probes.
- [ ] Check power-off discharge and absence of unintended power from attached instruments/host.

## Keypad and indicator checks

- [ ] With a correctly powered 3.3 V host and appropriate bus pull-ups, detect U1 at 7-bit address 0x34, 100 kHz. IPC-101 does not add J1 I2C pull-ups; IPC-100 owns them in the final system.
- [ ] Confirm the host configures R0-R6/C0, debounce and FIFO, and polls at 10-20 ms. Address detection alone does not prove button operation.
- [ ] Check these seven functions individually, then adjacent simultaneous presses:

| Matrix | Expected raw function | Press/release result |
| --- | --- | --- |
| R0/C0 | LEFT | |
| R1/C0 | RIGHT | |
| R2/C0 | UP | |
| R3/C0 | DOWN | |
| R4/C0 | SELECT | |
| R5/C0 | START (faceplate ARM; verify intended host action) | |
| R6/C0 | PULL | |

- [ ] Repeat each key 100 times per existing bench plan: one event per transition, no cross-action, ghosting, stuck events or FIFO overflow.
- [ ] Exercise D1 colors with the intended driver configuration; record channel identity and current separately from the LED-off idle test.
- [ ] Confirm disconnect/reset of the panel leaves ordinary commands inactive. Defer invasive trace-opening and fault injection to the controlled bench plan; do not cut the new board as an arrival test.

## OLED branch — separate power test

- [ ] Use the separate J4/J2 branch, not J1 power or its 20 mA keypad-only limit.
- [ ] Use current-limited 3.3 V, selected for the verified module. Record startup and steady current; interface limits are 100 mA continuous and 150 mA for at most 20 ms. Those limits are acceptance criteria, not proof that this sample meets them.
- [ ] Verify 0x3C or 0x3D, functional RESET, cold startup, all-pixel pattern, orientation, contrast and no unintended backfeed when unpowered.
- [ ] Check final branch length/capacitance (0.20 m / 50 pF), pull-ups and rise time against the interface. Fixed OLED pull-ups below 47 kOhm are an unresolved compatibility issue to assess, not something to ignore because the display lights.

## Integrated dry run and release record

- [ ] With actuators disconnected, verify the actual STOP path removes hardware permit within IPC-100's released timing; record the applicable requirement and measurement. Verify a stuck I2C bus cannot delay STOP.
- [ ] Verify ordinary key mapping, ARM/START meaning, PULL interlocks and power-cycle defaults with the actual host firmware; record firmware hash and fixture/IPC-100 revision.
- [ ] Reassemble with selected TPU/rigid actuators and repeat key-return/preload checks before committing sealing or adhesives.
- [ ] Record remaining fit, firmware, OLED, STOP and weather-sealing issues. Electrical bench acceptance is not weather or motion-system release.

| Record | Value |
| --- | --- |
| Board ID / order / PCB revision | |
| MaskFix order confirmation | |
| Actual assembly substitutions | |
| Host hardware / firmware hash | |
| Supply voltage / current limit / LED-off idle current | |
| U1 VCC / RESET / I2C result | |
| OLED startup / steady current / reset result | |
| STOP requirement / measured response | |
| Faceplate / enclosure / TPU configuration | |
| Failed checks / next action | |
| Tested by / date / acceptance scope | |

Authority: [interface](../interface/IPC100_IPC101_INTERFACE.md),
[architecture](../architecture/IPC101_ARCHITECTURE.md), and
[full bench plan](IPC101_BENCH_TEST_PLAN.md). The older P0 static-validation record
predates the Rev C release and contains superseded board dimensions and release
status; use the Rev C fabrication package for incoming-board identity.

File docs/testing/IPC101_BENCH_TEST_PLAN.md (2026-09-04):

# IPC-101 P0 Bench Test Plan

Do not connect motors or actuator power during stages 1–5. Record board serial, CAD revision, IPC-100 firmware hash, instruments, and results.

1. **Incoming inspection:** compare SW3 pins and U1 land pattern to received parts; inspect pin 1, shorts, solder, mounting clearance, labels, and OLED hole spacing.
2. **Unpowered continuity:** verify no 3V3/GND short; J3 pins are isolated from GND, 3V3, and board copper; NC STOP gives continuity only when released.
3. **Current-limited power:** apply 3.3 V at J1 with 20 mA limit. Confirm <5 mA idle target, U1 VCC, RESET high, and no heating.
4. **I2C:** at 100 kHz detect only U1 at 0x34 on J10. Confirm no clock stretching and acceptable rise time with final harness.
5. **Key matrix:** press/release every control 100 times; verify exactly one mapped event per transition, no ghost key, FIFO overflow, stuck event, or cross-action. Test simultaneous adjacent keys.
6. **Fault injection:** unplug J1, open matrix traces where practical, short each row/column through 1 kOhm, reset, and cycle power. Ordinary commands must default inactive.
7. **STOP:** with actuators disconnected, verify opening J3/pressing STOP removes hardware permit within IPC-100 released timing and reports STOP/fault. A wedged I2C bus must not delay it.
8. **OLED:** inspect the Hosyond B0G2RFLG1L module's printed pin order and RESET population before making the J6-to-J4 and J2-to-module harnesses. Continuity-check J4 pin 1 through J2 pin 1, through all five positions, with no cross-connections or connection to J1. With current-limited 3.3 V power, confirm address 0x3C or 0x3D, reset control, startup, all-pixel pattern, orientation, contrast, current (listing claims 52 mA maximum), pull-up/rise-time compatibility, and unpowered I/O backfeed behavior.
9. **System dry run:** simulated loads only; exercise every mapped action and confirm STOP dominates every state.
10. **Mechanical/environmental prototype:** glove trial, 500 cycles, harness tug, vibration, condensation inspection in intended enclosure, and -10 to +50 C screening unless superseded.

Release requires signed results, native ERC/DRC reports, reviewed Gerbers/drills, and closure of SW3/U1 footprint holds.

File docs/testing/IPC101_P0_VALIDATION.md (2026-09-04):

# IPC-101 P0 Static Validation Record

Date: 2026-09-01. Environment: Windows workspace; KiCad 10 CLI located at `D:\KiCad\bin\kicad-cli.exe` (not on PATH).

| Check | Result | Evidence / limitation |
|---|---|---|
| Required repository files | PASS | All requested paths present |
| S-expression parenthesis balance | PASS | Schematic and PCB counts equal after correction |
| Duplicate PCB reference names | PASS | U1, SW1–3, J1/J3, C1/C2, R1, TP1–4, DS1, H1–4 unique |
| Unassigned footprint review | PASS for PCB study | Every PCB reference has explicit pads; panel SSTOP is intentionally off-board |
| Connector pinout review | PASS static | J1 matches IPC-100 J10; J4/J2 pass through IPC-100 J6 in identical order; J3 matches J8A pair |
| STOP isolation review | PASS static | STOP nets occur only at J3 pads; no zone/net connection |
| Logic-voltage review | PASS static | U1 is 1.65–3.6 V; J10 is protected 3.3 V |
| Current budget | PASS analysis | <5 mA target versus 100 mA J10 limit; OLED separately powered |
| OLED orientation/interface | BLOCKED | Hosyond 2.42-inch SSD1309 B0G2RFLG1L selected for prototype; received-sample pinout, mounting, 3.3 V behavior, address, pull-ups, current, reset population, and backfeed still require qualification |
| SW3 orientation/footprint | BLOCKED | Supplier gives similar-part datasheet; received sample needed |
| U1 land/stencil review | BLOCKED | Peer review/1:1 plot and assembly capability needed |
| Board/mount clearance | PASS static / PROVISIONAL | 100 x 140 mm outline and coordinates coherent; enclosure unmeasured |
| ERC | PASS WITH WARNINGS | KiCad 10 native ERC: 0 errors, 52 warnings; warnings are embedded-library registration, off-grid endpoints, intentional isolated STOP labels, and reviewable pin-type warnings |
| DRC | PASS WITH WARNINGS | KiCad 10 native DRC generated 2026-09-03: 0 electrical/routing errors and 0 unconnected pads; 60 non-electrical warnings remain for silkscreen placement, local footprint-library registration/matching, and isolated copper-fill fragments |
| Gerber/drill generation | WITHHELD | Depends on ERC/DRC and footprint closure |

This record does not authorize fabrication.

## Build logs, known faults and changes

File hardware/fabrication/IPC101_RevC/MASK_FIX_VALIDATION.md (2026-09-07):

# IPC101 Rev C solder-mask replacement verification

Date: 2026-09-07. Tools: KiCad 10.0.5 CLI and bundled pcbnew Python.

- Source: 29 PTH pads have F.Mask and B.Mask; 48 SMD pads have assembly-side mask.
- Final ZIP: 77 top and 29 bottom mask flashes; every solderable pad centre found.
- ZIP CRC and exact equality with the exported fabrication files: pass.
- Native full DRC with existing project rules: 0 violations, 0 unconnected pads, 0 footprint errors. Existing ignored checks remain listed in `../../kicad/IPC101_DRC.rpt`.
- Copper, paste, outline, and drill geometry compared with the superseded ZIP: unchanged (generation timestamps ignored).
- D1 reference moved from F.Silkscreen to F.Fab to eliminate its overlap with the newly opened LED pads. Its position and copper remain unchanged.
- Three regression tests: pass (missing source mask rejected, generator restores mask, empty bottom Gerber rejected, corrected exports accepted).
- Bottom-side KiCad render visually inspected: plated component pads exposed; surrounding board masked. See `IPC101_RevC_MaskFix_bottom.png`.
- Existing BOM and CPL retained. No component, wiring, or placement changes.

Replacement file: `IPC101_RevC_MaskFix_Gerbers.zip`

SHA-256: `b067c8119ed9dd976859ae5bafc6f1a0de8f3087623b31338226f0208bbb1501`

Superseded ZIP SHA-256: `eb56a3955d9e1595866eb4c8b064eb22091e3c1dcf8799918ab6c56337e5c303`

Run `generate_package.ps1` to export with DRC and source/Gerber/archive mask checks. Run `D:/KiCad/bin/python.exe hardware/fabrication/IPC101_RevC/test_solder_mask.py` from the project root for regression checks.

This resolves the demonstrated mask omission. Manufacturer layer recognition and assembly orientation must still be checked in the replacement-file viewer before production approval. No upload or production approval was performed in this task.

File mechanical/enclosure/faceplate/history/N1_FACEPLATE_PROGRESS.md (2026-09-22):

# N1 faceplate correction in progress

Historical measurement/strip notes. The user subsequently confirmed ARM left/PULL right; the [current N1 replacement files](REV_N1_FACEPLATE.md) are now generated and CAD verified. M4 is superseded for reprinting.

## Physical button measurements, 2026-09-21

User measured the PCB upright, component/buttons facing the operator:

| Position | Measurement | Center from operator's left edge |
|---|---|---|
| Left button | 46.88 mm from left edge | 46.88 mm |
| Right button | 34.33 mm from right edge | 115.67 mm, assuming 150 mm PCB width |

These differ from M4's operator-view openings at 33.5 and 103.5 mm. Required measured shifts are +13.38 and +12.17 mm, respectively. Do not mirror the entire faceplate to fix this: that would also move the display, navigation mount and artwork.

The measured spacing is 68.79 mm; the PCB file's nominal button spacing is 70 mm. Preserve the reported measurements as measurements, not as a claim that the PCB design changed. Check the strip physically before adopting them in a finished faceplate. The user confirmed left=ARM and right=PULL. No labels are assigned by the strip; the finished N1 plate includes them.

## Optional quick alignment print

`CrossWind_IPC101_Button_Check_N1_PRINT.stl`: 150 x 35 x 2 mm strip, with the original two lower mounting holes and original 16 x 10.8 mm rounded button openings. Vertical button coordinate remains 20.75 mm from the bottom; the user has not remeasured it. Recessed N1 TEST is on the rear face.

Print flat as exported. Fit the strip at the bottom of the bezel using its two lower mounting holes, rear marking toward the PCB. Check both real buttons without forcing the strip or preloading the controls. No need to interrupt the STOP pod/cover prints for this check.

The strip's exported X coordinates are 103.12 and 34.33 mm. This is the existing face-down manufacturing convention, which reverses X relative to the operator view; it does not undo the measured correction. Generator: `python -B mechanical/enclosure/tooling/generate_n1_button_check.py`. Watertight export and bezel/cradle/bare-PCB clearance results are in `N1_button_check.json`.

## Tree correction

Inspection of M4 shows that the tree base extends into the OUTDOORS lettering: its connected black mesh includes part of that lettering. N1 implements a distinct flat-bottomed trunk separated from the text. White recesses and black inlay have been generated and verified together. The corrected full N1 faceplate STLs are now issued; see the current guide above.

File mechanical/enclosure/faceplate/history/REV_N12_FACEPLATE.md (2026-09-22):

# N1.2 faceplate — tree from the actual Iron Pine wordmark

Current reprint revision for use with the R1 labeled ARM/PULL caps. Replaces N1.1's generic pine with a trace of the supplied transparent wordmark. The outline includes the swept branches, open center and separate center triangle, at the original aspect ratio. See [trace provenance](../../branding/README.md).

## Print these together

- [N1.2 white faceplate](CrossWind_IPC101_Faceplate_RevN12_WHITE_PETGHF.stl)
- [N1.2 black inlay](CrossWind_IPC101_Faceplate_RevN12_BLACK_AMS.stl)
- [Actual faceplate and tree close-up](N12_faceplate_preview.png)
- [Panel with R1 caps](../../controls/buttons/R1_button_caps_preview.png)

Import the white/black pair as parts of **one object** with their shared coordinates. Do not mirror or independently center them. Front/graphics print at Z=0. Use the same two-color faceplate settings as N1.1 and inspect the tree's center channels and narrow tapered ends in the slicer's first layers. Artwork depth remains 0.55 mm. Do not mix material files from different revisions.

## Preserved fit

ARM remains left at 46.88 mm and PULL right at 115.67 mm from the operator-facing left edge, both 20.75 mm above the bottom. All aperture dimensions, OLED/D-pad locations, rear P504 cradle, faceplate thickness, mounting holes and R1 cap fit are unchanged. Labels remain on the caps, without duplicate panel ARM/PULL text. No existing cap, cradle, bezel, shell or STOP pod requires reprinting for this artwork change.

The hidden rear mark is `IPC101-FP-N1.2`. IRON/PINE/OUTDOORS lettering and the CrossWind graphics remain the existing faceplate artwork; only the tree is traced from the supplied logo.

## Verification and reproduction

`N12_faceplate_verification.json` checks the exported tree against the traced polygons, the two original tree components, white/black mesh validity, tree-to-OUTDOORS clearance, preserved surrounding artwork and combined mechanical geometry against N1.1 outside the rear revision mark. `R1_button_caps_verification.json` checks the caps against N1.2. These are CAD checks; the physical reprint and first-layer details remain to be checked.

```powershell
python -B mechanical/enclosure/branding/trace_tree.py
python -B mechanical/enclosure/tooling/render_faceplate_n1.py --revision N12 --openscad "C:\path\to\openscad.com"
python -B mechanical/enclosure/tooling/verify_faceplate_n12.py
python -B mechanical/enclosure/tooling/verify_button_caps_r1.py
python -B mechanical/enclosure/tooling/preview_faceplate_n12.py
python -B mechanical/enclosure/tooling/preview_button_caps_r1.py
```

The SCAD and the `branding/` trace dependencies must stay together. Earlier N1/N1.1 exports remain identifiable historical alternatives; use the N1.2 pair for the requested logo correction.

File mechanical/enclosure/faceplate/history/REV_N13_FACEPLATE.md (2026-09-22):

# N1.3 — compact tree and IPO option

**Superseded for reprinting by [N1.4](../REV_N14_FACEPLATE.md): same artwork, enlarged 8 mm P504 aperture. N1.3 retains the restrictive 6.2 mm opening.**

This option replaces the full IRON PINE / OUTDOORS group with the actual traced tree and bold **IPO** below it. CrossWind keeps its existing size and graphics, making the product name more prominent. N1.2 remains available with the full wordmark.

- [Side-by-side and badge close-up](N13_faceplate_preview.png)
- [N1.3 white faceplate](CrossWind_IPC101_Faceplate_RevN13_WHITE_PETGHF.stl)
- [N1.3 black inlay](CrossWind_IPC101_Faceplate_RevN13_BLACK_AMS.stl)

Import the white/black pair together as parts of one object. Preserve their common coordinates; do not mirror or combine revisions. Use the existing face-down PETG/two-material profile and inspect the first layers for legible IPO lettering and the tree's center channels.

The tree is 12.5 mm tall at its original aspect ratio, approximately 13.51 mm wide. IPO uses 3.2 mm bold font sizing, the same sizing used for the R1 cap labels; actual glyph bounds and spacing are recorded in `N13_faceplate_verification.json`. The combined badge is approximately 17 mm tall. It replaces the small OUTDOORS lettering rather than shrinking it further. This is a CAD-verified print option; physical lettering quality remains to be checked.

All button centers, apertures, mounting holes, panel thickness, rear P504 cradle and R1 cap geometry remain unchanged. The hidden revision mark is `IPC101-FP-N1.3`. The verifier checks that combined mechanical geometry outside that mark matches N1.2, CrossWind artwork is unchanged, the tree matches its source mesh, IPO has three separate glyphs with clear space below the tree, and both caps clear the plate through 21 inward positions each.

```powershell
python -B mechanical/enclosure/tooling/render_faceplate_n1.py --revision N13 --openscad "C:\path\to\openscad.com"
python -B mechanical/enclosure/tooling/verify_faceplate_n13.py
python -B mechanical/enclosure/tooling/preview_faceplate_n13.py
```

Keep the `branding/iron_pine_tree_unit.stl` dependency with the faceplate SCAD source. No previously printed mechanical part needs changing for this badge option.

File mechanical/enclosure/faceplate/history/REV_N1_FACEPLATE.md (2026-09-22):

# N1 faceplate — current reprint files

Status: **CAD VERIFIED; PHYSICAL REPRINT FIT PENDING**. Replaces M4 for the next faceplate print. R3, I1 bezel/cradle/shell and the S1 STOP pod/cover geometry are unchanged.

The subsequent [N1.1 faceplate and R1 labeled caps](../../controls/buttons/R1_BUTTON_CAPS.md) are the current choice when using labels on the cap faces. N1 remains compatible and retains duplicate panel labels.

## Corrected layout

Viewed from the operator/front, upright:

| Feature | X from left edge | Y from bottom | Basis |
|---|---:|---:|---|
| ARM, left | 46.88 | 20.75 | User's measured X and confirmed function; existing Y |
| PULL, right | 115.67 | 20.75 | 150 minus user's 34.33 mm right-edge measurement; existing Y |
| D-pad/P504 | 45 | 63.5 | Existing wired faceplate position |
| OLED | 103.5 | 63.5 | Existing wired faceplate position |
| LED | 68.5 | 31 | Existing wired faceplate position |

The user confirmed ARM left/PULL right and reported the OLED/D-pad positions were swapped on the PCB. The replacement follows the physical button measurements; it does not infer function labels by flipping the PCB file. Wired OLED and navigation locations on the faceplate remain as M4. Labels now follow their corrected button openings.

M4's operator-view button centers were 33.5 and 103.5 mm. N1 moves them right by 13.38 and 12.17 mm respectively. The measured 68.79 mm spacing differs from the PCB file's 70 mm nominal spacing; retain that distinction and verify the physical fit. The optional N1 button-check strip uses the same measured locations. Vertical positions and aperture sizes were not changed or remeasured.

The tree now has stepped branches and a flat-bottomed trunk. The former pointed base joined the OUTDOORS lettering; N1 leaves a verified approximately 1.03 mm gap. White recesses and black artwork are regenerated together. A hidden rear `IPC101-FP-N1` mark identifies the new print.

## Print together as one two-material object

- [White PETG-HF body](CrossWind_IPC101_Faceplate_RevN1_WHITE_PETGHF.stl)
- [Black AMS inlay](CrossWind_IPC101_Faceplate_RevN1_BLACK_AMS.stl)
- [Actual export preview, including logo close-up](N1_faceplate_preview.png)

Select both STLs together and import as parts of **one object**, preserving their original common coordinates. Assign white and black materials. Do not independently center/arrange them, and do not mirror either file. Front surface is at Z=0, on the print bed. Match the successful M4 material/profile; use 0.20 mm or finer layers and check the first-layer inlays in the slicer. The artwork is 0.55 mm deep. Outline is 150 x 100 mm, panel thickness 2 mm, total height 4.8 mm including the rear navigation cradle.

Export X is 150 minus operator X because these files are oriented front-down. ARM therefore appears at exported X=103.12 and PULL at X=34.33. The [preview](N1_faceplate_preview.png) shows the readable operator view. That manufacturing conversion is intentional and already applied; do not add another mirror operation.

After printing, fit the faceplate to the existing bezel and confirm both buttons move freely without preload before tightening. Check the actual populated board, harness and P504 motion. The optional alignment strip remains available if another quick position check is preferred first.

## Checks and reproduction

`N1_faceplate_verification.json` records closed/wound meshes (one white body, 37 separate black inlay bodies), matching material recesses, complete button openings at the corrected locations, separated tree/lettering and unchanged combined body geometry outside the button/revision-mark regions. The rear P504 cradle is unchanged. Tiny overlap residuals below 0.001 mm3 reflect exported mesh precision.

`verify_rev_i1.py` passes with the N1 faceplate: shell, cradle, bezel, hardware and driver clearance; front service paths; exact Rev H mounting interface; original six I1 print exports. `generate_stop_s1.py` passes all 280 S1 checks against the N1 assembly. These checks do not establish physical button travel, populated-board clearance, structural qualification or weather sealing.

SCAD source: `CrossWind_IPC101_Faceplate_RevN1.scad`. Render both materials with OpenSCAD, tested with 2021.01 and installed Liberation Sans fonts:

```powershell
python -B mechanical/enclosure/tooling/render_faceplate_n1.py --openscad "C:\path\to\openscad.com"
python -B mechanical/enclosure/tooling/verify_faceplate_n1.py
python -B mechanical/enclosure/tooling/verify_rev_i1.py
python -B mechanical/enclosure/tooling/preview_faceplate_n1.py
```

M4 files remain identifiable as historical references; do not select them for this reprint.

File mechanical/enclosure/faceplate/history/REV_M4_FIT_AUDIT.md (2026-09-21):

# Rev M.4 faceplate / Rev I.1 fit audit

Status: **PHYSICAL BUTTON ALIGNMENT FAILURE REPORTED - DO NOT REPRINT M4**.

2026-09-21: the user reports that the last faceplate's button openings appear mirrored and do not align with the asymmetric button positions. This physical feedback supersedes the alignment conclusion below. The historical CAD comparison assumed a flipped PCB registration; it did not establish the actual assembled orientation. Confirm button centers from the operator-facing left/bottom edges before issuing corrected white and black exports. The tree artwork also remains uncorrected in M4. The subsequent [N1 replacement](REV_N1_FACEPLATE.md) uses physical button measurements and user-confirmed ARM-left/PULL-right labels, with corrected tree artwork. This M4 audit is historical.

The supplied SCAD and both material STLs are retained unchanged. I.1 verification and preview now use the actual M.4 geometry rather than the plain faceplate envelope. No shell, cradle, bezel, R3 or faceplate print geometry changed in this integration.

## Source geometry

- Faceplate: 150 x 100 x 2 mm, four 3.2 mm mounting holes at (5,5), (145,5), (5,95), (145,95).
- White export bounds: (0,0,0)..(150,100,4.8). It is one watertight connected mesh.
- Black export: 36 watertight disconnected inlay bodies, intentionally separate lettering/graphics; Z=0..0.55. Load white and black in their shared coordinates, not as independently arranged objects.
- P504 rear cradle: 10.70 mm pocket, nominal 14.70 mm outside width, 2.80 mm projection behind the plate. Its slots and corner walls are included in the collision model.
- P504 aperture remains 6.2 mm, LED aperture 5.2 mm, and OLED window 57 x 28 mm. No N.1 aperture, artwork or cap changes were made.

## Assembly coordinate registration

The SCAD already applies `whole_mirror()` about X=75 to both exports. Do not mirror those STLs again. Their operator face is at raw Z=0 and back surface at raw Z=2. The assembly reference keeps exported X/Y and subtracts 2 mm from Z; consequently the back surface is at assembly Z=0 and the P504 cradle projects inward to Z=2.8.

The PCB component side must face the faceplate. Register the repository PCB coordinates as:

```
Xassembly = 150 - Xpcb
Yassembly = Ypcb
Zassembly = PCB_BACK - Zpcb
```

For a board whose bottom is Zpcb=0 and top is Zpcb=1.56, this is a physical 180-degree rotation about Y followed by translation. It puts the board top at Z=16.5 and bottom at Z=18.06. It is not a mirrored fabricated PCB. The rectangular board outline and symmetric four-hole pattern are unchanged, so the current R3/cradle print needs no modification.

The initial direct-XY comparison was inappropriate for this component-side-out orientation and produced a false ARM/PULL discrepancy. The corrected comparison reads placements from the actual repository `hardware/kicad/IPC101.kicad_pcb` and checks these against the supplied SCAD/export apertures:

| Control | Repository PCB X,Y | Installed PCB X,Y | M.4 aperture X,Y | Result |
|---|---|---|---|---|
| ARM / SW1 | 33.5,20.75 | 116.5,20.75 | 116.5,20.75 | Aligned |
| PULL / SW2 | 103.5,20.75 | 46.5,20.75 | 46.5,20.75 | Aligned |
| LED / D1 | 68.5,31 | 81.5,31 | 81.5,31 | Aligned reference; LED remains separately supported/wired |
| Navigation / SW3 | 105,63.5 | 45,63.5 | 105,63.5 | Faceplate-mounted P504 uses six flexible leads |
| OLED / DS1 | 46.5,63.5 | 103.5,63.5 | 46.5,63.5 | Faceplate-mounted display uses a harness |

OLED and P504 do not sit on their PCB footprint coordinates in this assembly. This follows the wired, faceplate-supported architecture; do not install them as rigid structural connections between PCB and faceplate. Physical wire lengths, connector orientation and strain relief remain to be checked.

## Checks passed

- Both actual faceplate materials, including the rear cradle, clear I.1 shell, bezel, cradle, R3 and bare-board reference.
- Four faceplate holes and control apertures agree with the registration above; board-mounted ARM/PULL positions align with their openings.
- Faceplate and cassette screw envelopes and driver access pass with the actual faceplate in place. PCB screw access passes with the faceplate/bezel removed.
- All previous I.1 checks still pass: six closed connected exports, exact Rev H interface, rail/pin clearance, front aperture, service motions, rear/floor/port integrity, R3 support, 16.5 mm spacing and print bounds.
- Updated `RevI1_preview.png` was visually inspected with actual white panel and black inlays.

These checks do not model the mounted display, harness connectors, P504 pedestal/cap travel, final button caps, LED holder or every populated PCB component. They therefore establish shell/faceplate compatibility and coordinate alignment, not complete populated-assembly validation.

## Next physical check

Finish the cradle print. Check that R3 seats without force and the four holes/nut pockets fit. Print the I.1 bezel next. Place the actual PCB with its component side facing the faceplate and check ARM beneath ARM and PULL beneath PULL before tightening. Measure the 16.5 mm gap at all four corners and exercise both controls without preload. Check the OLED harness and P504 leads while lifting the bezel off for service. Keep final cap stems, pedestal/aperture refinement and gasket compression adjustable until these measurements are recorded.

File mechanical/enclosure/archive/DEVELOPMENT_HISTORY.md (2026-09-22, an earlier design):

> ARCHIVED DEVELOPMENT RECORD. Printing directions below describe earlier revisions. Use [PRINT THESE](../PRINT_THESE.md) for the current assembly. Historical filenames are relative to their original enclosure folder; see [archive index](README.md) for relocated artifacts.

> M.4 faceplate files are now present: [actual-faceplate fit audit](../faceplate/history/REV_M4_FIT_AUDIT.md). Enclosure clearance passes; ARM/PULL align with the component-side-out PCB orientation. Physical fit is pending.

> **Current R3-compatible fit build: Rev I.1.** See [print order, hardware and assembly guide](../structure/REV_I1_ASSEMBLY.md) and [preview](../structure/RevI1_preview.png). Reuses the original R3 print. Earlier revisions below are historical; physical validation is pending.

# Crosswind IPC-101 enclosure Rev H ? fit prototype

Rev H keeps the existing Rev C 150 x 100 mm faceplate and 47-degree angle, raises its lower edge from 7.5 to 32 mm, and separates the Crosswind mounting bracket from the enclosure. Rev G files remain for comparison; use the Rev H files below for the next fit evaluation.

## Files

- `CrossWind_IPC101_Box_RevH_PRINT.stl`: enclosure, floor on the print bed.
- `CrossWind_IPC101_Bracket_RevH_PRINT.stl`: Crosswind bracket, flat back on the bed.
- `CrossWind_IPC101_Wiring_Plate_RevH_PRINT.stl`: blank underside wiring plate.
- Corresponding `INSTALLED` files share one assembly coordinate system.
- `RevH_preview.png`: front without faceplate, rear with bracket, and side with faceplate. Blue is enclosure, gold bracket, green wiring plate.

## Faceplate and sealing geometry

All four mounting seats are defined at the same exact face-local Z=0 plane, using the Rev C hole centres (5,5), (145,5), (5,95), and (145,95) mm. The previous hull approximation and -1.2 mm seat offset are not used. The seating plane is also the rear face of the installed faceplate. Inserts load from the front into 4.2 mm diameter, 6 mm deep pockets. Confirm the actual insert specification and keep inserts flush or slightly below the seat.

A continuous 2 mm wide, 0.8 mm deep rectangular gasket groove runs inside the mounting screws (outer bounds X=8..142, Y=8..92 in panel coordinates). A nominal 1 mm thick gasket would compress to 0.8 mm when the plate reaches its hard seats; actual material/compression must be qualified. Use a continuous cut gasket, not four loose strips. The service opening is 128 x 78 mm. Its 5 mm deep rim may require OLED spacers: the existing 73 mm module extends to X=10 mm, slightly over the X=11 mm opening edge. Verify the complete PCB/display/control stack before printing a final assembly.

The rear is closed with no wood screw penetrations. The floor has a 44 x 18 mm wiring opening and a 66 x 36 x 3 mm removable blank plate. Four M3 screws at installed X=50/106, Y=9/33 attach to blind insert pockets. Its gasket groove is 2 mm wide by 0.8 mm deep, outside the opening and inside the screws. Select the connector from actual conductor count, cable diameter, electrical requirements, and mating access; add its manufacturer cutout to this plate. The blank seals the opening but cannot pass wires yet. No connector has been selected or electrical interface changed.

These are sealing provisions, not a demonstrated waterproof assembly. The existing display, navigation, LED, and button openings still need seals, and the printed shell and gasket compression require physical leak testing. Rain versus hose exposure remains unspecified.

## Detachable Crosswind bracket

The bracket is 140 x 92 mm with four 4.5 mm wood-screw clearance holes on 128 x 75 mm centres. Screw heads are exposed with the box removed; use heads no larger than 9.5 mm diameter and 3 mm projection. Confirm wood screw length for the actual Crosswind mounting surface.

Two external T rails slide into receivers on the closed enclosure back. Nominal side clearance is 0.4 mm and head-depth clearance is 0.35 mm per side. Lower the box onto the bracket, align the transverse 3.4 mm hole, and install a removable 3 mm retaining pin with positive clip retention through the left receiver and rail (approximately 20 mm grip; measure the printed part). The pin retains the box vertically; magnets are not required. Allow at least 65 mm of upward travel and access to the pin for removal. Manually unplug wiring before removal. Rail load capacity and pin accessibility require a mounted fit trial; this is not a qualified structural mount.

The assembled body is about 156 mm wide, 104.2 mm high, and 122.3 mm deep from the wood plane to the frontmost shell edge, excluding the faceplate and controls. The extra depth comes from moving the top of the inclined face outward to 32 mm to provide usable internal clearance. Check this projection on Crosswind before accepting the revision.

## Future transparent cover

Keep the top and sides available for a separate cover hinge/latch design. No hinge, magnet pocket, or cover is committed in this revision. During the Crosswind fit trial reserve a provisional 15 mm beyond the top and sides and 15 mm outward from the faceplate, then measure actual cap heights and opening sweep. The cover must not obstruct the bracket removal path. Transparent filament appearance and cover fit can be evaluated after enclosure fit is accepted.

## Print and fit sequence

1. Slice the three PRINT files. The box stands on its floor; use localized supports beneath the rear receiver bottoms and inspect the upper internal roof in the slicer. The bracket prints back-down. Check rail-slot bridging before committing to the print. Mesh verification does not establish support-free printability.
2. Before heat-setting inserts, check that the bare Rev C faceplate rests on all four seats without rocking and that screws align. Check display/PCB rear clearance and button travel with the actual parts.
3. Install inserts and gaskets; tighten evenly and check perimeter contact. Four screws and the existing 2 mm plate may not provide uniform gasket pressure without further reinforcement.
4. Mount the bracket, fit the rails and retaining pin, and confirm connector/hand clearance on Crosswind. Select the connector and cut only the removable wiring plate.
5. Fit seals to the remaining front openings and perform an unpowered leak test before claiming weather resistance.

Regenerate and verify with Python plus `manifold3d` and `numpy`:

```powershell
python mechanical/enclosure/tooling/generate_rev_h.py
python mechanical/enclosure/tooling/verify_rev_h.py
```

Verification checks connected closed meshes, zero box/bracket and box/port-plate interference, the actual Rev C faceplate against the enclosure, all four coplanar seating annuli, and bracket withdrawal at 71 positions. It also regenerates the preview. Physical print tolerances, component stack, mounting loads, and waterproofing remain unverified.

---

# Crosswind IPC-101 control box Rev G

This enclosure replaces the provisional blue Crosswind control pod shown in the September 4 fit-test photos. It retains the comfortable 47-degree face angle while removing the features that made the first pod difficult to mount.

For historical Rev G only, use `CrossWind_IPC101_Control_Box_RevG_PRINT.stl` for slicing. The installed-orientation STL is supplied for assembly checks and CAD visualization. Rev G keeps the unobstructed service opening and extends all four faceplate bosses 1.2 mm outward so their screw-hole faces are coplanar with the faceplate seating datum. Earlier enclosure STLs are obsolete.

## Mounting improvements

- 156 mm enclosure width with 3 mm registration margins around the 150 mm faceplate
- Four internal rear mounting pads with 4.5 mm wood-screw clearance holes, 9.5 mm recessed-head pockets, and 11 mm straight driver-access tunnels
- Mounting screws are installed from inside while the faceplate is removed
- Flat rear datum at the wooden mounting surface; no projecting tabs behind the wood plane
- Four 11 mm face bosses with front-loaded 4.2 x 6.0 mm M3 heat-set-insert pockets and 3.2 mm screw relief
- 1.2 mm lateral faceplate registration rails
- 42 x 20 mm bottom cable exit for the keypad, OLED, and STOP harness groups
- One unobstructed 136 x 86 mm front service opening inside the perimeter rim
- 3 mm nominal walls and the retained 47-degree viewing angle

The current model assumes the same 101.6 mm (4 inch) wooden vertical mounting surface shown in the photos. Use pan-head or washer-head wood screws no larger than 9.5 mm at the head. Install and heat-test four M3 inserts from the face side before installing the IPC-101 PCB/faceplate stack; adjust the 4.2 mm pilot in the generator if the selected insert supplier specifies another hole size.

Print the `PRINT` file with its flat wooden-mounting plane on the build plate. The rear pads and shell edges provide bed contact while the 47-degree face remains self-supporting. PETG or ASA is preferred for the outdoor prototype. Use at least four perimeters and 25 percent infill. Confirm screw length, cable bend clearance, faceplate seating, and access to all four wood screws on a fit print before outdoor service.

## Current redesign direction â€” updated 2026-09-21

The existing physical CrossWind mount uses **channels that the enclosure fits/slides into**. This slide-channel engagement is now a **required preserved interface**.

Rev H/H1/H2 incorrectly treated the Rev G screw-hole pattern and gross rear dimensions as the complete mounting interface. That was insufficient. Rev H2 is rejected and must not be used as the mounting baseline.

Current working requirements:

- Preserve the proven enclosure-to-mount **channel engagement geometry exactly** in the next revision.
- Preserve the docking/channel region as a fixed datum; redesign the enclosure body only forward of that retained interface.
- Preserve the established IPC-101 faceplate footprint and control layout.
- Design the PCB carrier/chassis and enclosure as a matched assembly rather than forcing IPC-101 into the Rev G upper geometry.
- Current nominal spacing from the **back surface of the faceplate to the top surface of IPC-101 is approximately 16.5 mm**. This is a prototype design target, not yet a fabrication-frozen dimension; it was selected to provide clearance for the OLED wiring/harness connectors.
- The carrier/chassis should establish the PCB-to-faceplate relationship and carry the PCB mechanically. The enclosure should primarily provide structure, mounting and environmental protection.
- Provide a rear/upper-rear flush panel connector for the IPC-101-to-CrossWind-Alpha harness after the actual connector is selected. Connector family, cutout and pin count remain **TBD**.
- Avoid internal screw bosses or wall slopes that intrude into the IPC-101/control-component envelope.
- Maintain service access so the control-panel/PCB assembly can be removed without disturbing the CrossWind mounting interface.

Do not use the approximately 16.5 mm spacing as a final drilling/fabrication dimension until the carrier fit test verifies OLED, P504, ARM/PULL switch and harness clearances.

## Development record

As mechanical work progresses, record useful confirmed dimensions, physical fit-test results, superseded assumptions and revision decisions in the repository rather than relying only on conversation history. CAD/STL revisions should be accompanied by source files and a short status note identifying whether they are conceptual, test-fit, physically validated or frozen.

Regenerate Rev G with:

```powershell
python .\generate_crosswind_control_box.py
```

Requires `manifold3d`.

---

## Rev I enclosure and carrier — TEST-FIT / PHYSICAL VALIDATION PENDING

This section supersedes the earlier "current redesign direction" where H-like names are ambiguous. The authoritative `generate_rev_h.py`, `CrossWind_IPC101_Box_RevH_*`, `Bracket_RevH_*`, and `Wiring_Plate_RevH_*` define the actual mounting baseline. The exploratory `Control_Box_RevH_TESTFIT.scad`, `RevH1_TESTFIT.scad`, and `RevH2_TESTFIT.scad` are **SUPERSEDED** and were not used for Rev I mounting geometry.

### Preserved interface and new artifacts

**FROZEN / PRESERVED:** unchanged Rev H bracket; the exact two external receiver solids extracted from the authoritative box at Y=-10..0; original rail/slot clearances, stops, transverse pin bore, installed coordinates and detachable slide concept. No Rev I bracket exists. Reuse the Rev H wiring plate too: its 44 x 18 mm port, four fastener positions and blank connector area remain. No connector family or cutout has been selected.

New sources: `generate_rev_i.py`, `verify_rev_i.py`, `preview_rev_i.py`. New printable artifacts: `CrossWind_IPC101_Box_RevI_{INSTALLED,PRINT}.stl` and `CrossWind_IPC101_Carrier_RevI_{INSTALLED,PRINT}.stl`. `RevI_preview.png` shows open shell, rear with bracket, installed side, carrier/PCB, exploded stack and center cutaway. Colors: grey shell/bracket, tan carrier, green PCB, ivory faceplate envelope. Reference PCB and faceplate are verification geometry, not new production designs.

### Datums, dimensions and load path

Units are mm. Face-local +Z points inward; Z=0 is the back of the faceplate. Angle remains 47 degrees. Face origin is the Rev H origin shifted 8 mm outward along installed Y; this is a deliberate prototype clearance allowance, not a change to docking coordinates. Faceplate footprint and four mounting centres remain 150 x 100 and (5,5), (145,5), (5,95), (145,95).

- Shell installed bounds: X=-9..165, Y=-10..121.912, Z=0..108.384; overall **174 x 131.912 x 108.384 mm**. Including the existing bracket and wiring plate: **174 x 136.912 x 111.384 mm**, excluding controls.
- Carrier PRINT bounds: **168 x 118 x 25.06 mm**. Installed bounds: X=-6..162, Y=16.327..119.718, Z=7.534..106.338.
- `FACEPLATE_TO_PCB_TOP = 16.5` is **PROVISIONAL**. Board rear seating plane is 18.06; carrier rear datum is 25.06. Changing the named spacing parameter moves the rear seats/frame and shell attachment seats together. Re-run all checks after any change; the shell depth is finite.
- Board thickness uses the user's confirmed **1.56** measurement. KiCad's nominal setup is **1.60**. Board outline and mounting centres agree with repository geometry. Hole reference diameter is 3.2; verify the fabricated holes before hardware assembly.
- Front shell aperture is 170 x 120, surrounding a 168 x 118 removable carrier bezel. Nominal opening-edge shell wall is 2 mm; rear and floor retain at least the tested 2.5 mm witness thickness outside intentional pockets/port. Carrier front/rear rails are 3 mm thick and 8 mm wide.

The PCB rests on four rear corner pads, with independent front-accessible mounting screws. Separate front corner pads support the faceplate; outboard posts and rails carry loads to four shell seats at face-local (-5,20), (-5,80), (155,20), (155,80). No switch, display, wire or solder joint supports the assembly. The component area between corner mounting lands is open. The outboard rails make the visible bezel larger than the original faceplate; this is an intentional fit-validation allowance.

Attachment hardware is a **prototype assumption**: M3 inserts in 4.2 mm diameter x 6 mm blind pockets; carrier attachment bores 3.4 mm with 6.5 mm head/driver clearance. Confirm actual insert OD/length, head diameter, screw engagement and driver reach before heating inserts. Faceplate pockets pass through the 6 mm front pads; PCB-seat pockets retain about 1 mm backing. Do not allow insert or screw protrusion into the PCB stack. Select screw lengths from the measured stack and chosen insert, not a generic length. Four carrier screws bear on the rear rail at the bottom of the driver recess.

### Assembly, printing and measurements

Print **the carrier first**, rear frame on the bed as supplied in PRINT orientation. Use PETG/PETG-HF with a 0.4 mm nozzle and inspect the slicer: the upper perimeter rail and corner pads require localized supports. Keep support scars off seating faces and clean the bores without enlarging them arbitrarily. Shell PRINT stands on its closed floor; inspect supports under receiver bottoms, internal roof and attachment seats. Both parts fit within a 256 mm build envelope. This verifies size, not printer calibration or support-free manufacture. Start with four perimeters; qualify actual walls, insert retention and rail strength on the first print.

With the carrier outside the shell, slide the bare PCB in through the open end between its front and rear frames; the verifier checks this board-only path. Fasten the PCB to the rear seats from the front, install the carrier in the shell, then attach the existing faceplate to its independent front seats. For service remove faceplate, unplug harnesses, remove four outboard carrier screws, and lift the cassette normal to the face. Board removal from the cassette reverses the end-insertion path. Populated-board and attached-harness service paths still require physical testing.

Measure/check on the carrier print:

1. All four PCB holes and faceplate holes, flat seating, board edge clearance and insert retention; do not bow the PCB by tightening.
2. Actual faceplate-back to PCB-top distance at all four corners, nominal 16.5. Record printed board thickness and any seat/support cleanup.
3. OLED connector and harness bend clearance, P504 cradle/pedestal and six-lead routing, ARM/PULL motion and wiring, LED holder reserve and access to all screw heads. No final cap-stem lengths follow from this CAD alone.
4. Side insertion/removal of the populated PCB and front cassette removal with the actual wiring disconnected.

Then print the shell and reuse the Rev H bracket/wiring plate. Check full rail engagement, pin access and positive retention, at least 70 mm available upward withdrawal travel, CrossWind projection, cassette fit, shell seat contact, and blank plate removal. Measure connector/cable/hand envelope before selecting a flush connector. Hidden recessed marks read `IPC101-ENC-RI TEST` and `IPC101-CARRIER-RI TEST`.

At initial Rev I generation, no R3 carrier or N/M.4 faceplate source was found. R3 was subsequently supplied and inspected; see the comparison below. N/M.4 remains unavailable. Existing Rev C/D faceplate generators and coordinate files were inspected but their obsolete control layout is not claimed as N/M.4. The preview uses only a 150 x 100 x 2 faceplate envelope with four mounting holes. Actual N/M.4 back features, assembled OLED/header dimensions, harness bend radii, P504 swept movement, populated PCB underside heights and final hardware remain **PHYSICAL VALIDATION PENDING**. Known P504 body/cradle, actuator and LED dimensions supplied for this task are context, not sufficient coordinates for a complete component collision model. Central control space is unobstructed; component-level clearance is not certified. N.1 artwork/aperture/caps/LED refinements remain deferred.

Environmental shell only: rear/floor are closed except the intentional removable bottom service port. Carrier-to-shell clearance is an unsealed prototype joint, and faceplate sealing has not been engineered/qualified for this larger cassette. Keep the prototype dry; gasket lands/compression and leak testing are required before outdoor deployment. No waterproof claim is made.

### Reproduction and verification

```powershell
python mechanical/enclosure/tooling/generate_rev_i.py
python mechanical/enclosure/tooling/verify_rev_i.py
python mechanical/enclosure/tooling/preview_rev_i.py
python mechanical/enclosure/tooling/verify_rev_h.py
```

Dependencies: Python, manifold3d, numpy, trimesh. Verification checks generated and exported Rev I closed, consistently wound, connected meshes, bounds and print-bed placement; exact Boolean equality of the entire preserved rear interface; zero installed and 71-position (0..70 mm) bracket interference; pin passage; carrier/PCB/faceplate clearance; 66 front cassette withdrawal positions; bare-board end insertion; four PCB seat annuli and bores; parameterized spacing; rear/floor witness solids and unobstructed service port. Export checks compare bounds and volumes to their source solids. Preview inspection supplements these checks; neither proves physical fit or loading.

**Inherited Rev H export limitation:** the frozen bracket's pin bore is exactly tangent to its stem face at installed Y=-5.3, Z=40, across X=27..33. Both existing bracket STLs have one welded edge with four incident triangles, so trimesh does not classify them as watertight. The authoritative manifold model passes the original indexed-edge verification. This is explicitly reported by the Rev I audit, not silently repaired or called a new Rev I failure. Existing bracket files remain unchanged; inspect the known working bracket's slicer behavior. All newly generated Rev I exports must pass strict welded-mesh checks without exceptions.

### Recovered R3 carrier - inspected 2026-09-21

The user subsequently supplied `IPC101_RevA_RearCarrier_R3.scad` and `.stl`. Both were inspected without modification. They are the recovered reference for the previously tested rear carrier; this inspection establishes no additional physical validation.

R3 has bounds (-3,-3,0)..(153,103,7.4): 156 x 106 x 7.4 mm. The source defines a 2.4 mm base, 6 mm perimeter rails, 5 mm cross-ribs, and four 8 mm diameter posts rising 5 mm above the base. Their 3.4 mm through-holes are at (5,5), (145,5), (5,95), (145,95). The STL is watertight and one connected component; its bounds agree with the source and volume is approximately 12,503.585 mm3.

Hole centres agree exactly with Rev I, but fastening geometry differs: initial Rev I uses 9 mm rear pads and 4.2 mm insert pockets. Initial Rev I therefore does not inherit the full R3 board attachment geometry and must not be represented as R3-derived.

For comparison at the provisional 16.5 mm faceplate-to-PCB-top spacing, reflect R3 in Z and translate by 25.46 mm in face-local Z. Post tops meet the PCB rear at 18.06 mm; the base occupies Z=23.06..25.46. Applying the existing Rev I face transform gives zero PCB-reference intersection (numerical residual below 1e-4 mm3), but 58.426 mm3 shell intersection at the carrier seats. The existing Rev I attachment datum is 25.06 mm, 0.40 mm forward of the R3 base rear. R3 is not a drop-in replacement and lacks the Rev I faceplate/support attachment structure.

The next geometry integration should preserve R3 board centres, 8 mm posts and 3.4 mm through-holes, provide an explicit removable fastener arrangement, and reconcile rear frame/seat depth. Its cross-ribs require populated-PCB underside and harness clearance checks. Initial Rev I generator/STLs remain unchanged by this comparison. Do not print the current Rev I carrier expecting R3 hardware compatibility; settle this integration before another carrier fit print.

Input SHA-256:

- SCAD: `A941E9DEE239ED2F806CC3225EB164D02C7B2587D38E852663961E12626AAF39`
- STL: `3D8C7A564F197CA7FEAC8A0377CF2ECFAA3A88A208E170DEBEB5657B0888346F`

### Rev I front-opening export correction - 2026-09-21

The initial Rev I shell exports contained four large coincident, opposite-facing triangles across the nominal front aperture. These zero-volume sheets made the shell appear closed despite passing the previous volume-intersection and welded-edge checks. The cavity cutter now extends 1 mm outside the face datum rather than ending coplanar with it. This removes the spurious faces without changing the intended shell volume, carrier seats, dimensions or frozen Rev H mounting interface. Regenerated Rev I shell STLs supersede the initial defective exports; the originals remain in Git history. The verifier now checks actual exported triangles at the front aperture in both orientations.

Intended attachment sequence for the initial Rev I cassette: insert the PCB into the separate carrier and fasten it to its four rear pads; insert the carrier through the open shell front and secure it to the four recessed outboard shell seats; attach the faceplate to the four front corner pads on the carrier. Faceplate screws do not attach directly to the shell. The separate carrier is required for this arrangement. Actual fastener/driver access and the recovered R3 integration remain pending; this correction alone does not make R3 compatible. Do not print the initial cassette pending that integration.

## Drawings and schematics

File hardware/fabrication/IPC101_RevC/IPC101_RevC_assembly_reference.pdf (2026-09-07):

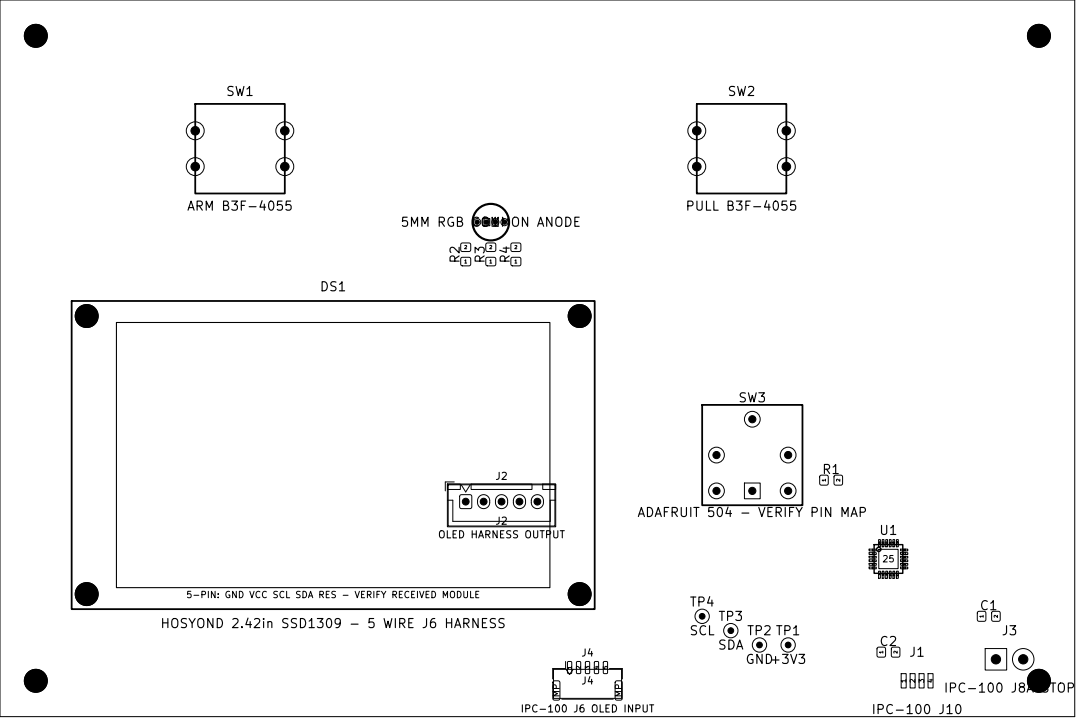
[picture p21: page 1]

ADAFRUIT 504 - VERIFY PIN MAP

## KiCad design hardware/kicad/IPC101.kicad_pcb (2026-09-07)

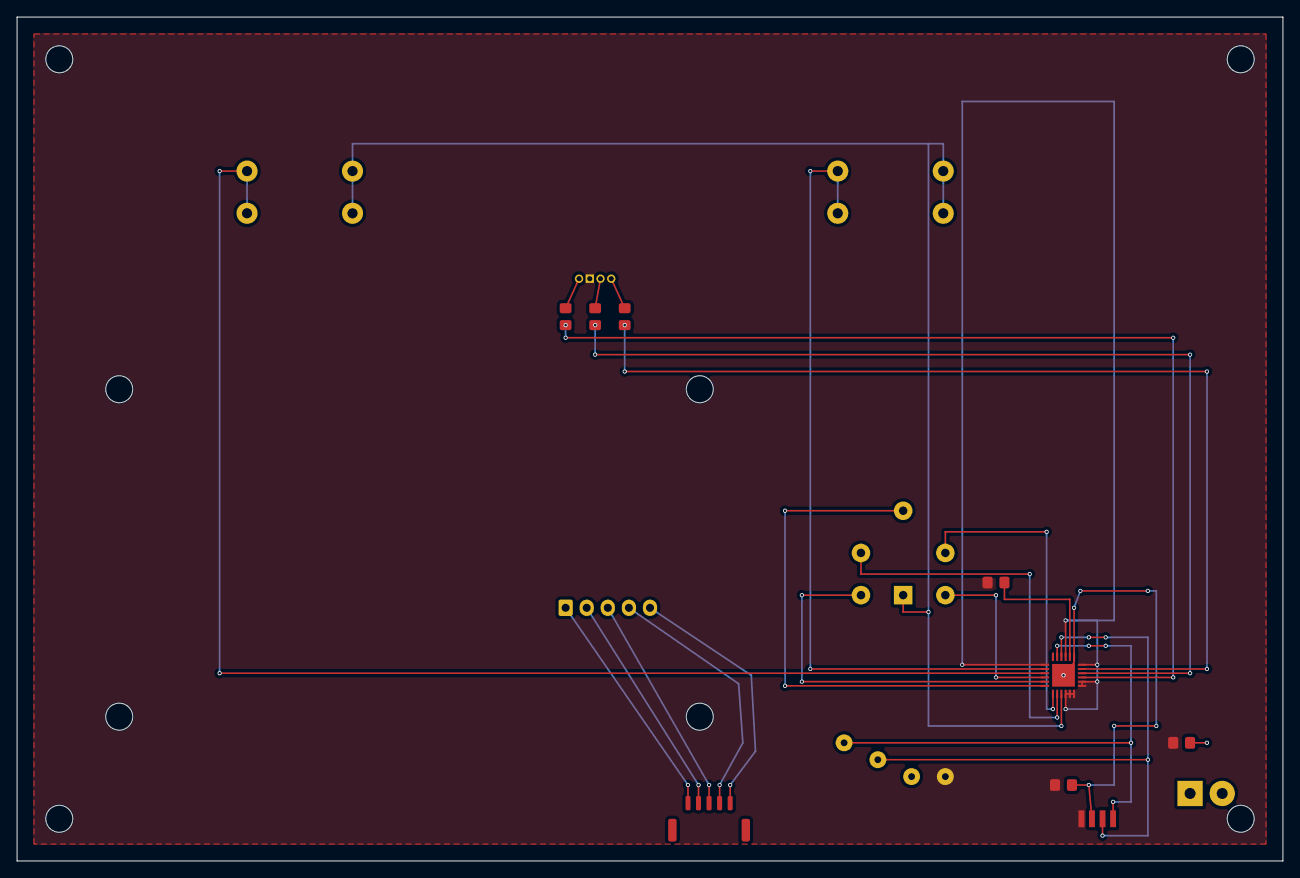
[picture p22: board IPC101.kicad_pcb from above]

Board: 2 copper layers, 150.0 x 100.0 mm, 24 parts (0 on the bottom side), 24 nets.

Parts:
C1: 100nF
C2: 4.7uF
D1: 5MM RGB COMMON ANODE
DS1: HOSYOND 2.42in SSD1309 - 5 WIRE J6 HARNESS
H1, H2, H3, H4: (no value)
J1: IPC-100 J10
J2: OLED HARNESS OUTPUT
J3: IPC-100 J8A STOP
J4: IPC-100 J6 OLED INPUT
R1: 10k RESET
R2: 1k RED
R3: 1k GREEN
R4: 1k BLUE
SW1: ARM B3F-4055
SW2: PULL B3F-4055
SW3: ADAFRUIT 504 - VERIFY PIN MAP
TP1: +3V3
TP2: GND
TP3: SDA
TP4: SCL
U1: TCA8418RTWR

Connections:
/+3V3: C1.1, C2.1, D1.2, J1.1, R1.1, TP1.1 (1_1), U1.1 (ROW7), U1.10 (COL1), U1.11 (COL2), U1.12 (COL3), U1.13 (COL4), U1.14 (COL5), U1.18 (COL9), U1.21 (VCC)
/C0: SW1.2, SW2.2, SW3.1 (COMMON), U1.9 (COL0)
/GND: C1.2, C2.2, J1.2, TP2.1 (1_1), U1.19 (GND), U1.25 (EP)
/OLED_GND: J2.2, J4.2
/OLED_RESET: J2.5, J4.5
/OLED_SCL: J2.4, J4.4
/OLED_SDA: J2.3, J4.3
/OLED_VCC: J2.1, J4.1
/R0_LEFT: SW3.2 (LEFT), U1.8 (ROW0)
/R1_RIGHT: SW3.3 (RIGHT), U1.7 (ROW1)
/R2_UP: SW3.4 (UP), U1.6 (ROW2)
/R3_DOWN: SW3.5 (DOWN), U1.5 (ROW3)
/R4_SELECT: SW3.6 (SELECT), U1.4 (ROW4)
/R5_ARM: SW1.1, U1.3 (ROW5)
/R6_PULL: SW2.1, U1.2 (ROW6)
/RESET: R1.2, U1.20 (~RESET)
/RGB_B_GPIO: R4.1, U1.17 (COL8)
/RGB_B_K: D1.4, R4.2
/RGB_G_GPIO: R3.1, U1.16 (COL7)
/RGB_G_K: D1.3, R3.2
/RGB_R_GPIO: R2.1, U1.15 (COL6)
/RGB_R_K: D1.1, R2.2
/SCL: J1.4, TP4.1 (1_1), U1.23 (SCL)
/SDA: J1.3, TP3.1 (1_1), U1.22 (SDA)

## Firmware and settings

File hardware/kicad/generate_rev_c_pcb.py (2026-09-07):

#!/usr/bin/env python3
"""Rebuild IPC-101 as the 150 x 100 mm Rev C Crosswind panel PCB."""

from __future__ import annotations

from pathlib import Path
from collections import defaultdict
from heapq import heappop, heappush
import math

import pcbnew

HERE = Path(__file__).resolve().parent
BOARD_PATH = HERE / "IPC101.kicad_pcb"
KICAD_FOOTPRINTS = Path(r"D:\KiCad\share\kicad\footprints")
MM = pcbnew.FromMM


def point(x: float, y: float) -> pcbnew.VECTOR2I:
    return pcbnew.VECTOR2I(MM(x), MM(y))


def set_position(board: pcbnew.BOARD, reference: str, x: float, y: float, angle: float = 0) -> None:
    footprint = board.FindFootprintByReference(reference)
    if footprint is None:
        raise KeyError(reference)
    footprint.SetPosition(point(x, y))
    footprint.SetOrientationDegrees(angle)


def net(board: pcbnew.BOARD, name: str) -> pcbnew.NETINFO_ITEM:
    item = board.FindNet(name)
    if item is None:
        item = pcbnew.NETINFO_ITEM(board, name)
        board.Add(item)
    return item


def pad(footprint: pcbnew.FOOTPRINT, number: str) -> pcbnew.PAD:
    candidates = [item for item in footprint.Pads() if item.GetNumber() == number]
    if not candidates:
        raise KeyError(f"{footprint.GetReference()} pad {number}")
    return candidates[0]


def clone_resistor(board: pcbnew.BOARD, source: pcbnew.FOOTPRINT, reference: str,
                   value: str, x: float, y: float, first_net: str, second_net: str) -> pcbnew.FOOTPRINT:
    footprint = pcbnew.FOOTPRINT(source)
    footprint.SetReference(reference)
    footprint.SetValue(value)
    footprint.SetPosition(point(x, y))
    footprint.SetOrientationDegrees(90)
    pad(footprint, "1").SetNet(net(board, first_net))
    pad(footprint, "2").SetNet(net(board, second_net))
    board.Add(footprint)
    return footprint


def add_rgb_led(board: pcbnew.BOARD) -> pcbnew.FOOTPRINT:
    footprint = pcbnew.FOOTPRINT(board)
    footprint.SetReference("D1")
    footprint.Reference().SetLayer(pcbnew.F_Fab)
    footprint.SetValue("5MM RGB COMMON ANODE")
    footprint.SetPosition(point(68.5, 31.0))
    footprint.SetFPID(pcbnew.LIB_ID())
    for diameter, layer in ((5.0, pcbnew.F_Fab), (5.2, pcbnew.F_Fab)):
        circle = pcbnew.PCB_SHAPE(footprint)
        circle.SetShape(pcbnew.SHAPE_T_CIRCLE)
        circle.SetCenter(point(68.5, 31.0))
        circle.SetEnd(point(68.5 + diameter / 2, 31.0))
        circle.SetLayer(layer)
        circle.SetWidth(MM(0.2))
        footprint.Add(circle)
    definitions = (
        ("1", -1.905, "/RGB_R_K"),
        ("2", -0.635, "/+3V3"),
        ("3", 0.635, "/RGB_G_K"),
        ("4", 1.905, "/RGB_B_K"),
    )
    for number, x, net_name in definitions:
        item = pcbnew.PAD(footprint)
        item.SetNumber(number)
        item.SetAttribute(pcbnew.PAD_ATTRIB_PTH)
        item.SetShape(pcbnew.PAD_SHAPE_CIRCLE if number != "2" else pcbnew.PAD_SHAPE_RECTANGLE)
        item.SetSize(point(1.0, 1.0))
        item.SetDrillSize(point(0.6, 0.6))
        item.SetPosition(point(68.5 + x, 31.0))
        layers = pcbnew.LSET.AllCuMask()
        layers.AddLayer(pcbnew.F_Mask)
        layers.AddLayer(pcbnew.B_Mask)
        item.SetLayerSet(layers)
        item.SetNet(net(board, net_name))
        footprint.Add(item)
    board.Add(footprint)
    return footprint


def load_connector(board: pcbnew.BOARD, library: str, name: str, reference: str,
                   value: str, x: float, y: float, angle: float,
                   pin_nets: dict[str, str]) -> pcbnew.FOOTPRINT:
    footprint = pcbnew.FootprintLoad(str(KICAD_FOOTPRINTS / f"{library}.pretty"), name)
    if footprint is None:
        raise FileNotFoundError(f"Unable to load {library}:{name}")
    footprint.SetReference(reference)
    footprint.SetValue(value)
    footprint.SetPosition(point(x, y))
    footprint.SetOrientationDegrees(angle)
    make_footprint_self_contained(footprint)
    for number, net_name in pin_nets.items():
        pad(footprint, number).SetNet(net(board, net_name))
    board.Add(footprint)
    return footprint


def track(board: pcbnew.BOARD, start: pcbnew.VECTOR2I, end: pcbnew.VECTOR2I,
          net_item: pcbnew.NETINFO_ITEM, layer: int = pcbnew.F_Cu, width: float = 0.2) -> None:
    if start == end:
        return
    item = pcbnew.PCB_TRACK(board)
    item.SetStart(start)
    item.SetEnd(end)
    item.SetWidth(MM(width))
    item.SetLayer(layer)
    item.SetNet(net_item)
    board.Add(item)


def route_l(board: pcbnew.BOARD, a: pcbnew.PAD, b: pcbnew.PAD,
            layer: int = pcbnew.F_Cu, horizontal_first: bool = True, width: float = 0.25) -> None:
    start, end = a.GetPosition(), b.GetPosition()
    corner = pcbnew.VECTOR2I(end.x, start.y) if horizontal_first else pcbnew.VECTOR2I(start.x, end.y)
    track(board, start, corner, a.GetNet(), layer, width)
    track(board, corner, end, a.GetNet(), layer, width)


def add_via(board: pcbnew.BOARD, xy: tuple[float, float], net_item: pcbnew.NETINFO_ITEM) -> None:
    item = pcbnew.PCB_VIA(board)
    item.SetPosition(point(*xy))
    item.SetWidth(MM(0.5))
    item.SetDrill(MM(0.3))
    item.SetNet(net_item)
    board.Add(item)


def polyline(board: pcbnew.BOARD, net_item: pcbnew.NETINFO_ITEM, layer: int,
             coordinates: list[tuple[float, float]], width: float = 0.2) -> None:
    for start, end in zip(coordinates, coordinates[1:]):
        track(board, point(*start), point(*end), net_item, layer, width)
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

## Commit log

2026-09-01 Develop IPC-101 P0 prototype control panel
    [IPC101.kicad_pcb, IPC101.kicad_sch, IPC101_BOM.csv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]
2026-09-01 Add connected IPC-101 KiCad schematic
    [IPC101.kicad_sch, IPC101_BOM.csv]
2026-09-02 Fix IPC-101 schematic PCB synchronization
    [IPC101.kicad_sch, IPC101_BOM.csv]
2026-09-03 Update IPC-101 for 2.42-inch OLED
    [IPC101.kicad_pcb, IPC101.kicad_sch, IPC101_BOM.csv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]
2026-09-03 Repair IPC-101 PCB routing
    [IPC101.kicad_pcb]
2026-09-03 Mount 2.42 inch OLED on IPC-101
    [IPC101.kicad_pcb, IPC101.kicad_sch, IPC101_BOM.csv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]
2026-09-03 Use Crosswind OLED mounting geometry
    [IPC101.kicad_pcb, IPC101_BOM.csv, IPC101_P0_PANEL_COORDINATES.csv]
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2026-09-04 Correct IPC-101 faceplate orientation and clearance
    [CrossWind_ControlPanel_RevC_IPC101.stl, IPC101_P0_PANEL_COORDINATES.csv]
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2026-09-04 Match Crosswind nav cap to TrailBoss P504 socket
    [CrossWind_Adafruit504_Nav_Cap_RevC_IPC101.stl, IPC101_P0_PANEL_COORDINATES.csv]
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2026-09-05 Fix Crosswind control box mount access
    [CrossWind_IPC101_Control_Box_RevD_INSTALLED.stl, CrossWind_IPC101_Control_Box_RevD_PRINT.stl, CrossWind_IPC101_Control_Box_RevE_INSTALLED.stl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]
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2026-09-07 Add Rev H enclosure fit prototype with sealed-back shell and removable bracket
    [CrossWind_IPC101_Box_RevH_INSTALLED.stl, CrossWind_IPC101_Box_RevH_PRINT.stl, CrossWind_IPC101_Bracket_RevH_INSTALLED.stl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]
2026-09-07 Restore through-hole solder mask and validate replacement fabrication package
    [IPC101-B_Cu.gbl, IPC101-B_Mask.gbs, IPC101-B_Paste.gbp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]
2026-09-08 Shift faceplate OLED 8 mm right for enclosure clearance
    [CrossWind_ControlPanel_RevD_OLED_8mm_Right_IPC101.stl, IPC101_RevD_FACEPLATE_COORDINATES.csv]
2026-09-08 Add TPU button membrane test coupons and clamp frames
    [ARM_PULL_CLAMP_FRAME_RIGID.stl, ARM_PULL_TPU_WEB_0.4mm.stl, ARM_PULL_TPU_WEB_0.6mm.stl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]
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2026-09-20 Document IPC-101 enclosure redesign direction and carrier stack
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2026-09-21 Add Rev H1 enclosure correcting open bottom and external nubs
    [CrossWind_IPC101_Control_Box_RevH1_TESTFIT.scad]
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2026-09-21 Correct enclosure baseline to synced Rev H bracket assembly
2026-09-21 Develop IPC-101 Rev I enclosure and internal carrier
    [CrossWind_IPC101_Box_RevI_INSTALLED.stl, CrossWind_IPC101_Box_RevI_PRINT.stl, CrossWind_IPC101_Carrier_RevI_INSTALLED.stl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]
2026-09-21 Preserve supplied IPC-101 R3 rear carrier reference files
    [IPC101_RevA_RearCarrier_R3.scad, IPC101_RevA_RearCarrier_R3.stl]
2026-09-21 Fix Rev I front aperture membrane and verify exported opening
    [CrossWind_IPC101_Box_RevI_INSTALLED.stl, CrossWind_IPC101_Box_RevI_PRINT.stl]
2026-09-21 Integrate original R3 carrier with Rev I.1 cradle and service bezel
    [CrossWind_IPC101_Bezel_RevI1_INSTALLED.stl, CrossWind_IPC101_Bezel_RevI1_PRINT.stl, CrossWind_IPC101_Box_RevI1_INSTALLED.stl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]
2026-09-21 Verify supplied M.4 faceplate against Rev I.1 assembly
    [CrossWind_IPC101_Faceplate_RevM4.scad, CrossWind_IPC101_Faceplate_RevM4_BLACK_AMS.stl, CrossWind_IPC101_Faceplate_RevM4_WHITE_PETGHF.stl]
2026-09-21 Archive superseded enclosure revisions and clarify current print files
    [CrossWind_IPC101_Box_RevI_INSTALLED.stl, CrossWind_IPC101_Box_RevI_PRINT.stl, CrossWind_IPC101_Carrier_RevI_INSTALLED.stl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]
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2026-09-21 Add printable XA1E STOP side pod for I1 control panel
    [CrossWind_IPC101_STOP_Coupon_S1_INSTALLED.stl, CrossWind_IPC101_STOP_Coupon_S1_PRINT.stl, CrossWind_IPC101_STOP_Cover_S1_INSTALLED.stl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]
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2026-09-21 Flag reported M4 button misalignment before faceplate reprint
2026-09-21 Record STOP coupon actuation interference and hold pod print
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2026-09-21 Record measured button positions and add N1 alignment strip
    [CrossWind_IPC101_Button_Check_N1_PRINT.stl]
2026-09-21 Correct N1 faceplate button placement and tree logo for reprint
    [CrossWind_IPC101_Faceplate_RevN1.scad, CrossWind_IPC101_Faceplate_RevN1_BLACK_AMS.stl, CrossWind_IPC101_Faceplate_RevN1_WHITE_PETGHF.stl]
2026-09-21 Add measured R1 labeled button caps and matching N1.1 faceplate
    [CrossWind_IPC101_ARM_Cap_R1_BLACK_AMS.stl, CrossWind_IPC101_ARM_Cap_R1_WHITE_PETGHF.stl, CrossWind_IPC101_Button_Caps_R1.scad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]
2026-09-22 Trace supplied Iron Pine tree into N1.2 faceplate artwork
    [CrossWind_IPC101_Faceplate_RevN12.scad, CrossWind_IPC101_Faceplate_RevN12_BLACK_AMS.stl, CrossWind_IPC101_Faceplate_RevN12_WHITE_PETGHF.stl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]
2026-09-22 Add compact tree and IPO faceplate branding option N1.3
    [CrossWind_IPC101_Faceplate_RevN13.scad, CrossWind_IPC101_Faceplate_RevN13_BLACK_AMS.stl, CrossWind_IPC101_Faceplate_RevN13_WHITE_PETGHF.stl]
2026-09-22 Record P504 directional restriction and add 8 mm fit coupon
    [CrossWind_IPC101_P504_Clearance_R1_8mm_PRINT.stl]
2026-09-22 Enlarge P504 aperture to 8mm in N1.4 faceplate
    [CrossWind_IPC101_Faceplate_RevN14.scad, CrossWind_IPC101_Faceplate_RevN14_BLACK_AMS.stl, CrossWind_IPC101_Faceplate_RevN14_WHITE_PETGHF.stl]
2026-09-22 Add LED bubble and panel aperture fit-test samples
    [CrossWind_IPC101_LED_R1_Bubble_1_Bore5.3_PRINT.stl, CrossWind_IPC101_LED_R1_Bubble_2_Bore5.5_PRINT.stl, CrossWind_IPC101_LED_R1_Bubble_3_Bore5.7_PRINT.stl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]
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2026-09-22 Organize enclosure CAD by component and update tooling paths
    [CrossWind_IPC101_ARM_Cap_R1_BLACK_AMS.stl, CrossWind_IPC101_ARM_Cap_R1_WHITE_PETGHF.stl, CrossWind_IPC101_Bezel_RevI1_INSTALLED.stl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]
2026-09-22 Add removable top STOP roof R1 fit prototype
    [CrossWind_IPC101_Top_STOP_Base_R1_INSTALLED.stl, CrossWind_IPC101_Top_STOP_Base_R1_PRINT.stl, CrossWind_IPC101_Top_STOP_Pilot_Coupon_R1_INSTALLED.stl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]
2026-09-22 Prototype rear harness tunnel and plywood retaining collar
    [CrossWind_IPC101_Rear_Tunnel_Base_R1_INSTALLED.stl, CrossWind_IPC101_Rear_Tunnel_Base_R1_PRINT.stl, CrossWind_IPC101_Rear_Tunnel_Bore_Ring_R1_PRINT.stl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]
2026-09-25 Fix top STOP roof insertion and twist clearance with R2 coupon
    [CrossWind_IPC101_Top_STOP_Access_Coupon_R2_INSTALLED.stl, CrossWind_IPC101_Top_STOP_Access_Coupon_R2_PRINT.stl, CrossWind_IPC101_Top_STOP_Roof_R2_INSTALLED.stl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]
2026-09-25 Add paired STOP release access and support-free R3 fit coupon
    [CrossWind_IPC101_Top_STOP_Release_Coupon_R3_INSTALLED.stl, CrossWind_IPC101_Top_STOP_Release_Coupon_R3_PRINT.stl, CrossWind_IPC101_Top_STOP_Roof_R3_INSTALLED.s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]
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2026-09-25 Rotate STOP release access clockwise for R4 fit test
    [CrossWind_IPC101_Top_STOP_Release_Coupon_R4_INSTALLED.stl, CrossWind_IPC101_Top_STOP_Release_Coupon_R4_PRINT.stl, CrossWind_IPC101_Top_STOP_Roof_R4_INSTALLED.s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]
2026-09-26 Purge superseded print exports and refresh current print guide
    [CrossWind_ARM_Button_Cap_RevC_IPC101.stl, CrossWind_ControlPanel_RevC_IPC101.stl, CrossWind_ControlPanel_RevD_OLED_8mm_Right_IPC101.stl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]
